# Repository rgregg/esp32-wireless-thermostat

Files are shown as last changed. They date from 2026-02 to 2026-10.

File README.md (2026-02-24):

# ESP32 Wireless Thermostat

A two-unit wireless HVAC thermostat system built on ESP32. A **controller** board wired to your furnace manages relay outputs for heating, cooling, and fan. A **touchscreen display** mounted on the wall provides the user interface. The two units communicate wirelessly over ESP-NOW and coordinate through MQTT for Home Assistant integration.

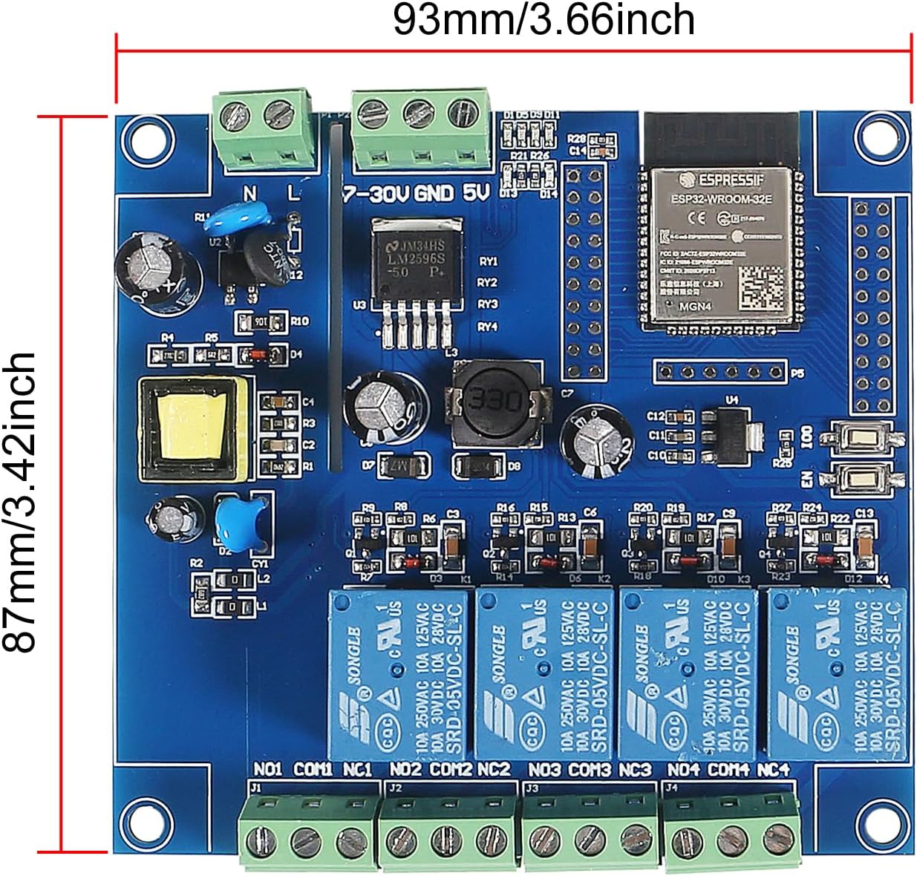
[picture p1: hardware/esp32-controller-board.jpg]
Controller Board


## Features

- **Touchscreen UI** — 4.3" 800x480 capacitive display with home, fan, mode, and settings pages plus an idle screensaver
- **Wireless** — ESP-NOW for fast local command/telemetry between controller and display; no wiring between the two units
- **Home Assistant** — MQTT discovery automatically registers a climate entity with mode, fan, and target temperature controls
- **Safety first** — Failsafe timeout, relay interlocking, minimum run/off timers, HVAC lockout, and command sequence validation
- **OTA updates** — ArduinoOTA, web-based upload (`/update`), and automatic firmware rollback if connectivity isn't restored within 3 minutes
- **Weather display** — Outdoor temperature and conditions via PirateWeather API
- **Runtime configuration** — Web UI at `/config` and MQTT topics for WiFi, MQTT, ESP-NOW, display, and weather settings without reflashing
- **Filter tracking** — Accumulated fan runtime with reset capability
- **Temperature compensation** — Configurable offset for the indoor sensor
- **BLE WiFi provisioning** — Automatic fallback to Bluetooth provisioning if no stored WiFi credentials are found
- **Desktop simulators** — SDL2-based previews of both the controller and thermostat display for development without hardware

## Hardware

### Controller Unit

Installed near the furnace. Connects to HVAC wiring via relay outputs (heat, cool, fan, spare).

| Component | Link |
|---|---|
| ESP32 4-relay controller board | [Amazon](https://www.amazon.com/dp/B0DNYYXQ3X) |
| AC-to-DC power supply (furnace side) | [Amazon](https://www.amazon.com/dp/B08Q81Y8NM) |
| 3D-printable enclosure | [`enclosures/controller_v20.f3d`](enclosures/controller_v20.f3d) |

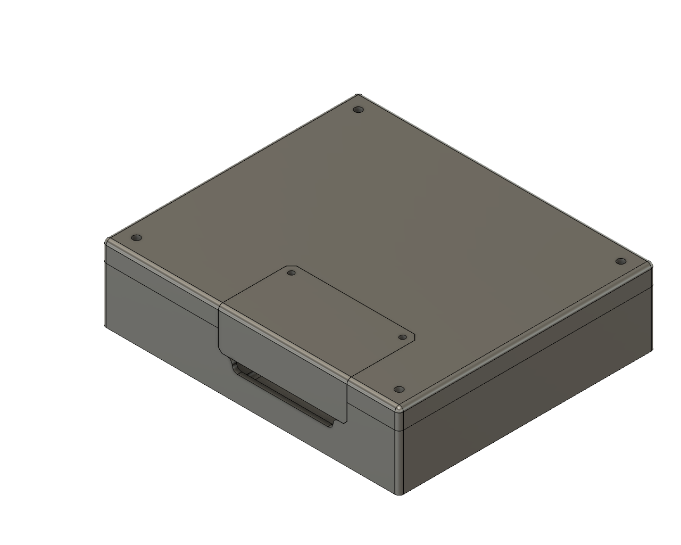
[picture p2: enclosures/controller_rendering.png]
Controller Enclosure


### Thermostat Display Unit

Wall-mounted touchscreen with built-in temperature/humidity sensor.

| Component | Link |
|---|---|
| ESP32-S3 4.3" capacitive touch display | [Amazon](https://www.amazon.com/dp/B0CLGCMWQ7) |
| AHT10/AHT20 temperature & humidity sensor | [Amazon](https://www.amazon.com/dp/B092495GZJ) |
| 3D-printable enclosure | [`enclosures/display_v27.f3d`](enclosures/display_v27.f3d) |

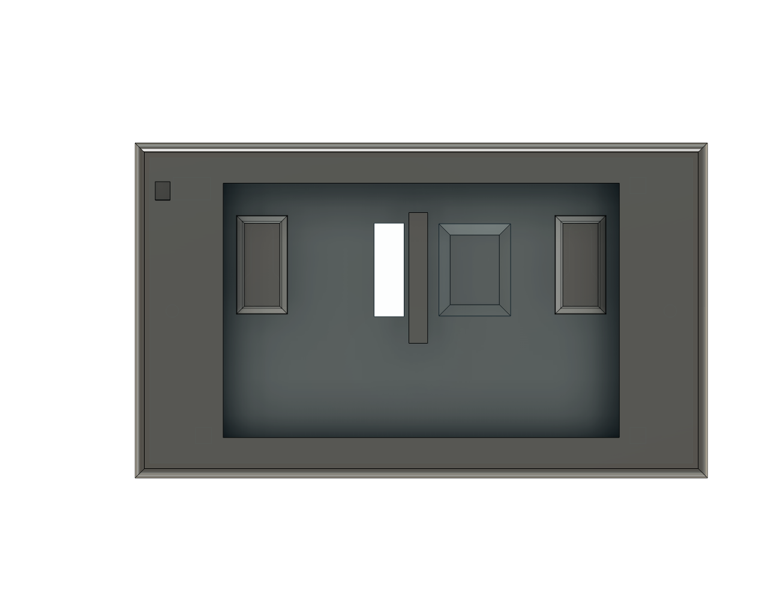
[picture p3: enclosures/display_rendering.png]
Display Enclosure


The sensor connects to the display board via I2C (SDA=GPIO 18, SCL=GPIO 17). See [`docs/hardware-requirements.md`](docs/hardware-requirements.md) for full GPIO pinouts and wiring details.

> **Enclosure note:** For fire safety compliance, print enclosures with a UL-listed filament such as Prusament PETG V0 or equivalent V0-rated material.

## Getting Started

### Prerequisites

- [PlatformIO](https://platformio.org/) (CLI or IDE plugin)
- An MQTT broker (e.g. Mosquitto) for Home Assistant integration
- 2.4 GHz WiFi network

### Build and Flash

```bash
# Controller firmware (ESP32)
pio run -e esp32-furnace-controller -t upload

# Thermostat display firmware (ESP32-S3)
pio run -e esp32-furnace-thermostat -t upload
```

Initial flash requires a USB connection. After that, OTA updates work over the network.

### Configuration

On first boot with no stored WiFi credentials, the thermostat display starts BLE provisioning. Use the ESP BLE Provisioning app to connect it to your network.

Once connected, configure both devices via their web UI:
- **Controller**: `http://<controller-ip>/config`
- **Display**: `http://<display-ip>/config`

Settings include WiFi, MQTT broker, ESP-NOW peer MAC and channel, temperature unit, display timeout, weather API key, and more. See [`docs/deployment-runbook.md`](docs/deployment-runbook.md) for the full configuration reference.

## MQTT & Home Assistant

Both units connect to an MQTT broker. The thermostat display publishes Home Assistant MQTT discovery messages, automatically creating a climate entity.

**Command topics** (under the controller's base topic):

| Topic | Values |
|---|---|
| `cmd/mode` | `off`, `heat`, `cool` |
| `cmd/fan_mode` | `auto`, `on`, `circulate` |
| `cmd/target_temp_c` | float (Celsius) |
| `cmd/lockout` | `0`, `1` |
| `cmd/filter_reset` | `1` |
| `cmd/sync` | `1` |

## Desktop Simulators

Both simulators run on your desktop for UI development and testing without hardware. They communicate over MQTT, so you can run them together with a local broker to test the full command/telemetry loop.

**Requirements:** SDL2 (`brew install sdl2 sdl2_ttf` on macOS) and optionally Mosquitto (`brew install mosquitto`).

```bash
# Thermostat display preview
pio run -e native-ui-preview && .pio/build/native-ui-preview/program

# Controller preview
pio run -e native-controller-preview && .pio/build/native-controller-preview/program
```

**Display simulator controls:**
| Key | Action |
|---|---|
| `W` | Cycle weather conditions |
| `[` / `]` | Adjust outdoor temperature |
| `S` | Activate screensaver |
| `D` | Wake display |

## Build Targets

| Environment | Description |
|---|---|
| `esp32-furnace-controller` | Controller firmware for ESP32 |
| `esp32-furnace-thermostat` | Display firmware for ESP32-S3 |
| `native-tests` | 37 unit tests (run with `.pio/build/native-tests/program`) |
| `native-ui-preview` | Desktop thermostat display simulator |
| `native-controller-preview` | Desktop controller simulator |

## Documentation

- [`docs/hardware-requirements.md`](docs/hardware-requirements.md) — GPIO pinouts, board specs, wiring
- [`docs/deployment-runbook.md`](docs/deployment-runbook.md) — Runtime configuration, MQTT topics, first-boot setup
- [`docs/system-spec-and-parity.md`](docs/system-spec-and-parity.md) — System specification and feature tracking
- [`docs/espnow-transport.md`](docs/espnow-transport.md) — ESP-NOW packet protocol details

## License

This project is provided as-is for personal and educational use. HVAC wiring involves line voltage — follow your local electrical codes and consult a qualified technician if needed.

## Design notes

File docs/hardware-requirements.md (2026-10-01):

# Hardware Requirements

This project runs as two separate ESP32 firmwares:
- `esp32-furnace-controller` (furnace-side controller)
- `esp32-furnace-thermostat` (touch display thermostat)

This document captures the hardware baseline required by the current codebase.

## Controller Unit (`esp32-furnace-controller`)

### Board/MCU
- ESP32 (classic) board profile compatible with PlatformIO `board = esp32dev`.
- 2.4 GHz Wi-Fi required (also used by ESP-NOW).
- Reference tested unit: ESP32 relay controller board (Amazon ASIN `B0DNYYXQ3X`).

### Power
- Reference tested furnace-side supply: AC-to-DC converter module (Amazon ASIN `B08Q81Y8NM`).
- Size/output the converter for the relay board + ESP32 load with startup margin.

### Required GPIO Outputs
The controller relay driver uses these default output pins:

| Function | GPIO |
|---|---|
| Heat relay | 32 |
| Cool relay | 33 |
| Fan relay | 25 |
| Spare relay | 26 |

Notes:
- Outputs default to active-high (`inverted = false` in `ControllerRelayIoConfig`).
- Relay outputs are software interlocked (heat: 500 ms, others: 1000 ms).
- Use an external relay/interface stage suitable for your HVAC control voltage and isolation needs.

## Thermostat Display Unit (`esp32-furnace-thermostat`)

### Board/MCU
- ESP32-S3 board profile compatible with PlatformIO `board = esp32-s3-devkitc-1`.
- 16 MB flash (matches `board_upload.flash_size = 16MB` build config).
- PSRAM required (framebuffers and LVGL draw buffers allocate in SPIRAM when available).
- Reference tested unit: DIYmalls `ESP32-8048S043C-I` 4.3" capacitive display module (Amazon ASIN `B0CLGCMWQ7`).

### Display Panel
- 800x480 RGB panel (16-bit parallel RGB interface).
- Current timing/pin map is implemented for the `ESP32-8048S043C-I` wiring used by this project.

RGB control pins:

| Signal | GPIO |
|---|---|
| DE | 40 |
| PCLK | 42 |
| VSYNC | 41 |
| HSYNC | 39 |

RGB data pins (`D0..D15`):
`45, 48, 47, 21, 14, 5, 6, 7, 15, 16, 4, 8, 3, 46, 9, 1`

### Touch Controller
- GT911 capacitive touch controller (`I2C addr 0x5D`)
- I2C bus pins: `SDA=19`, `SCL=20` (400 kHz)

### Indoor Sensor
- AHT10 temperature/humidity sensor (Amazon ASIN `B092495GZJ`)
- I2C bus pins: `SDA=18`, `SCL=17` (100 kHz)
- Firmware uses the Adafruit AHTX0 driver layer, so AHT10/AHT20-class devices are supported.

### Backlight
- PWM backlight control on `GPIO2` (LEDC, 8-bit, 250 Hz). The driver needs ~30 µs per enable pulse, so ultrasonic PWM cannot dim (black below ~80% at 25 kHz); 800 Hz whined audibly at low duty.

## Shared Requirements (Both Units)
- 2.4 GHz Wi-Fi coverage at install location.
- ESP-NOW enabled on both devices (default channel `6` on both).
- If using encrypted ESP-NOW, configure unicast peer MACs and a shared 16-byte LMK on both units.

## Enclosures (3D Print Files)
- Controller enclosure CAD: [`enclosures/controller_v20.f3d`](../enclosures/controller_v20.f3d)
- Thermostat display enclosure CAD: [`enclosures/display_v27.f3d`](../enclosures/display_v27.f3d)
- For fire compliance, print with a UL-listed filament such as Prusament PETG V0 (or equivalent UL-listed V0-rated material).

## Out of Scope in Current Firmware
The firmware currently does not prescribe:
- exact relay module part number,
- enclosure/thermal/mechanical constraints.

Those should be defined per installation and local electrical code requirements.

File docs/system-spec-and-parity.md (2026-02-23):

# System Spec And Parity Matrix

This document is the formal baseline spec for the thermostat/display + controller system, derived from the ESPHome YAML configuration, with a parity check against the current PlatformIO implementation.

## Scope

Baseline sources:
- `../esphome-sheridan/furnace-controller.yaml`
- `../esphome-sheridan/furnace-display.yaml`
- `../esphome-sheridan/lvgl-ux/ux-thermostat.yaml`
- `../esphome-sheridan/templates/esp32-8048S043C.yaml`
- `../esphome-sheridan/templates/management-defaults.yaml`
- `../esphome-sheridan/espnow/espnow-controller.yaml`
- `../esphome-sheridan/espnow/espnow-thermostat.yaml`

Port under evaluation:
- `.`

Status legend:
- `Implemented`: behavior is present and wired in current firmware.
- `Partial`: some behavior exists, but parity or wiring is incomplete.
- `Missing`: behavior is not implemented in the current port.

## Controller Spec And Parity

| ID | Requirement (from ESPHome behavior) | Status | Current implementation notes |
|---|---|---|---|
| C-01 | Accept thermostat command word and reject stale/duplicate sequence values. | Implemented | `ControllerRuntime::apply_remote_command` enforces sequence freshness (`espnow_cmd::is_newer_seq`). |
| C-02 | Track heartbeat freshness and enter failsafe after timeout (`failsafe_timeout_ms`). | Implemented | Runtime failsafe timeout implemented in `ControllerRuntime::update_failsafe`. |
| C-03 | In failsafe or lockout, all demands must be forced off. | Implemented | Runtime clears heat/cool/fan in `apply_hvac_calls` and `enforce_safety_interlocks`. |
| C-04 | Thermostat control loop must enforce min run/off/idle timing. | Implemented | `ControllerConfig` now includes min run/off/idle; state machine enforced in `ControllerRuntime`. |
| C-05 | Thermostat call logic should use deadband + overrun style behavior. | Implemented | `ControllerApp::compute_hvac_calls` uses configurable `heat_deadband/overrun` and `cool_deadband/overrun`. |
| C-06 | Fan modes: `automatic`, `always on`, `circulate`. | Implemented | Fan mode encoded/decoded and applied in runtime/app logic. |
| C-07 | Circulate scheduler should run windowed duty cycle based on period/duration minutes. | Implemented | Minute scheduler exists in `ControllerRuntime::run_minute_tasks`. |
| C-08 | Filter runtime increments while system is actively running and supports reset. | Partial | Runtime and reset are implemented; `spare_relay_4` participation is logical only (no physical output layer yet). |
| C-09 | Publish controller telemetry (`state`, `filter_runtime`, `lockout`, `mode`, `fan`, `setpoint`). | Implemented | `ControllerApp::publish` and `EspNowControllerTransport::publish_telemetry`. |
| C-10 | Relay demands must drive physical outputs on GPIO32/33/25/26 with startup-safe defaults. | Implemented | `controller_relay_io.cpp` GPIO output layer drives relay pins with startup-safe defaults. |
| C-11 | Enforce relay interlock behavior equivalent to ESPHome relay interlock group. | Implemented | Timed interlock delays enforced in relay IO layer (heat 0.5s, others 1s). |
| C-12 | Local lockout entity should remain externally controllable and reflected in telemetry/state text. | Partial | Lockout behavior exists in runtime; no Home Assistant/API entity equivalent on controller firmware yet. |
| C-13 | Preserve last-known indoor temp/humidity fallback behavior when remote values are missing. | Missing | Controller currently uses latest received values only; no persisted fallback store like ESPHome template numbers. |

## Display/Thermostat Spec And Parity

| ID | Requirement (from ESPHome behavior) | Status | Current implementation notes |
|---|---|---|---|
| D-01 | 800x480 RGB panel on 8048S043C pin/timing map. | Implemented | RGB panel config/pins/timings set in `esp32s3_thermostat_firmware.cpp`. |
| D-02 | GT911 touch input on internal I2C bus. | Implemented | GT911 read/write + LVGL indev callback wired. |
| D-03 | AHT20 temperature/humidity sensor on external I2C bus with 60s polling. | Implemented | AHT20 initialized on external I2C and polled every 60s. |
| D-04 | Local temperature compensation offset before publishing indoor temp. | Implemented | `temp_comp_c` runtime config applied in thermostat firmware before publishing indoor temperature. |
| D-05 | Local mode/fan/setpoint changes publish command word to controller. | Implemented | UI callbacks call runtime/app command publish path. |
| D-06 | Ignore remote setpoint updates for ~5s after local interaction (debounce). | Implemented | `ThermostatApp` enforces local interaction debounce window. |
| D-07 | Temperature unit preference (`fahrenheit`/`celsius`) drives conversions and UI format. | Implemented | `DisplayModel` and runtime unit handling implemented. |
| D-08 | Receive controller telemetry and map to user-visible status/mode/fan/setpoint. | Implemented | `ThermostatNode` + `ThermostatApp` + `ThermostatDisplayApp` flow implemented. |
| D-09 | LVGL pages and interactions for Home/Fan/Mode/Settings/Screensaver. | Partial | Core pages and actions implemented; UI is functional but not a 1:1 parity copy of all YAML widgets/details. |
| D-10 | Screen idle behavior: dim backlight, switch to screensaver, resume on touch. | Implemented | `ThermostatScreenController` + backlight dim/restore in firmware loop. |
| D-11 | Trigger sync/filter-reset actions from Settings UI. | Implemented | UI buttons call `request_sync` and `request_filter_reset`. |
| D-12 | Weather/outdoor data should come from Home Assistant entities. | Implemented | PirateWeather API integration polls weather directly on display firmware using configured API key + ZIP code. |
| D-13 | Display diagnostics in settings (IP/MAC/SSID/channel/RSSI/firmware). | Partial | Diagnostics expanded in settings page (IP, RSSI, firmware version, uptime); not all ESPHome YAML fields surfaced yet. |
| D-14 | On boot, request/refresh state from controller. | Partial | Runtime starts transport and receives telemetry; explicit boot-time `get_data_from_controller` equivalent is limited. |

## Transport And Integration Spec And Parity

| ID | Requirement (from ESPHome behavior) | Status | Current implementation notes |
|---|---|---|---|
| T-01 | ESP-NOW heartbeat ping/pong between controller and display. | Implemented | Both transport adapters send/consume heartbeat packets. |
| T-02 | Command word bit contract must remain stable (mode/fan/setpoint/seq/sync/filter_reset). | Implemented | Codec in `espnow_cmd_word.*` preserved and test-covered. |
| T-03 | Indoor temperature and humidity packets sent display -> controller. | Implemented | Thermostat transport publishes float-value packets. |
| T-04 | Controller telemetry packets sent controller -> display. | Implemented | Controller transport sends telemetry packet structure. |
| T-05 | Peer/channel/encryption settings should match deployed devices. | Partial | Config fields exist, but defaults are zero peer MAC until user/site config sets real values. |

## Home Assistant/Management Spec And Parity

| ID | Requirement (from ESPHome behavior) | Status | Current implementation notes |
|---|---|---|---|
| H-01 | Expose thermostat control/status to Home Assistant. | Implemented | MQTT HA discovery + climate command/state topics added in thermostat firmware. |
| H-02 | Provide local fallback management interfaces (API/web/captive portal/OTA) similar to ESPHome templates. | Partial | Web config UI and web-based OTA upload at `/update` implemented; no captive portal or ESPHome native API equivalent. |
| H-03 | Keep credentials/secrets out of repo. | Implemented | `platformio_override.ini` is ignored; example file added for local credential overrides. |

## Validation Spec

| ID | Requirement | Status | Current implementation notes |
|---|---|---|---|
| V-01 | Native tests validate codec, controller runtime/app, thermostat app, display model, screen logic. | Implemented | `native-tests` currently runs 37 tests and passes. |
| V-02 | Build matrix must pass for host + controller + display targets. | Implemented | `native`, `native-tests`, `esp32-furnace-controller`, `esp32-furnace-thermostat` pass. |
| V-03 | Hardware-in-loop verification for controller relays/display touch/panel/sensors. | Partial | `docs/hil-checklist.md` provides a manual pass/fail checklist; not yet automated. |

## Parity Summary

- `Implemented`: core safety state machine, command protocol, transport path, display runtime, HA MQTT bridge, relay GPIO layer, weather integration, temperature compensation, web config UI, and web OTA.
- `Partial`: some display diagnostics not fully surfaced, captive portal not implemented, HIL checklist exists but not automated.
- `Missing`: ESPHome native API equivalent, captive portal, persisted indoor temp fallback on controller.

## Highest-Priority Remaining Gaps

1. Close remaining LVGL settings/diagnostic parity items (full ESPHome YAML diagnostic field set).
2. Add persisted indoor temp/humidity fallback on controller (C-13).
3. Automate hardware-in-loop verification (V-03).

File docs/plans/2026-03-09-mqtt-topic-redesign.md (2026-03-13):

# MQTT Topic Redesign

> **Status: Implemented** — This design was implemented in the `mqtt-refactor` branch (Tasks 1-10).

## Problem

The current MQTT structure splits topics across three unrelated prefixes:
- `thermostat/furnace-controller` — controller state/cmd/cfg
- `thermostat/furnace-display` — display state/cmd/cfg
- `wireless_thermostat_system/devices` — peer discovery

Devices reference each other through hardcoded base topic config keys
(`display_mqtt_base_topic`, `controller_base_topic`). This is fragile,
requires manual configuration, and scatters related data across the broker.

## Design

### Unified Topic Hierarchy

All topics move under a single configurable base topic (default
`esp32-wireless-thermostat`). Each device publishes and subscribes under
its own MAC-based path:

```
{base_topic}/devices/{MAC}/
  announce              ← role, firmware version (retained)
  state/{key}           ← runtime state (retained, except packed_command)
  cfg/{key}/state       ← config values (retained)
  cfg/{key}/set         ← config updates (subscribed)
  cmd/{command}         ← commands (subscribed)
  sensor/{measurement}  ← sensor readings
```

### Controller Topics (`devices/{ctrl_MAC}/`)

Commands (subscribed):
- `cmd/mode` — "off", "heat", "cool"
- `cmd/fan_mode` — "auto", "on", "circulate"
- `cmd/target_temp_c` — float
- `cmd/lockout` — "0" or "1"
- `cmd/packed_word` — uint32 decimal string
- `cmd/sync` — "1"
- `cmd/reboot` — "1"
- `cmd/reset_sequence` — "1"
- `cmd/filter_reset` — "1"
- `cmd/primary_sensor_mac` — MAC string
- `cmd/espnow_only` — "0" or "1"

State (published, retained):
- `state/availability` — "online" (LWT: "offline")
- `state/mode`, `state/fan_mode`, `state/target_temp_c`
- `state/current_temp_c`, `state/current_humidity`
- `state/furnace_state` — "Idle", "Heating", "Cooling", etc.
- `state/lockout` — "0" or "1"
- `state/relay_heat`, `state/relay_cool`, `state/relay_fan` — "ON"/"OFF"
- `state/filter_runtime_hours`, `state/filter_change_required`
- `state/max_runtime_exceeded`
- `state/outdoor_temp_c`, `state/outdoor_condition`
- `state/firmware_version`, `state/boot_count`, `state/reset_reason`
- `state/uptime_s`, `state/free_heap_bytes`, `state/wifi_rssi`
- `state/last_mqtt_command_ms`, `state/last_espnow_rx_ms`
- `state/espnow_send_ok_count`, `state/espnow_send_fail_count`
- `state/error_mqtt`, `state/error_ota`, `state/error_espnow`
- `state/allow_ha`, `state/mqtt_enabled`, `state/espnow_enabled`
- `state/audit` — not retained

### Display Topics (`devices/{disp_MAC}/`)

Commands (subscribed):
- `cmd/reboot` — "1"
- `cmd/reset_sequence` — "1"
- `cmd/display_timeout_s` — integer
- `cmd/backlight_active_pct` — integer
- `cmd/backlight_screensaver_pct` — integer
- `cmd/temp_comp_c` — float
- `cmd/unit` — "c" or "f"

State (published, retained unless noted):
- `state/availability` — "online" (LWT: "offline")
- `state/packed_command` — uint32 (NOT retained)
- `state/command_seq` — integer (NOT retained)
- `state/mode`, `state/fan_mode`, `state/target_temp_c` — mirror of local UI
- `state/current_temp_c`, `state/current_humidity`
- `state/temp_comp_c`, `state/display_timeout_s`
- `state/backlight_active_pct`, `state/backlight_screensaver_pct`
- `state/firmware_version`, `state/boot_count`, `state/reset_reason`
- `state/uptime_s`, `state/free_heap_bytes`, `state/wifi_rssi`
- `state/wifi_ip`, `state/wifi_mac`, `state/wifi_ssid`, `state/wifi_channel`
- `state/connection_path`, `state/status`
- `state/last_mqtt_command_ms`, `state/last_espnow_rx_ms`
- `state/espnow_send_ok_count`, `state/espnow_send_fail_count`
- `state/error_mqtt`, `state/error_ota`, `state/error_espnow`

Sensor data (published):
- `sensor/temp_c` — float
- `sensor/humidity` — float

### Device Discovery & Authorization

**Announce:** Each device publishes a retained message on connect to
`{base_topic}/devices/{MAC}/announce` containing role (`controller`,
`display`, `sensor`), firmware version, and configurable device name
(from `device_name` config key).

**Controller authorization:**
- Maintains a list of authorized device MACs (existing `devices` config)
- Only accepts packed commands and sensor data from authorized MACs
- If the authorized list is empty, auto-registers the first device
  discovered via MQTT announce or ESP-NOW
- Unknown devices are ignored once any device is registered

**Display pairing:**
- Subscribes to `{base_topic}/devices/+/announce`, filters for
  `role=controller`
- Existing UI lets user select which controller to pair with
- Stores selected controller MAC in config; constructs controller topic
  path as `{base_topic}/devices/{ctrl_MAC}/...`

**Cross-device topic construction:** Both devices derive peer paths from
`{base_topic}/devices/{peer_MAC}/...`. The separate `display_mqtt_base_topic`
and `controller_base_topic` config keys are removed.

### Home Assistant Discovery

- Stays under `homeassistant/` prefix (required by HA)
- All `state_topic`, `command_topic` references in discovery payloads
  point to new `{base_topic}/devices/{MAC}/...` paths
- New config key `ha_discovery_enabled` (boolean, default `true`) to
  toggle HA discovery on/off
- `discovery_prefix` config key retained (default `homeassistant`)

### Config Key Changes

**Removed:**
- `mqtt_base_topic` — replaced by `base_topic` + device MAC
- `display_mqtt_base_topic` — replaced by peer MAC discovery
- `controller_base_topic` — replaced by peer MAC discovery
- `mqtt_client_id` — auto-generated as `{base_topic}-{MAC}`

**New:**
- `base_topic` — default `esp32-wireless-thermostat`
- `ha_discovery_enabled` — boolean, default `true`
- `device_name` — string, default auto-generated as `{role}-{last3MAC}`
  (e.g. `controller-29A9C4`, `display-55D0E8`). Used in announce payload
  and HA discovery as device display name.

**Unchanged:** WiFi, MQTT broker host/port/user/password, ESP-NOW,
OTA, weather, display settings, `discovery_prefix`, `devices`.

### What Doesn't Change

- ESP-NOW protocol (MQTT-only change)
- Packed command 24-bit word encoding
- Per-MAC sequence tracking
- Web server endpoints (`/status`, `/config`, `/update`, `/screenshot`)
- Failsafe / isolation reboot logic (monitors new paths)
- OTA rollback mechanism

### Migration

Clean break. New firmware uses only new topics. A cleanup script
(`scripts/mqtt_cleanup_old_topics.py`) clears retained messages from
the old `thermostat/furnace-controller/...`, `thermostat/furnace-display/...`,
and `wireless_thermostat_system/...` paths.

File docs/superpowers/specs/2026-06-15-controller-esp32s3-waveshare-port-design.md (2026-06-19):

# Controller Port → Waveshare ESP32-S3-ETH-8DI-8RO — Design Spec

**Date:** 2026-06-15
**Branch:** `feat/controller-esp32s3-port`
**Status:** Approved design → implementation planning

## Goal

Port the furnace **controller** firmware from the current classic-ESP32 board
(`esp32dev`, 4 MB) to the Waveshare **ESP32-S3-ETH-8DI-8RO** (CAN/PoE variant),
and use the move to fix the chronic instability we've been fighting:

- **More flash (16 MB)** → a dedicated coredump partition, so we can finally
  capture the `panic` backtrace we currently can't see (no serial, 4 MB full).
- **Wired Ethernet** → remove the marginal-WiFi link that drives the
  `task_wdt` / weather-wedge failures (controller RSSI seen as low as −92 dBm).
- **Resilience refactor** → make the furnace control path independent of the
  network so network trouble can never stop heating/cooling or crash the device.

The display is **out of scope** except for one required change (ESP-NOW peer +
channel, see §6).

## Confirmed decisions

| Decision | Choice |
|---|---|
| Scope | Port **+ coredump + resilience** (all three) |
| IP transport | **Ethernet for IP** (MQTT/HA/weather); WiFi radio used **only for ESP-NOW**, no AP association |
| HA identity | **Preserve** — override discovery device id so HA sees the same controller device |
| Digital inputs (8× DI) | **Reserved, unused** this pass (YAGNI) |
| Old board | **Kept building** via a relay-backend abstraction (working fallback throughout) |

## Target hardware

**Waveshare ESP32-S3-ETH-8DI-8RO-C** — ESP32-S3-WROOM-1U **N16R8** (CONFIRMED on
hardware: 16 MB flash, 8 MB PSRAM, MAC 3c:0f:02:cc:ee:2c).

- **Relays (8):** PCA9554 I²C expander @ `0x20`, **active-high** — **VERIFIED on
  hardware** (bring-up: relay N = bit `1<<N`; boot-safe state confirmed off). I²C `SDA=42, SCL=41`.
- **RTC:** **PCF85063** @ I²C `0x51` (same bus) — **found on hardware.** Battery/supercap
  backed timekeeping; see §7.
- **Ethernet:** W5500 over SPI — `CLK=15, MOSI=13, MISO=14, CS=16, INT=12` (RST: verify on hardware).
- **Digital inputs (8):** GPIO 4–11, `INPUT_PULLUP`, inverted, debounced (reserved, unused).
- **Misc:** RGB LED (WS2812) GPIO38, buzzer GPIO46, boot button GPIO0.
- **Power:** 7–36 V DC screw terminal, USB-C (power/flash/debug), PoE (this SKU).

## Approach

**Phased, single branch, behind a board abstraction.**

- **Phase 1 (no hardware):** resilience refactor + relay-backend abstraction +
  coredump scaffolding, developed and **unit-tested in native**. The current
  `esp32dev` controller keeps building on the GPIO backend and gains the
  resilience improvements immediately.
- **Phase 2 (on hardware):** new `esp32-furnace-controller-s3` env — PCA9554
  relay backend, W5500 Ethernet, fixed-channel ESP-NOW, coredump partition,
  identity override. Validate on the bench, then swap per the flashing runbook.

Rejected: S3-only hard switch (no fallback, can't land resilience on the current
board now); separate branch per subsystem (resilience and Ethernet both touch the
network layer → merge friction).

## Build configuration (one codebase, two boards)

Board differences are isolated behind compile-time-selected backends; everything
else is shared. Selected via PlatformIO env + build flag (e.g. `-D CONTROLLER_BOARD_S3`).

| Concern | `esp32-furnace-controller` (old, esp32dev / 4 MB) | `esp32-furnace-controller-s3` (new, S3 / 16 MB) |
|---|---|---|
| Relay backend | `GpioRelayBackend` (direct GPIO) | `Pca9554RelayBackend` (I²C @0x20) |
| IP link | `WiFiStation` backend (associates to AP) | `Ethernet` (W5500) backend |
| ESP-NOW | WiFi radio, AP-driven channel | WiFi radio, no association, pinned channel |
| Partitions | `partitions_no_spiffs.csv` (4 MB) | custom 16 MB + coredump |
| Panic-PC breadcrumb (RTC) | available | available |
| Full coredump (flash) | unavailable (no partition) | enabled |
| **Shared** | control loop, thermostat logic, resilience refactor, ESP-NOW protocol, MQTT/HA discovery, weather, relay interlock logic (`ControllerRelayIo`) | same |

Note: the networking *model* (Ethernet-for-IP + WiFi-for-ESP-NOW-only) applies to
the **new** board only; the old board has no Ethernet and necessarily keeps
WiFi-station association for IP. The `IP-link` abstraction (§2) resolves to
`WiFiStation` on the old board and `Ethernet` on the new one, keeping the MQTT/
weather layers board-agnostic.

## Design

### 1. Hardware abstraction — relays
- Introduce a `RelayBackend` interface; `ControllerRelayIo` keeps **all** its
  interlock / force-off / pending logic unchanged and calls the backend for
  `begin()` + `write_outputs()`.
- `GpioRelayBackend` — current board (direct GPIO, existing behavior).
- `Pca9554RelayBackend` — I²C @ `0x20`, active-high. **Safe init: write output
  register `0x00` BEFORE setting the config register to outputs**, so the
  input→output transition cannot momentarily energize relays (PCA9554 output
  reg POR default is `0xFF`).
- Byte-packing (relay index → bit in the output byte) extracted to a
  platform-agnostic, **unit-tested** header (per the sim/firmware split); the
  `Wire` transport stays in firmware.
- Backend selected by build flag / PlatformIO env.

### 2. Networking
- **Ethernet (W5500)** is the IP path for MQTT/HA/weather. A small **IP-link
  abstraction** lets MQTT/weather code be link-agnostic.
- **WiFi radio** is initialized in a **no-association mode pinned to a fixed
  ESP-NOW channel** (no STA join). This removes the flaky WiFi-association layer
  entirely while keeping the local ESP-NOW link to the display.
- ⚠️ **ESP-NOW channel-coordination risk:** ESP-NOW requires controller and
  display on the same radio channel. Today they match because both associate to
  the same AP. Once the controller stops associating and pins a channel, the
  **display's AP must use that channel, or the display must pin the same channel**
  (small display-side follow-up). The controller will expose the ESP-NOW channel
  as config; verify channel match at cutover. Mitigation if mismatch is a problem:
  pin the display too / move display to Ethernet later.

### 3. Resilience refactor
- **Control loop** runs at a fixed cadence with **zero network dependency**
  (read indoor temp via ESP-NOW → compare setpoint → drive relays).
- **Move MQTT connect/publish off the main path** into a dedicated network task
  (weather already is). The main loop never blocks on the network.
- **Replace `esp_restart()` recoveries with subsystem restarts.** Use a
  self-terminating network task (checks a flag and returns cleanly so TLS objects
  run their destructors) instead of `vTaskDelete` — so we recover networking
  without rebooting. Reserve reboot for truly unrecoverable states, and avoid
  rebooting mid HVAC cycle where possible.
- **Degradation tiers:** control > ESP-NOW > MQTT/HA > weather. A failure in any
  tier must not affect the tiers below it.
- **Bounded everything** (carry forward PR #32: connect/handshake/read timeouts,
  task-WDT, MQTT socket timeout) + backoff with jitter + heap budget under failure.
- **Relay fault policy:** the PCA9554 **latches relay state across a CPU reset**
  (it doesn't reset when the ESP32 does) — deliberately chosen so a watchdog
  reboot doesn't drop an active heat/cool call. Document and make explicit.

### 4. Crash diagnostics (unified — three layers)
A single crash-visibility story, layered by what each board can hold:

1. **`wdt_section` breadcrumb (existing, both boards):** names the instrumented
   blocking section (weather geocode/forecast, mqtt connect, mdns) active at a
   watchdog reset. RTC_NOINIT memory.
2. **Panic-PC breadcrumb (new, both boards):** a custom panic-handler hook stashes
   the **faulting PC + a few backtrace addresses** into RTC_NOINIT memory (survives
   panic/reset, same mechanism as the existing breadcrumb), published on next boot
   via a new `state/panic_pc` topic + HA diagnostic sensor, then cleared. Resolve
   offline with `addr2line` against the matching build `.elf` (rebuildable from the
   firmware_version git sha). Gives the **old 4 MB board** crash *localization*
   without needing a coredump partition.
3. **Full coredump (new board only):** custom 16 MB partition table with a
   dedicated coredump partition; `esp_core_dump` to flash, panic-triggered. On boot
   read the summary (PC + backtrace + registers/stack), publish over MQTT
   (`state/coredump`), then clear. The complete dump the 4 MB board can't hold.

### 5. Identity & migration
- **Override the discovery device id / base** so HA continues to see the same
  controller device — existing automations, the reboot alert, history, and
  dashboards keep working with no entity_id rework.
- **Update the display's ESP-NOW peer** to the new controller MAC (and confirm
  channel per §2).
- **Cutover:** bench-flash the new board → validate (see §6) → HVAC-off + 60 s
  settle → physically swap → verify. Old board retained as rollback.

### 6. Testing
- **Native unit tests:** relay bit-logic; resilience state machines (link up/down,
  network-task restart, degradation tiers); IP-link selection; coredump-record
  parsing; panic-PC breadcrumb encode/decode/format; **RTC time encode/decode (BCD)**.
- **Hardware validation checklist (Phase 2):** relay **safe state at power-on**
  (multimeter COM→NO before wiring to HVAC), Ethernet link + DHCP, ESP-NOW channel
  match with display, coredump capture→publish→clear round-trip, OTA on the new
  partition layout, full HVAC cycle (heat/cool/fan) with interlocks, **RTC read/set +
  survives a power-cycle (if battery-backed)**.

### 7. RTC — network-independent time (PCF85063 @ I²C 0x51)
The board has a **PCF85063A** RTC on the relay I²C bus. This is a genuine resilience
win: **the controller keeps accurate wall-clock time even with the network down**, so
time-dependent behavior doesn't depend on NTP/SNTP reachability.

- **Driver:** a small PCF85063 driver — read/set time over I²C. The **BCD ↔ struct
  encode/decode is platform-agnostic and unit-tested** (like the relay bit-logic);
  only the `Wire` transport is firmware. Also read the **oscillator-stop / low-voltage
  flag** (RTC reg) to know whether the held time is trustworthy (battery was lost).
- **Sync strategy — RTC is the local source of truth, NTP corrects it:**
  - On boot, read the RTC immediately → the controller has a valid time before any
    network comes up (no "1970" window, no waiting on SNTP).
  - When network time is available (SNTP sync), **write it back to the RTC** so the RTC
    stays accurate and survives the next reboot/outage.
  - System time (`settimeofday`) is seeded from the RTC at boot and re-disciplined by
    SNTP; the RTC is re-written on each successful SNTP sync (and periodically).
- **Uses:** time-of-day HVAC scheduling without NTP; accurate **log/diagnostic
  timestamps from boot** (incl. reboot-cause/breadcrumb timing); runtime accounting
  anchored to real time. Optionally publish `state/rtc_time` + an `rtc_ok` diagnostic.
- **Battery/backup:** the RTC only retains time across a full power-off if the board's
  RTC backup (coin cell / supercap) is populated — **verify/populate it** for cold-boot
  benefit; without it the RTC still helps across brownouts/resets and gets corrected by
  SNTP. The osc-stop flag tells us at boot whether to trust the held time.
- **Display-agnostic:** controller-only (the display gets time over ESP-NOW/MQTT as today).

## Out of scope
- Digital-input features (reserved, unused).
- RS485/CAN bus usage.
- Moving the display to Ethernet (possible later follow-up for ESP-NOW channel).
- PoE infrastructure (board supports it; power method is an install choice).

## Risks
- **ESP-NOW channel mismatch** once the controller stops associating (see §2) —
  highest-attention item at cutover.
- **Exact SKU pin differences** (CAN variant) — re-verify pin map on arrival.
- **PCA9554 power-on / pre-I²C window** — board pull resistors decide raw
  power-on relay state; confirm via schematic + bench before HVAC wiring.
- Panic root cause still unknown (post-deploy `reset_reason=panic`, `wdt_section=none`,
  no backtrace available); the coredump partition is the instrument to find it, not
  a guaranteed fix.

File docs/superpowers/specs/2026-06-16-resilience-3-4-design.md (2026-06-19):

# Resilience Increments 3 & 4 — Design

> **Status: DRAFT for review.** Touches the LIVE, SHARED controller firmware
> (`src/esp32_controller_main.cpp` + `controller_*`), so it affects the production
> esp32dev controller as well as the S3 port. Get sign-off before implementing.

Grounded in a concurrency analysis of the current firmware (2026-06-16). Headline finding:
the controller's `app()` state is **already mutated concurrently without locking** — the
ESP-NOW receive callback (WiFi-stack task) calls `app().on_command_word/on_heartbeat/...`
directly, racing `loop()->tick()`. It survives only because the writes are word-atomic
scalars that self-correct each tick. There is **no reusable serialization mechanism** to
borrow, and MQTT's mutations are *worse* race candidates (an Arduino `String`
`g_disp_availability`, the device-registry array, and a multi-field shadow set).

This work is **three distinct pieces**, ordered by value/risk:

---

## Piece A — Weather wedge: PREVENT it (small, low-risk, high-value)  [was "Inc 4a"]

**Problem:** `ctrl_poll_weather` reboots (`esp_restart`) when the weather task genuinely
hangs. The hang is a **TLS handshake** that ignores the HTTP timeouts: `http.setTimeout`
and `http.setConnectTimeout` are set (4 s), but **`WiFiClientSecure::setHandshakeTimeout()`
is never called**, and there's no socket read timeout — so `mbedtls_ssl_handshake` can
block indefinitely.

**Fix (prevention, not recovery):** in `ctrl_fetch_zip_coordinates` and
`ctrl_fetch_pirateweather_current`, set `client.setHandshakeTimeout(kCtrlHttpTimeoutMs/1000)`
and a socket timeout before the request. The `WiFiClientSecure`/`HTTPClient` objects are
**stack-local**, so once every blocking call honors a timeout the function *returns*,
destructors run, no leak — the task can no longer wedge. The watchdog reboot becomes
unreachable (we keep it as a backstop but it should never fire).

**Why first:** ~10 lines, no concurrency, and (like the weather-wedge sign fix) it's shared
so production benefits immediately. Retires the genuine-hang reboot path.

**Risk:** low. Validate by confirming weather still fetches normally on the bench (needs a
valid PirateWeather key + zip configured), and that a forced-unreachable TLS host times out
and returns instead of hanging.

---

## Piece B — MQTT off the control loop via a command queue (large, the real Inc 3)

**Goal:** the control loop (core 1) must never block on MQTT connect (≤5 s), the 19-subscribe
+ discovery/state publish burst, or `PubSubClient.loop()`. Move all MQTT I/O to its own
FreeRTOS task; keep **all** `app()` mutation on the loop task.

**Approach — command queue (NOT a mutex):**
```
New MQTT task (core 0, alongside weather/web):
  owns g_ctrl_mqtt: ensure_connected / loop() / subscribe / publish.
  ctrl_mqtt_on_message: PARSE ONLY -> xQueueSend(g_ctrl_cmd_q, &CtrlCommand{...})

loop() task (core 1, unchanged role):
  at top of loop: drain g_ctrl_cmd_q (non-blocking) -> apply via the existing app()
    mutators + shadow/registry updates (single-threaded, same site as tick()).
  g_controller->tick(); g_relay_io.apply();   // unchanged — still the ONLY mutator site
```
- `CtrlCommand` = small POD tagged union (mode/fan/setpoint/lockout/windows/packed_word/
  heartbeat/indoor_temp/indoor_humidity/sync/reset_seq/...). The MQTT handler becomes a thin
  topic→command parser; the *application* logic stays where it is, just invoked from the
  drain step.
- Outbound publishes (state, discovery, announce) become "enqueue outbound" handled by the
  MQTT task — removes today's reentrant `publish()`-from-inside-its-own-callback.
- Queue depth ~16, with a dropped-command counter surfaced in telemetry (a full queue is a
  diagnosable event, never silent corruption).

**Why a queue beats a mutex (furnace-safety):** `tick()`/`compute_hvac_calls()` never see a
half-applied command (no relay glitch from torn state); FIFO preserves command ordering; the
`command_sources_` seq-dedup stays correct because it's touched from one task; and we avoid
taking a lock inside the ESP-NOW recv context (which could stall WiFi RX / invert priority
when loop holds it during an NVS write in `tick()`). `ControllerApp`/`Runtime` need **zero**
locking changes.

**Optional follow-up (not required):** route the ESP-NOW recv callback through the *same*
queue to finally retire the pre-existing ESP-NOW race. Strictly additive.

**Risk:** medium-high (it's the relay-control hot path). Mitigate with the queue design
(keeps mutation single-threaded), incremental rollout, and heavy review. Validate on bench:
commands (HA/MQTT) still apply correctly and promptly; broker outage no longer stalls the
control loop; relay decisions keep ticking during an MQTT publish burst.

---

## Piece C — Isolation reboot: recover-without-reboot (medium)  [was "Inc 4b"]

**Problem:** `loop()` calls `esp_restart()` when MQTT && ESP-NOW are both down >15 min.
**Fix:** fold this into the existing `NetworkRecoveryPolicy` escalation ladder. Add an
ESP-NOW re-init action (`esp_now_deinit()` + `EspNowControllerTransport::begin()` — re-reg
callbacks, re-add peers; `instance_`/`initialized_` already reset in `begin()`), and on
prolonged isolation escalate: MQTT reconnect → cycle ESP-NOW (+ WiFi reassoc on classic /
lwIP self-heal on Ethernet) → **only then** reboot as a true last resort. The
`RestartSubsystem` rung already exists; this wires ESP-NOW re-init into it and replaces the
blunt 15-min `esp_restart` with "restart subsystems once, reboot only if that fails."

**Risk:** medium (network re-init). Validate on bench: force prolonged isolation, confirm
ESP-NOW re-inits and recovers in place without a reboot; confirm a genuine unrecoverable
case still eventually reboots.

---

## Recommended sequence
1. **Piece A** (weather TLS handshake timeout) — quick, low-risk, ships to production now.
2. **Piece B** (MQTT command queue) — the headline; do it carefully with per-task review.
3. **Piece C** (isolation subsystem-restart) — builds on the recovery policy.

Each piece is independently shippable and independently testable on the bench (board on the
isolated test broker, ESP-NOW peer permitting for C).

## Open questions for review
1. **Scope/sequence:** do all three, or start with A (+ maybe C) and defer the larger B?
2. **MQTT task core:** core 0 (with weather/web, keeps control alone on core 1 —
   recommended) or core 1?
3. **Production rollout:** ship Piece A to prod (like the weather-wedge fix) once done, or
   batch all three behind the S3 port?

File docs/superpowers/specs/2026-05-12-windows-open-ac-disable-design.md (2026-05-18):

# Windows Open A/C Disable — Design

**Date:** 2026-05-12
**Status:** Approved — ready for implementation plan
**Scope:** Controller firmware, thermostat display firmware, sim

## Summary

Add a new boolean state, `windows_open`, owned by Home Assistant and pushed to the controller over MQTT. While the signal is active the controller suppresses cooling demand only — heat, fan, mode/setpoint changes, and all other HVAC behavior continue normally. The thermostat display surfaces a "Windows Open" message in the status line **only when the active mode is Cool**.

## Motivation

When a user opens windows/doors during cooling season, running the A/C is wasteful and uncomfortable. Home Assistant already aggregates door/window sensor state. This feature gives HA a clean, dedicated lever to disable cooling without forcing the user (or an automation) to toggle the whole HVAC mode off — which would also stop heating during shoulder seasons or unrelated cases.

## Design Decisions

| Question | Decision | Rationale |
|---|---|---|
| Source of signal | MQTT command from HA only | Mirrors existing `hvac_lockout` pattern; no controller hardware change. |
| Behavior during active cooling | Honor min-run-time, then idle | Avoids short-cycling compressor on brief door openings. |
| Scope of suppression | Cooling only | Per user request. Fan (circulate/always-on) and heat continue normally. |
| Display priority | Only show "Windows Open" when active mode is Cool | When in Heat/Off, the windows-open state is irrelevant to the user's current intent. |
| State persistence | None on controller | HA publishes the command as a retained MQTT topic; controller picks it up on reconnect. |
| Furnace state code | No new code | Suppressed-cooling-Idle is still functionally Idle; flag rides separately on snapshot. |

## Architecture

### Data flow

```
HA windows/doors aggregation
        │
        │ MQTT: {base}/devices/{ctrl_mac}/cmd/windows_open  (retained)
        ▼
Controller (ESP32)
  ControllerApp::set_windows_open(bool)
        │
        ▼
  ControllerRuntime::windows_open_  ──► suppresses cool_call in apply_hvac_calls()
        │
        │ Published in retained state JSON, included in ESP-NOW snapshot
        ▼
Thermostat Display
  parses windows_open into mirrored snapshot
        │
        ▼
  furnace_state_text() returns "Windows Open" when mode==Cool and flag set
```

### Components changed

**Shared (`include/`):**
- `thermostat_types.h` — `ThermostatSnapshot` gains `bool windows_open = false`.
- `espnow_cmd_word.h` — snapshot serializer gains one bit for `windows_open`. If no free bit exists in the current packed word, this becomes a protocol-version bump — both controller and display firmwares must be flashed in lockstep. Implementation plan must verify bit availability first.

**Controller (`src/controller/`, `include/controller/`):**
- `controller_runtime.h/.cpp`
  - New field `bool windows_open_ = false`.
  - New methods `void set_windows_open(bool)` and `bool windows_open() const`.
  - `apply_hvac_calls(now, heat_call, cool_call)`: at function entry, force `cool_call = false` if `windows_open_` is true. Existing min-run-time logic in the `Cooling` branch handles graceful shutdown.
  - `snapshot()` populates `s.windows_open`.
  - State transitions audit-logged: `"windows_open: on/off [mqtt]"`.
- `controller_app.h/.cpp` — thin pass-through `set_windows_open(bool)`.

**Controller firmware (`src/esp32_controller_main.cpp`):**
- Subscribe and handle new MQTT command topic `cmd/windows_open` (gated by `ha_allowed`, alongside `cmd/lockout`).
- Add `"windows_open": true/false` to retained runtime-state JSON.
- Add status-page HTML row "Windows Open".
- Publish HA MQTT discovery for a `switch` entity (mirroring `hvac_lockout` discovery) so HA can both drive and observe the value.

**Display (`src/thermostat/`, `include/thermostat/`):**
- `thermostat_ui_state.h/.cpp` — `furnace_state_text(...)` gains parameter `bool windows_open` and parameter `FurnaceMode mode` (or accepts the full snapshot — see plan). Returns `"Windows Open"` when `mode == FurnaceMode::Cool && windows_open` and no higher-priority state applies.
- MQTT subscriber on display parses `windows_open` from controller state JSON.
- ESP-NOW receiver path stores the bit into the mirrored snapshot.

**Sim (`src/sim/controller_preview.cpp`):**
- Toggle button for `windows_open`.
- Parse `cmd/windows_open` on the sim's MQTT bridge.
- Status overlay shows windows-open status (parity with lockout).

### Status text priority (display)

Updated order in `furnace_state_text`:

```
1. Failsafe        → "Failsafe"
2. Locked Out      → "Locked Out"
3. Not Connected   → "Not Connected"
4. mode==Cool && windows_open
                   → "Windows Open"
5. (existing state-code switch: Idle, HeatMode, HeatOn, CoolMode,
    CoolOn, FanOn, HeatWait, CoolWait, Error)
```

If `windows_open` is true but the user is in Heat or Off mode, the status reads as it would today (no "Windows Open" text). If a compressor is still finishing its min-run-time after `windows_open` goes true, the user briefly sees `"Cool on"`. Once cooling idles, the text transitions to `"Windows Open"`.

### Cooling suppression — exact semantics

In `ControllerRuntime::apply_hvac_calls(now_ms, heat_call, cool_call)`:

```cpp
if (windows_open_) {
  cool_call = false;
}
```

This goes **after** the existing `failsafe_active_ || hvac_lockout_` early-return (so those still force full idle) and **before** the state machine switch. Effect:

- **HvacState::Cooling**: existing `!cool_call && min_run_done` branch idles the compressor once min-run elapses. While min-run is unmet, cooling continues — by design.
- **HvacState::Idle**: re-entry into Cooling requires `cool_call == true`, which it never will be while `windows_open_` is set.
- **HvacState::Heating**: untouched.
- Fan-circulate logic (later in tick) is untouched and continues to run.

## Testing

Native unit tests (`src/tests/test_controller_runtime.cpp`):
1. `cool_call` is suppressed when `windows_open` is set; runtime stays in Idle.
2. `heat_call` is unaffected when `windows_open` is set.
3. Active Cooling honors min-run-time before idling on `windows_open=true`.
4. Cannot re-enter Cooling while `windows_open=true`, even after min-off-time has elapsed.
5. Fan-circulate continues to run while `windows_open=true` in Cool mode.
6. Snapshot reflects `windows_open` correctly across set/clear.

Display unit tests (`thermostat_ui_state`):
1. `"Windows Open"` returned when `mode == Cool && windows_open == true` and no higher-priority state active.
2. Higher-priority states (Failsafe, Locked Out, Not Connected) override.
3. Heat or Off mode with `windows_open == true` returns normal mode/state text.

Integration (manual / sim):
- Toggle windows-open in sim while in Cool mode; observe display status flip and compressor idle after min-run.
- HA discovery surfaces the new switch entity.

## Out of Scope

- Persistence of `windows_open` across controller reboot (HA's retained MQTT topic handles this).
- Per-zone or multiple window-sensor handling (HA aggregates upstream).
- Automatic mode switching (we never modify the user's mode selection).
- Suppressing fan when windows are open.
- Adding `windows_open` to the audit-log-only diagnostics; standard transition audit lines are sufficient.

## Open Items for Implementation Plan

1. Verify free bit in `espnow_cmd_word.h` packed snapshot word. If none, design the protocol-version bump and coordinated rollout (controller + display flashed together).
2. Confirm exact `furnace_state_text` signature change — pass `bool windows_open` + `FurnaceMode mode` as additional params, or refactor the function to take a `ThermostatSnapshot` + connection bool. Latter is cleaner; affects all callers.
3. HA discovery payload shape for `switch` entity (copy `hvac_lockout` discovery as template).

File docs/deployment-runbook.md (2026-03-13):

# Deployment Runbook

## Defaults
- MQTT host defaults to `mqtt.lan` on both devices.
- MQTT username/password default to empty.
- MQTT base topic defaults to `esp32-wireless-thermostat`. Each device publishes under `{base_topic}/devices/{MAC}/...` where `{MAC}` is the 6-character hex suffix of the device WiFi MAC address (e.g., `29A9C4`).
- ESP-NOW default channel is `6` on both devices.
- ESP-NOW default LMK is set on both devices (same 16-byte key in hex).
- ESP-NOW peer MAC default is broadcast (`FF:FF:FF:FF:FF:FF`), which keeps multicast fallback.
  - Note: ESP-NOW encryption requires a unicast peer MAC; with broadcast peer, traffic is unencrypted.
  - To enforce allowed-device communication and encrypted ESP-NOW traffic, set `espnow_peer_mac` to the other device's MAC on both devices.

## Flashing Firmware

### OTA (preferred)
- Controller: `curl -F "firmware=@firmware.bin" http://<controller-ip>/update`
- Display: `curl -F "firmware=@firmware.bin" http://<display-ip>/update`
- Both also support ArduinoOTA (hostname-based, may have password set).

### Serial
For initial flashing or recovery when OTA is unavailable.

**Display (ESP32-S3)** — auto-reset works:
```
esptool.py --chip esp32s3 --port /dev/<display-serial-port> --baud 460800 \
  --no-stub --before default-reset --after hard-reset \
  write_flash 0x10000 firmware.bin
```

**Controller (ESP32)** — auto-reset does NOT work; manually enter bootloader
by holding BOOT, pressing RESET, then releasing BOOT:
```
esptool.py --chip esp32 --port /dev/<controller-serial-port> --baud 460800 \
  --no-stub --before default-reset --after hard-reset \
  write_flash 0x10000 firmware.bin
```

> **Note:** The stub flasher fails at 921600 baud on both devices. Use
> `--no-stub` with 460800 baud.

## First Boot
1. Flash controller and display firmware.
2. Join both devices to WiFi.
3. Confirm controller connects to MQTT at `mqtt.lan:1883`.
4. Open controller web UI (`http://<controller-ip>/`) for unified settings.
5. Verify display status appears in the controller UI and apply display settings there.

## Runtime Management
- Controller local config: `http://<controller-ip>/config`
- Controller reboot endpoint: `POST http://<controller-ip>/reboot`
- Controller web OTA upload: `http://<controller-ip>/update`
- Display local fallback config: `http://<display-ip>/config`
- Display reboot endpoint: `POST http://<display-ip>/reboot`
- Display web OTA upload: `http://<display-ip>/update`
- Display screenshot: `http://<display-ip>/screenshot`
- MQTT path smoke verifier (with broker + both devices online):
  - `python3 scripts/mqtt_path_smoke.py --host mqtt.lan --ctrl-mac <CTRL_MAC> --disp-mac <DISP_MAC>`
- Old topic cleanup (one-time after migration):
  - `python3 scripts/mqtt_cleanup_old_topics.py --host mqtt.lan`
- MQTT reboot commands:
  - Controller: publish `1` to `esp32-wireless-thermostat/devices/<CTRL_MAC>/cmd/reboot`
  - Display: publish `1` to `esp32-wireless-thermostat/devices/<DISP_MAC>/cmd/reboot`
- Sequence recovery command (no reboot required):
  - Publish `1` to `esp32-wireless-thermostat/devices/<CTRL_MAC>/cmd/reset_sequence`
  - Controller resets its command sequence filter and forwards reset to display.

## Release Artifacts
- Build both firmware binaries with one command:
  - `scripts/build_release_artifacts.sh`
- Artifacts are written to `dist/releases/<git-describe-version>/`.
- Naming format:
  - `esp32-furnace-controller-<version>.bin`
  - `esp32-furnace-thermostat-<version>.bin`
- Build metadata is recorded in `build-info.txt`, and `SHA256SUMS` is generated when `shasum` is available.
- The GitHub Releases workflow automatically attaches firmware binaries to tagged releases.

## Runtime Config Contract

Config keys are set via MQTT at `{base_topic}/devices/{MAC}/cfg/<key>/set` and current values are published at `{base_topic}/devices/{MAC}/cfg/<key>/state`.

### Controller keys
| Key | Type | Default | Accepted values/range | Reboot required |
| --- | --- | --- | --- | --- |
| `wifi_ssid` | string | `""` | any | no |
| `wifi_password` | string (secret) | `""` | any | no |
| `mqtt_host` | string | `mqtt.lan` | any hostname/IP | no |
| `mqtt_port` | integer | `1883` | `1..65535` | no |
| `mqtt_user` | string | `""` | any | no |
| `mqtt_password` | string (secret) | `""` | any | no |
| `base_topic` | string | `esp32-wireless-thermostat` | any | no |
| `device_name` | string | auto-generated (`controller-{MAC}`) | any | no |
| `ha_discovery_enabled` | boolean string | `1` | `0`, `1` | no |
| `ota_hostname` | string | `esp32-furnace-controller` | any | no |
| `ota_password` | string (secret) | `""` | any | no |
| `espnow_channel` | integer | `6` | `1..14` | yes |
| `espnow_peer_mac` | string | `FF:FF:FF:FF:FF:FF` | MAC format expected | yes |
| `espnow_lmk` | string (secret) | `a1b2c3d4e5f60718293a4b5c6d7e8f90` | 32 hex chars expected | yes |

### Thermostat (display) keys
| Key | Type | Default | Accepted values/range | Reboot required |
| --- | --- | --- | --- | --- |
| `wifi_ssid` | string | `""` | any | no |
| `wifi_password` | string (secret) | `""` | any | no |
| `mqtt_host` | string | `mqtt.lan` | any hostname/IP | no |
| `mqtt_port` | integer | `1883` | `1..65535` | no |
| `mqtt_user` | string | `""` | any | no |
| `mqtt_password` | string (secret) | `""` | any | no |
| `base_topic` | string | `esp32-wireless-thermostat` | any | no |
| `device_name` | string | auto-generated (`display-{MAC}`) | any | no |
| `ha_discovery_enabled` | boolean string | `1` | `0`, `1` | no |
| `paired_controller_mac` | string | `""` | 6-char hex MAC suffix | no |
| `discovery_prefix` | string | `homeassistant` | any | no |
| `pirateweather_api_key` | string (secret) | `""` | any | no |
| `pirateweather_zip` | string | `""` | ZIP string | no |
| `display_timeout_s` | integer | `300` | clamped to `30..600` | no |
| `temp_comp_c` | float | `0.0` | any float | no |
| `temperature_unit` | string | `c` | `c`,`f`,`celsius`,`fahrenheit` | no |
| `ota_hostname` | string | `esp32-furnace-thermostat` | any | no |
| `ota_password` | string (secret) | `""` | any | no |
| `espnow_channel` | integer | `6` | `1..14` | yes |
| `espnow_peer_mac` | string | `FF:FF:FF:FF:FF:FF` | MAC format expected | yes |
| `espnow_lmk` | string (secret) | `a1b2c3d4e5f60718293a4b5c6d7e8f90` | 32 hex chars expected | yes |
| `controller_timeout_ms` | integer | `30000` | `1000..600000` | yes |

## Weather Provider (Display)
- Weather is sourced from PirateWeather API polling on the display firmware.
- Configure both of these display runtime config keys:
  - `pirateweather_api_key`
  - `pirateweather_zip` (US ZIP code)
- You can set display config either from:
  - Controller unified UI: `http://<controller-ip>/` (Display section, proxied over MQTT config topics)
  - Display local UI: `http://<display-ip>/`
- If API config is missing or fetches fail, display falls back to stub weather (`Cloudy`, `6.0C`).

## Discovery and Telemetry
- Base topic default: `esp32-wireless-thermostat`
- Each device publishes under `{base_topic}/devices/{MAC}/...`
- Device discovery: each device publishes a retained announce message at `{base_topic}/devices/{MAC}/announce` containing role, firmware version, and device name.
- Protocol-aligned command transport over MQTT:
  - Thermostat publishes packed command word: `{base_topic}/devices/{DISP_MAC}/state/packed_command`
  - Controller accepts packed command word directly: `{base_topic}/devices/{CTRL_MAC}/cmd/packed_word`
  - Home Assistant granular topics remain supported (`cmd/mode`, `cmd/fan_mode`, `cmd/target_temp_c`, etc.)
- Health telemetry (published under each device's `state/` subtree):
  - `state/boot_count`
  - `state/reset_reason`
  - `state/uptime_s`
  - `state/wifi_rssi`
  - `state/free_heap_bytes`
  - `state/last_mqtt_command_ms`
  - `state/last_espnow_rx_ms`
  - `state/espnow_send_ok_count`
  - `state/espnow_send_fail_count`
- Error reason telemetry:
  - `state/error_mqtt` (`none` or `connect_state_<code>`)
  - `state/error_ota` (`none` or `ota_error_<code>`)
  - `state/error_espnow` (`none`, `send_failed`, or `begin_failed`)
- Home Assistant discovery now includes diagnostic sensors for both controller and display:
  - WiFi RSSI, free heap, last MQTT command timestamp, last ESP-NOW RX timestamp
  - ESP-NOW send OK/fail counters
  - MQTT/OTA/ESP-NOW last error reason

## mDNS Hostnames
- Controller advertises HTTP using OTA hostname (default `esp32-furnace-controller`)
- Display advertises HTTP using OTA hostname (default `esp32-furnace-thermostat`)

## OTA Rollout + Rollback

### OTA Methods
- **ArduinoOTA**: network OTA via PlatformIO or `espota`.
- **Web OTA**: browser-based upload form at `http://<device-ip>/update`.

### Automatic Rollback
New firmware boots in a **pending-verify** state. The device must establish WiFi and MQTT connectivity within 3 minutes to confirm the update. If the device crashes or fails to connect in time, the bootloader automatically reverts to the previous firmware image.

### Rollout Order
1. Verify both devices are online and healthy before update:
   - Controller `state/uptime_s` is advancing.
   - Display `state/uptime_s` is advancing.
   - Thermostat publishes `state/packed_command` and controller applies commands.
2. Update thermostat (display) first via OTA (ArduinoOTA or web upload at `/update`).
3. Wait for display to reconnect to WiFi + MQTT and resume telemetry.
4. Update controller second via OTA.
5. Re-run MQTT smoke verification:
   - `python3 scripts/mqtt_path_smoke.py --host mqtt.lan --ctrl-mac <CTRL_MAC> --disp-mac <DISP_MAC>`

### Health Checks After Each Node Update
- Device responds on HTTP root and `/config`.
- Device reconnects to MQTT and republishes retained runtime state.
- For thermostat, `/screenshot` endpoint returns current UI frame.

### Rollback Triggers
- Automatic rollback fires if WiFi+MQTT are not established within 3 minutes of boot.
- Manual rollback warranted if:
  - Runtime state topics stop updating after reconnect.
  - Command path regression (packed or granular topics stop applying).
  - Web management endpoints become unavailable.

### Rollback Procedure
1. In most cases, automatic rollback handles failed updates without intervention.
2. If manual rollback is needed, re-flash previous known-good firmware using OTA if reachable.
3. If OTA is unavailable, use serial recovery on bench hardware, then redeploy.
4. After rollback, verify:
   - retained cfg state is intact
   - command path works (`mqtt_path_smoke.py`)
   - Home Assistant entities report expected state

### One Node Unreachable Recovery
- If thermostat is unreachable:
  - keep controller on known-good build
  - recover thermostat first (OTA if possible, serial otherwise)
  - run MQTT smoke and screenshot checks before controller changes
- If controller is unreachable:
  - recover controller first (it hosts unified management UI)
  - confirm display reconnects and cfg proxy state repopulates

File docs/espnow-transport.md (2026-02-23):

# ESP-NOW Transport

## Scope
This documents the current ESP-NOW transport adapters present in the PlatformIO port.

## Packet Types
Defined in `./include/transport/espnow_packets.h`.

- `Heartbeat` (`PacketType::Heartbeat`)
- `CommandWord` (`PacketType::CommandWord`)
- `ControllerTelemetry` (`PacketType::ControllerTelemetry`)
- `IndoorTemperature` (`PacketType::IndoorTemperature`)
- `IndoorHumidity` (`PacketType::IndoorHumidity`)

Protocol version: `1`.

## Implemented Adapters

Controller-side adapter:
- `./include/controller/transport/espnow_controller_transport.h`
- `./src/controller/transport/espnow_controller_transport.cpp`

Thermostat-side adapter:
- `./include/thermostat/transport/espnow_thermostat_transport.h`
- `./src/thermostat/transport/espnow_thermostat_transport.cpp`

## Current Behavior

Controller adapter:
- Initializes ESP-NOW and one configured peer.
- Receives heartbeat, command-word, indoor temperature, and indoor humidity packets.
- Sends periodic heartbeat and controller telemetry packets.

Thermostat adapter:
- Initializes ESP-NOW and one configured peer.
- Receives heartbeat and controller telemetry packets.
- Sends periodic heartbeat, packed command word, indoor temperature, and indoor humidity packets.

Both adapters include native-build-safe no-op behavior so host tests still compile.

## Integration Points
- `ControllerApp` owns control logic and emits telemetry via `IControllerTransport`.
- `EspNowControllerTransport` implements `IControllerTransport`.
- `ControllerNode` wires controller transport callbacks into `ControllerApp`.
- `ThermostatApp` owns thermostat-side command sequencing and controller telemetry ingestion.
- `ThermostatNode` wires thermostat transport callbacks into `ThermostatApp`.

## Remaining Work
- ~~Bind real display/UI events and local sensor sources into `ThermostatApp` methods.~~ Done.
- ~~Add optional ACK/diagnostic counters and explicit send result handling.~~ Done — send OK/fail counters are tracked and published as telemetry.
- Finalize encryption key handling and peer provisioning strategy.
- Note: when MQTT-primary is active, ESP-NOW commands are gated on the controller to avoid conflicting sources.

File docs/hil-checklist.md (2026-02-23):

# Hardware-In-Loop Checklist

Use this checklist after flashing both devices.

## Metadata
- Date:
- Controller firmware version:
- Display firmware version:
- Controller board ID:
- Display board ID:
- WiFi SSID/channel:

## Controller Checks
- [ ] Relays boot OFF (GPIO32/33/25/26).
- [ ] `cmd/lockout=1` forces all relays OFF and keeps them OFF.
- [ ] `cmd/lockout=0` re-enables normal relay behavior.
- [ ] Heat demand drives only heat relay.
- [ ] Cool demand drives only cool relay.
- [ ] Fan-only demand drives only fan relay.
- [ ] Relay transition honors interlock wait timing (heat 0.5s, others 1s).
- [ ] Failsafe timeout forces relays OFF.

## Thermostat Checks
- [ ] Display boots and touch is responsive.
- [ ] AHT20 indoor temperature/humidity updates every minute.
- [ ] Local setpoint/mode/fan changes are reflected on controller state.
- [ ] Display timeout setting changes idle timing behavior.
- [ ] Clock shows real local time (not uptime counter).
- [ ] Settings diagnostics show IP/MAC/SSID/channel/RSSI/firmware.
- [ ] Weather/outdoor values update from PirateWeather API using configured API key + ZIP.

## Transport Checks
- [ ] ESP-NOW path works when MQTT is unavailable.
- [ ] MQTT path updates controller state from display packed command mirror (`state/packed_command`).
- [ ] While MQTT-primary is active, ESP-NOW commands are gated on controller.
- [ ] After MQTT outage, ESP-NOW fallback takes over.
- [ ] After MQTT restore, controller returns to MQTT-primary mode.

## Home Assistant Checks
- [ ] Climate entity available and controllable.
- [ ] Lockout switch entity available and controllable.
- [ ] Filter runtime and furnace state sensors update.
- [ ] Device model appears as one logical device identifier.

## OTA Checks
- [ ] Web upload form loads at `http://<controller-ip>/update`.
- [ ] Web upload form loads at `http://<display-ip>/update`.
- [ ] Firmware upload via web form succeeds and device reboots.
- [ ] After successful OTA, device confirms health and stays on new firmware.
- [ ] Flashing intentionally bad firmware triggers automatic rollback to previous image.

## Result
- Status: PASS / FAIL
- Notes:

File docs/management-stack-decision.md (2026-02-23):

# Management Stack Decision

## Decision
We are **not** implementing ESPHome API/web/captive-portal/OTA parity in this port.

## Rationale
- The PlatformIO firmware now uses MQTT + provisioning flows directly.
- MQTT discovery and topic surfaces cover operational control and diagnostics.
- Keeping one management path reduces duplicated state/control surfaces.

## Adopted Replacements
- Control/state surface: MQTT topics and HA discovery.
- Provisioning: WiFi provisioning (`WiFiProv`) and static build-flag overrides.
- OTA/debug: ArduinoOTA for network updates, web-based OTA upload at `/update`, and serial logs.

## Notes
- If field requirements change, this can be revisited as a separate feature stream.

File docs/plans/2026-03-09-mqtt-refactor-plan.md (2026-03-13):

# MQTT Topic Refactor Implementation Plan

> **For Claude:** REQUIRED SUB-SKILL: Use superpowers:executing-plans to implement this plan task-by-task.

**Goal:** Consolidate all MQTT topics under `esp32-wireless-thermostat/devices/{MAC}/...` with MAC-based device paths, removing hardcoded base topic config keys.

**Architecture:** Replace per-device base topic strings with a single shared `base_topic` config + each device's WiFi MAC. Topic helpers become `{base_topic}/devices/{MAC}/{suffix}`. Peer topics are constructed from `{base_topic}/devices/{peer_MAC}/{suffix}`. HA discovery payloads updated to reference new paths.

**Tech Stack:** Arduino/ESP-IDF C++ (PubSubClient), SDL2 simulators (mosquittopp), Python test scripts.

**Design doc:** `docs/plans/2026-03-09-mqtt-topic-redesign.md`

---

### Task 1: Extract shared topic builder into header

Create a platform-agnostic header that both firmware and simulators use to construct topics from base_topic + MAC + suffix. This is the foundation everything else builds on.

**Files:**
- Create: `include/mqtt_topics.h`
- Test: `src/tests/test_mqtt_topics.cpp`

**Step 1: Write the failing test**

Create `src/tests/test_mqtt_topics.cpp`:

```cpp
#if defined(THERMOSTAT_RUN_TESTS)
#include "test_harness.h"
#include "mqtt_topics.h"

TEST_CASE(mqtt_topics_device_topic) {
  char buf[128];
  mqtt_topics::device_topic(buf, sizeof(buf),
      "esp32-wireless-thermostat", "AABBCC", "state/mode");
  ASSERT_STREQ(buf, "esp32-wireless-thermostat/devices/AABBCC/state/mode");
}

TEST_CASE(mqtt_topics_device_topic_truncates_safely) {
  char buf[32];  // too small
  mqtt_topics::device_topic(buf, sizeof(buf),
      "esp32-wireless-thermostat", "AABBCC", "state/mode");
  // Must be null-terminated and not overflow
  ASSERT_TRUE(strlen(buf) < 32);
}

TEST_CASE(mqtt_topics_announce_topic) {
  char buf[128];
  mqtt_topics::device_topic(buf, sizeof(buf),
      "esp32-wireless-thermostat", "AABBCC", "announce");
  ASSERT_STREQ(buf, "esp32-wireless-thermostat/devices/AABBCC/announce");
}

TEST_CASE(mqtt_topics_peer_topic) {
  char buf[128];
  mqtt_topics::device_topic(buf, sizeof(buf),
      "esp32-wireless-thermostat", "112233", "state/packed_command");
  ASSERT_STREQ(buf, "esp32-wireless-thermostat/devices/112233/state/packed_command");
}

TEST_CASE(mqtt_topics_wildcard_subscribe) {
  char buf[128];
  mqtt_topics::device_topic(buf, sizeof(buf),
      "esp32-wireless-thermostat", "+", "announce");
  ASSERT_STREQ(buf, "esp32-wireless-thermostat/devices/+/announce");
}

TEST_CASE(mqtt_topics_client_id) {
  char buf[64];
  mqtt_topics::client_id(buf, sizeof(buf),
      "esp32-wireless-thermostat", "AABBCC");
  ASSERT_STREQ(buf, "esp32-wireless-thermostat-AABBCC");
}

#endif
```

**Step 2: Run tests to verify they fail**

Run: `pio run -e native-tests && .pio/build/native-tests/program`
Expected: Compile error — `mqtt_topics.h` not found.

**Step 3: Write the header**

Create `include/mqtt_topics.h`:

```cpp
#pragma once
#include <cstdio>
#include <cstring>

namespace mqtt_topics {

/// Build "{base}/devices/{mac}/{suffix}" into buf.
inline int device_topic(char *buf, size_t buf_len,
                        const char *base, const char *mac,
                        const char *suffix) {
  return snprintf(buf, buf_len, "%s/devices/%s/%s", base, mac, suffix);
}

/// Build "{base}-{mac}" client ID into buf.
inline int client_id(char *buf, size_t buf_len,
                     const char *base, const char *mac) {
  return snprintf(buf, buf_len, "%s-%s", base, mac);
}

}  // namespace mqtt_topics
```

**Step 4: Run tests to verify they pass**

Run: `pio run -e native-tests && .pio/build/native-tests/program`
Expected: All new tests PASS.

**Step 5: Commit**

```
git add include/mqtt_topics.h src/tests/test_mqtt_topics.cpp
git commit -m "feat: add shared mqtt_topics.h topic builder with tests"
```

---

### Task 2: Add `base_topic`, `ha_discovery_enabled`, and `device_name` config to controller

Replace `mqtt_base_topic`, `display_mqtt_base_topic`, and `mqtt_client_id` config keys with `base_topic`, `ha_discovery_enabled`, and `device_name`. Update NVS load/save and config publishing.

**Files:**
- Modify: `src/esp32_controller_main.cpp`
  - Compile-time defaults (~lines 134-156)
  - Config variables (~lines 191-197)
  - NVS load (~lines 300-310)
  - Topic helper functions (~lines 357-369)
  - Config key handlers (~lines 456-468)
  - Config publishing (~lines 377-418)
  - Web config UI fields (~lines 1320-1330)

**Step 1: Update compile-time defaults**

Replace these defines:
```cpp
// OLD:
#define THERMOSTAT_CONTROLLER_MQTT_CLIENT_ID "esp32-furnace-controller"
#define THERMOSTAT_CONTROLLER_MQTT_BASE_TOPIC "thermostat/furnace-controller"
#define THERMOSTAT_THERMOSTAT_MQTT_BASE_TOPIC "thermostat/furnace-display"
#define THERMOSTAT_MQTT_UNIQUE_DEVICE_ID "wireless_thermostat_system"
#define THERMOSTAT_DEVICE_DISCOVERY_PREFIX THERMOSTAT_MQTT_UNIQUE_DEVICE_ID "/devices"

// NEW:
#define THERMOSTAT_BASE_TOPIC "esp32-wireless-thermostat"
```

**Step 2: Update config variables**

Replace:
```cpp
// OLD:
String g_cfg_ctrl_mqtt_client_id;
String g_cfg_ctrl_mqtt_base_topic;
String g_cfg_display_mqtt_base_topic;

// NEW:
String g_cfg_base_topic;
String g_cfg_device_mac;  // 6-char hex, set from WiFi MAC at boot
String g_cfg_device_name; // user-friendly name, default "controller-{MAC}"
bool g_cfg_ha_discovery_enabled = true;
```

**Step 3: Update topic helper functions**

Replace `ctrl_topic_for` and `display_topic_for` with helpers that use `mqtt_topics.h`:

```cpp
#include "mqtt_topics.h"

String device_topic_for(const char *mac, const char *suffix) {
  char buf[192];
  mqtt_topics::device_topic(buf, sizeof(buf),
      g_cfg_base_topic.c_str(), mac, suffix);
  return String(buf);
}

String self_topic_for(const char *suffix) {
  return device_topic_for(g_cfg_device_mac.c_str(), suffix);
}

String peer_topic_for(const char *peer_mac, const char *suffix) {
  return device_topic_for(peer_mac, suffix);
}
```

**Step 4: Update NVS load/save**

- Load `base_topic` from NVS key `"base_topic"` (default: `THERMOSTAT_BASE_TOPIC`)
- Load `ha_discovery_enabled` from NVS key `"ha_disc"` (default: `true`)
- Load `device_name` from NVS key `"device_name"` (default: `"controller-{MAC}"`)
- Remove NVS keys: `"mqtt_cid"`, `"mqtt_base"`, `"disp_base"`
- Compute `g_cfg_device_mac` from `WiFi.macAddress()` (last 3 bytes, uppercase hex, no colons)
- Auto-generate client ID: `mqtt_topics::client_id(buf, ..., base_topic, device_mac)`
- If `device_name` is empty on first boot, auto-generate as `"controller-" + g_cfg_device_mac`

**Step 5: Update config key handlers**

- Add handler for `"base_topic"` → save to NVS, set `g_ctrl_mqtt_discovery_sent = false`
- Add handler for `"ha_discovery_enabled"` → save to NVS
- Add handler for `"device_name"` → save to NVS, set `g_ctrl_mqtt_discovery_sent = false`
- Remove handlers for `"mqtt_client_id"`, `"mqtt_base_topic"`, `"display_mqtt_base_topic"`

**Step 6: Update config publishing and web UI**

- Publish `base_topic` and `ha_discovery_enabled` in `ctrl_publish_all_cfg_state()`
- Update web config form: replace Client ID / Base Topic / Display Base Topic fields with single Base Topic field + HA Discovery Enabled checkbox

**Step 7: Build and verify compilation**

Run: `pio run -e esp32-furnace-controller` (or native-tests for non-hardware validation)
Expected: Compiles without errors. (Full integration comes in later tasks.)

**Step 8: Commit**

```
git commit -m "refactor: replace controller per-device base topics with shared base_topic + MAC"
```

---

### Task 3: Update controller MQTT connect, subscribe, and publish

Wire up all controller MQTT operations to use the new topic structure: `{base_topic}/devices/{MAC}/...`.

**Files:**
- Modify: `src/esp32_controller_main.cpp`
  - MQTT connect/LWT (~line 1949)
  - Subscribe block (~lines 1965-1981)
  - All publish calls in `ctrl_publish_runtime_state()` (~lines 1524-1617)
  - Message callback topic matching (~lines 1710-1845)
  - Device registry publish (~lines 1996-2006)
  - Announce topic (new)

**Step 1: Update MQTT connect**

- LWT topic: `self_topic_for("state/availability")` (same pattern, new path)
- Client ID: auto-generated from `g_cfg_base_topic + "-" + g_cfg_device_mac`

**Step 2: Update subscriptions**

Replace all `ctrl_topic_for("cmd/...")` with `self_topic_for("cmd/...")`.
Replace `display_topic_for("state/packed_command/+")` with wildcard:
`device_topic_for("+", "state/packed_command")`.
Replace `display_topic_for("state/availability")` with:
`device_topic_for("+", "state/availability")`.
Replace `THERMOSTAT_DEVICE_DISCOVERY_PREFIX "/+"` with:
`device_topic_for("+", "announce")`.
Replace sensor subscriptions: `self_topic_for("sensor/+/temp_c")` becomes
`device_topic_for("+", "sensor/temp_c")` and `device_topic_for("+", "sensor/humidity")`.

**Step 3: Update all publish calls**

Replace all `ctrl_topic_for(...)` calls in `ctrl_publish_runtime_state()` with `self_topic_for(...)`.

**Step 4: Update message callback**

The MQTT message callback needs to parse the new topic format. Extract the device MAC from the topic path (`{base}/devices/{MAC}/...`) and use it for:
- Sensor MAC identification (currently parsed from `sensor/{MAC}/temp_c`)
- Packed command source MAC (currently parsed from `packed_command/{MAC}`)
- Authorization checks against the allowed devices list

**Step 5: Publish announce on connect**

After subscribing, publish a retained JSON announce message:
```json
{"role":"controller","firmware":"v0.9.0","name":"controller-29A9C4"}
```
to `self_topic_for("announce")`. The `name` field uses `g_cfg_device_name`.

**Step 6: Guard HA discovery**

Wrap `ctrl_publish_discovery()` call with `if (g_cfg_ha_discovery_enabled)`.

**Step 7: Build and verify**

Run: `pio run -e esp32-furnace-controller`
Expected: Compiles. (Runtime testing after display is also updated.)

**Step 8: Commit**

```
git commit -m "refactor: controller MQTT connect/subscribe/publish uses new topic paths"
```

---

### Task 4: Update controller HA discovery payloads

All discovery payloads must reference the new `{base_topic}/devices/{MAC}/...` paths.

**Files:**
- Modify: `src/esp32_controller_main.cpp` — `ctrl_publish_discovery()` (~lines 837-1017)
- Modify: `src/tests/test_mqtt_discovery.cpp`

**Step 1: Update discovery tests**

Update `kBase` in test file to use the new topic format:
```cpp
static const char *kBase = "esp32-wireless-thermostat/devices/AABBCC";
```

Run tests to verify they fail (payloads still use old format in test expectations).

**Step 2: Update `ctrl_publish_discovery()`**

The `~` (tilde) abbreviation in HA discovery uses the device's full topic path as the base.
Change from `g_cfg_ctrl_mqtt_base_topic` to `self_topic_for("")` (without trailing slash — verify HA tilde expansion behavior).

All topic references in discovery JSON that pointed to `g_cfg_ctrl_mqtt_base_topic` or `g_cfg_display_mqtt_base_topic` must use `self_topic_for(...)` or `peer_topic_for(peer_mac, ...)`.

For display entities (indoor temp/humidity sensors, display settings), the `stat_t` must reference the display's topic path: `{base_topic}/devices/{display_MAC}/...`.

**Step 3: Run discovery tests**

Run: `pio run -e native-tests && .pio/build/native-tests/program`
Expected: All discovery payload size tests pass with new topic format.

**Step 4: Commit**

```
git commit -m "refactor: HA discovery payloads use new device topic paths"
```

---

### Task 5: Add `base_topic` config to display and update topic helpers

Mirror the controller changes on the display side.

**Files:**
- Modify: `src/thermostat/esp32s3_thermostat_firmware.cpp`
  - Compile-time defaults (~lines 103-125)
  - Config variables (~lines 295-308)
  - NVS load (~lines 410-441)
  - Topic helpers (~lines 443-455)
  - Config key handlers (~lines 539-546)
  - Config publishing (~lines 470-496)
  - Web config UI fields (~lines 1170-1175)

**Step 1: Update compile-time defaults**

Replace:
```cpp
#define THERMOSTAT_MQTT_CLIENT_ID "esp32-furnace-thermostat"
#define THERMOSTAT_MQTT_BASE_TOPIC "thermostat/furnace-display"
#define THERMOSTAT_MQTT_UNIQUE_DEVICE_ID "wireless_thermostat_system"
#define THERMOSTAT_DEVICE_DISCOVERY_PREFIX ...
```
With:
```cpp
#define THERMOSTAT_BASE_TOPIC "esp32-wireless-thermostat"
```

**Step 2: Update config variables and NVS**

- Replace `g_cfg_mqtt_client_id`, `g_cfg_mqtt_base_topic`, `g_cfg_controller_base_topic` with `g_cfg_base_topic`, `g_cfg_device_mac`, `g_cfg_device_name`, `g_cfg_ha_discovery_enabled`
- Load `device_name` from NVS key `"device_name"` (default: `"display-{MAC}"`)
- Store paired controller MAC in config (existing `devices` mechanism or new `controller_mac` key)
- Auto-generate client ID from base_topic + MAC

**Step 3: Update topic helpers**

Replace `topic_for()` and `controller_topic_for()` with the same pattern as controller:
```cpp
#include "mqtt_topics.h"

String self_topic_for(const char *suffix) { ... }
String controller_topic_for_mac(const char *suffix) {
  return device_topic_for(g_cfg_paired_controller_mac.c_str(), suffix);
}
```

**Step 4: Update config publishing and web UI**

Same pattern as controller Task 2.

**Step 5: Build and verify**

Run: `pio run -e esp32-furnace-thermostat`
Expected: Compiles.

**Step 6: Commit**

```
git commit -m "refactor: display config uses shared base_topic + MAC"
```

---

### Task 6: Update display MQTT connect, subscribe, publish, and sensor output

Wire up all display MQTT operations to new topic paths. Key change: sensor data publishes under the display's own path instead of the controller's namespace.

**Files:**
- Modify: `src/thermostat/esp32s3_thermostat_firmware.cpp`
  - MQTT connect/LWT (~line 1941)
  - Subscribe block (~lines 1957-1984)
  - State publishing (~lines 1330-1442)
  - Sensor publishing (currently publishes to controller's `sensor/{MAC}/temp_c`)
  - Message callback (~lines 1695-1852)
  - Announce publish (new)
  - Packed command publish — remove MAC suffix from topic (now implicit in device path)

**Step 1: Update MQTT connect**

- LWT: `self_topic_for("state/availability")`
- Client ID: auto-generated

**Step 2: Update subscriptions**

- Own cmd topics: `self_topic_for("cmd/reboot")`, etc.
- Own cfg topics: `self_topic_for("cfg/+/set")`
- Controller state: `controller_topic_for_mac("state/mode")`, etc.
- Device discovery: `device_topic_for("+", "announce")`
- Remove `cmd/mode`, `cmd/fan_mode`, `cmd/target_temp_c` subscriptions (controller is sole HVAC authority now)

**Step 3: Update publish calls**

- All `topic_for(...)` → `self_topic_for(...)`
- Sensor data: publish to `self_topic_for("sensor/temp_c")` and `self_topic_for("sensor/humidity")` instead of controller's namespace
- Packed command: publish to `self_topic_for("state/packed_command")` (no MAC suffix needed)

**Step 4: Publish announce on connect**

```json
{"role":"display","firmware":"v0.9.0","name":"display-55D0E8"}
```
The `name` field uses `g_cfg_device_name`.

**Step 5: Guard HA discovery**

Wrap `mqtt_publish_discovery()` with `if (g_cfg_ha_discovery_enabled)`.

**Step 6: Build and verify**

Run: `pio run -e esp32-furnace-thermostat`
Expected: Compiles.

**Step 7: Commit**

```
git commit -m "refactor: display MQTT uses new topic paths, sensors publish under own device"
```

---

### Task 7: Update display HA discovery payloads

**Files:**
- Modify: `src/thermostat/esp32s3_thermostat_firmware.cpp` — `mqtt_publish_discovery()` (~lines 1445-1640)

**Step 1: Update discovery payloads**

All `stat_t`, `cmd_t` references change from old base topic to `self_topic_for(...)`.

Display-specific entities (indoor temp sensor, humidity sensor, display timeout, backlight settings, reboot button) all reference the display's own device path.

**Step 2: Build and verify**

Run: `pio run -e esp32-furnace-thermostat`

**Step 3: Commit**

```
git commit -m "refactor: display HA discovery payloads use new device topic paths"
```

---

### Task 8: Update simulators

Both simulators use hardcoded topic constants. Update to match the new structure.

**Files:**
- Modify: `src/sim/controller_preview.cpp` (~lines 30-34, 62-68, all topic references)
- Modify: `src/sim/thermostat_ui_preview.cpp` (~lines 37-44, 141-147, all topic references)

**Step 1: Update controller simulator**

Replace hardcoded constants:
```cpp
// OLD:
static const std::string kControllerBaseTopic = "thermostat/furnace-controller";
static const std::string kDisplayBaseTopic = "thermostat/furnace-display";

// NEW:
static const std::string kBaseTopic = "esp32-wireless-thermostat";
static const std::string kControllerMac = "SIM_CTRL";
static const std::string kDisplayMac = "SIM_DISP";
```

Update `ctrl_topic()` and `display_topic()` to build `{base}/devices/{mac}/{suffix}`.

**Step 2: Update thermostat simulator**

Same pattern — update constants and topic helpers.

**Step 3: Build both simulators**

Run: `pio run -e native-controller-preview && pio run -e native-ui-preview`
Expected: Both compile.

**Step 4: Commit**

```
git commit -m "refactor: simulators use new MQTT topic structure"
```

---

### Task 9: Update integration and smoke test scripts

**Files:**
- Modify: `scripts/mqtt_path_smoke.py` — update topic paths
- Modify: `scripts/integration-test.sh` — no MQTT topic changes needed (HTTP only), but verify
- Create: `scripts/mqtt_cleanup_old_topics.py` — cleanup script for old retained messages

**Step 1: Update smoke test**

Replace:
```python
ctrl_base = f"{args.prefix}/furnace-controller"
disp_base = f"{args.prefix}/furnace-display"
```
With MAC-based paths. Add `--ctrl-mac` and `--disp-mac` CLI arguments. Default topic prefix becomes `esp32-wireless-thermostat`.

Update all topic references to `{prefix}/devices/{mac}/...` format.

**Step 2: Create cleanup script**

`scripts/mqtt_cleanup_old_topics.py` subscribes to old topic prefixes (`thermostat/furnace-controller/#`, `thermostat/furnace-display/#`, `wireless_thermostat_system/#`), collects retained messages, and publishes empty retained to each to clear them.

**Step 3: Run smoke test against running devices**

Run: `python3 scripts/mqtt_path_smoke.py --host 10.0.1.175 --ctrl-mac AABBCC --disp-mac 55D0E8`
Expected: PASS

**Step 4: Commit**

```
git commit -m "refactor: update test scripts for new MQTT topic structure, add cleanup script"
```

---

### Task 10: Update documentation

**Files:**
- Modify: `docs/deployment-runbook.md` — topic contract, config keys, smoke test usage
- Modify: `docs/plans/2026-03-09-mqtt-topic-redesign.md` — mark as implemented
- Modify: `CLAUDE.md` — update shared header references if needed

**Step 1: Update deployment runbook**

- Replace all old topic examples with new `{base_topic}/devices/{MAC}/...` format
- Update config contract tables (remove old keys, add new ones)
- Update smoke test usage with `--ctrl-mac` / `--disp-mac` args
- Document the cleanup script for migration

**Step 2: Commit**

```
git commit -m "docs: update deployment runbook for new MQTT topic structure"
```

---

### Task 11: End-to-end verification

**No code changes.** Run the full test suite against real hardware.

**Step 1: Run unit tests**

Run: `pio run -e native-tests && .pio/build/native-tests/program`
Expected: All 37+ tests pass.

**Step 2: Build and flash both devices**

Build controller and display firmware. Flash via OTA or serial.

**Step 3: Run integration tests**

Run: `bash scripts/integration-test.sh --verbose`
Expected: 16/16 pass.

**Step 4: Run MQTT smoke test**

Run: `python3 scripts/mqtt_path_smoke.py --host 10.0.1.175 --ctrl-mac <MAC> --disp-mac <MAC>`
Expected: PASS.

**Step 5: Run cleanup script on old topics**

Run: `python3 scripts/mqtt_cleanup_old_topics.py --host 10.0.1.175`
Expected: Old retained messages cleared.

**Step 6: Verify HA discovery**

Check Home Assistant — climate entity, lockout switch, sensors should all appear and be controllable.

**Step 7: Commit any fixes, tag release**

```
git tag v1.0.0
```

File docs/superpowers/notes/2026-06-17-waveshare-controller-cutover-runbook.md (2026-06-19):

# Waveshare ESP32-S3 Controller — Cutover Runbook

How to replace the live furnace controller (classic ESP32, `192.168.42.57`, MAC
`38:18:2B:EC:FB:9C`) with the Waveshare ESP32-S3 board, with **zero Home Assistant or
display reconfiguration** thanks to the identity-MAC-override feature.

> **Status of the port (2026-06-17):** all firmware is built + bench-validated on the real
> Waveshare board (relays, RTC, Ethernet, coredump, resilience, identity override). The ONE
> thing not yet validated is the controller↔display ESP-NOW exchange end-to-end (no spare
> display on the bench) — validate that first on the bench with the real display if possible,
> or accept it as the one live-test risk during cutover (ESP-NOW *init* is proven; the dropin
> MAC + channel + LMK below are what make the existing display peer work unchanged).

---

## What's config vs. what's build-time

| Cutover parameter | How to set | Production value |
|---|---|---|
| Identity MAC (HA + ESP-NOW) | NVS `id_mac` / web "Identity MAC Override" | `38:18:2B:EC:FB:9C` |
| Base topic | NVS `base_topic` (or the prod env default) | `esp32-wireless-thermostat` |
| MQTT broker | NVS `mqtt_host` | `mqtt.lan` |
| HA discovery prefix | NVS `discovery_prefix` | `homeassistant` |
| ESP-NOW channel | NVS `espnow_channel` (or prod env default) | `6` |
| ESP-NOW LMK | NVS `espnow_lmk` (or prod env default) | `a1b2c3d4e5f60718293a4b5c6d7e8f90` |
| **Relay → HVAC mapping** | **BUILD-TIME** (`Pca9554RelayBackendConfig`) | default heat=relay0, cool=relay1, fan=relay2 |

**Recommended firmware:** build `esp32-furnace-controller-waveshare-prod`. It already bakes in
the production base topic + ESP-NOW channel 6 + production LMK (the same defaults the classic
controller uses, so the existing display peers to it). You then only need to set **`id_mac`**
(and `mqtt_host` if not `mqtt.lan`) via the web UI. The `-waveshare` (test-identity) env is for
bench work only and must NOT be used for cutover.

**Relay mapping is the one build-time item.** Wire the furnace so W (heat)→relay0,
Y (cool)→relay1, G (fan)→relay2 to match the default. If your existing wiring differs, edit the
`Pca9554RelayBackend g_relay_backend` construction (`heat_bit/cool_bit/fan_bit`) and rebuild.

---

## Pre-cutover checklist
- [ ] (Recommended) Validate controller↔display ESP-NOW on the bench with a real display.
- [ ] Confirm the relay→furnace wiring plan (default heat0/cool1/fan2, or rebuild for a custom map).
- [ ] Decide Ethernet addressing: DHCP (works) or a **DHCP reservation** for the board's
      Ethernet MAC (recommended for a stable IP / OTA URL). Note the Ethernet MAC is derived
      from the override base MAC once `id_mac` is set (it is `id_mac + 3`), so set the
      reservation after first boot when you can read the leased MAC.
- [ ] (Optional but recommended) Populate the RTC backup battery so time survives a cold boot.
- [ ] Build `esp32-furnace-controller-waveshare-prod` and stage the 4 flash images.

## Cutover procedure

1. **Quiesce the old controller.** In HA (or via MQTT) set HVAC **Off**, wait 60 s for relays
   to de-energize (the flashing runbook). Then power it down / unplug it.

2. **Flash the Waveshare board** with `esp32-furnace-controller-waveshare-prod`:
   ```
   esptool --chip esp32s3 --port <port> --after hard_reset write_flash \
     0x0 bootloader.bin 0x8000 partitions.bin 0xe000 boot_app0.bin 0x10000 firmware.bin
   ```
   On first boot it comes up on Ethernet (DHCP) with its own factory MAC, base topic
   `esp32-wireless-thermostat`, ESP-NOW channel 6.

3. **Set the identity override.** Browse to the board's web UI (`http://<eth-ip>/`, the IP is on
   the serial boot log / your DHCP server) → Config → MQTT → **Identity MAC Override** =
   `38:18:2B:EC:FB:9C`. Set `mqtt_host` if not `mqtt.lan`. Save → reboot.
   - After reboot the serial log shows `[espnow] radio MAC=38:18:2B:EC:FB:9C identity MAC=
     38:18:2B:EC:FB:9C` and HA sees the **same** controller device (same uniq_id/topics) — no
     new entities, no display re-pairing.

4. **Wire the furnace** to the relays (W→relay0, Y→relay1, G→relay2) and power up. (Do this
   with the HVAC system safe / breaker off as appropriate.)

## Verification
- [ ] Serial/`[espnow]` log confirms radio + identity MAC = `38:18:2B:EC:FB:9C`.
- [ ] HA shows the existing controller device online (no duplicate/new device); `state/*` update.
- [ ] The thermostat **display** controls the controller over ESP-NOW (change mode/setpoint on
      the display → controller `state/mode` etc. follow; `espnow_connected`/heartbeat healthy).
- [ ] Relays actuate correctly: a heat call closes relay0, cool→relay1, fan→relay2; the
      interlock forces off+settle when switching heat↔cool.
- [ ] Ethernet link stable; MQTT connected; `state/time_utc` sane (RTC/SNTP).
- [ ] Trigger nothing, but note `state/reboot_reason`/`panic_pc` for clean-boot diagnostics.

## Rollback
If anything is wrong: set HVAC Off, power down the Waveshare board, re-wire + power up the old
classic controller. Because the Waveshare assumed the old MAC/identity, HA + the display return
to the old controller with no reconfiguration. (Clear the Waveshare's retained MQTT messages if
it published bad state: empty-retained-publish to its `state/*` + the HA discovery configs.)

## Notes / residual risk
- The controller↔display ESP-NOW path is the only un-bench-validated function; the dropin MAC +
  channel 6 + production LMK are specifically what make the existing display work without
  changes, but confirm on first live boot.
- Two controllers must never run with `id_mac` = the same MAC simultaneously (MAC conflict).
  Always power down the old one first.
- The pre-existing ESP-NOW-recv-mutates-app() data race (benign in practice) is unchanged; a
  follow-up could route ESP-NOW commands through the same inbound queue used for MQTT.

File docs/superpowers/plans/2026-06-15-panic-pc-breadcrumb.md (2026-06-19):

# Panic-PC Breadcrumb Implementation Plan

> **For agentic workers:** REQUIRED SUB-SKILL: Use superpowers:subagent-driven-development (recommended) or superpowers:executing-plans to implement this plan task-by-task. Steps use checkbox (`- [ ]`) syntax for tracking.

**Goal:** Capture the faulting PC + a short backtrace into RTC-memory when the controller panics, and publish it over MQTT on the next boot — giving crash *localization* on the current 4 MB board (and the future S3 board) without a coredump partition.

**Architecture:** A platform-agnostic `PanicBreadcrumb` record (POD, fixed-size, fully unit-tested for validation + formatting). A firmware-only hook wraps ESP-IDF's `esp_panic_handler` via the linker (`-Wl,--wrap=esp_panic_handler`) to stamp the record into `RTC_NOINIT` memory before the panic completes. On boot, `main` recovers the record, formats it to a string, publishes it as a retained `state/panic_pc` topic + HA diagnostic sensor (mirroring the existing `wdt_section` breadcrumb), then invalidates it (one-shot).

**Tech Stack:** C++ (Arduino-ESP32 / native), ESP-IDF panic API, PlatformIO `native-tests` env, project `TEST_CASE`/`ASSERT_*` harness.

**Validation boundary:** the record module (Tasks 1) is fully native-tested. The panic hook + wiring (Tasks 2–3) compile in the firmware build but their runtime behavior can only be confirmed by forcing a panic on a real device (the current controller). That on-device confirmation is deferred to the user; it does NOT require the new S3 board.

---

## File Structure

- **Create** `include/controller/panic_breadcrumb.h` — `PanicBreadcrumb` POD + `panic_breadcrumb_present()` + `panic_breadcrumb_format()` (all inline, platform-agnostic).
- **Create** `src/tests/test_panic_breadcrumb.cpp` — native unit tests for present/format/clamping.
- **Create** `src/controller/panic_breadcrumb_hook.cpp` — firmware-only (`#if defined(ARDUINO)`): the `RTC_NOINIT` record instance, `__wrap_esp_panic_handler`, `panic_breadcrumb_capture()`, and `panic_breadcrumb_recover_on_boot()`.
- **Create** `include/controller/panic_breadcrumb_hook.h` — declares `panic_breadcrumb_recover_on_boot(char *out, size_t out_len)` for `main`.
- **Modify** `platformio.ini` — add `-Wl,--wrap=esp_panic_handler` to the `esp32-furnace-controller` env `build_flags`.
- **Modify** `src/esp32_controller_main.cpp` — recover on boot into a `g_ctrl_panic_pc` String; publish `state/panic_pc`; add the HA discovery sensor; publish in the runtime-state path (next to `wdt_section`).

---

## Task 1: `PanicBreadcrumb` record module (TDD, native)

**Files:**
- Create: `include/controller/panic_breadcrumb.h`
- Create: `src/tests/test_panic_breadcrumb.cpp`

- [ ] **Step 1: Write the failing tests**

Create `src/tests/test_panic_breadcrumb.cpp`:

```cpp
#if defined(THERMOSTAT_RUN_TESTS)
#include <cstring>

#include "controller/panic_breadcrumb.h"
#include "test_harness.h"

using thermostat::PanicBreadcrumb;

TEST_CASE(panic_breadcrumb_absent_formats_none) {
  PanicBreadcrumb b{};  // all zero: magic invalid
  ASSERT_TRUE(!thermostat::panic_breadcrumb_present(b));
  char out[64];
  thermostat::panic_breadcrumb_format(b, out, sizeof(out));
  ASSERT_STR_EQ(out, "none");
}

TEST_CASE(panic_breadcrumb_present_requires_magic_and_pc) {
  PanicBreadcrumb b{};
  b.magic = thermostat::kPanicBreadcrumbMagic;
  b.pc = 0;  // no pc -> not present
  ASSERT_TRUE(!thermostat::panic_breadcrumb_present(b));
  b.pc = 0x400d1234;
  ASSERT_TRUE(thermostat::panic_breadcrumb_present(b));
}

TEST_CASE(panic_breadcrumb_formats_pc_core_and_backtrace) {
  PanicBreadcrumb b{};
  b.magic = thermostat::kPanicBreadcrumbMagic;
  b.core = 1;
  b.pc = 0x400d1234;
  b.depth = 2;
  b.backtrace[0] = 0x400d5678;
  b.backtrace[1] = 0x400d9abc;
  char out[128];
  thermostat::panic_breadcrumb_format(b, out, sizeof(out));
  ASSERT_STR_EQ(out, "core1 pc=0x400d1234 bt=0x400d5678,0x400d9abc");
}

TEST_CASE(panic_breadcrumb_depth_is_clamped) {
  PanicBreadcrumb b{};
  b.magic = thermostat::kPanicBreadcrumbMagic;
  b.pc = 0x1;
  b.depth = 999;  // larger than kPanicBacktraceDepth
  for (size_t i = 0; i < thermostat::kPanicBacktraceDepth; ++i) b.backtrace[i] = 0x10 + i;
  char out[256];
  thermostat::panic_breadcrumb_format(b, out, sizeof(out));
  // Must not read past the array: exactly kPanicBacktraceDepth bt entries.
  int commas = 0;
  for (const char *p = out; *p; ++p) if (*p == ',') commas++;
  ASSERT_EQ(commas, static_cast<int>(thermostat::kPanicBacktraceDepth) - 1);
}
#endif  // THERMOSTAT_RUN_TESTS
```

- [ ] **Step 2: Run the tests — verify they fail to compile**

Run: `pio run -e native-tests`
Expected: FAIL — `controller/panic_breadcrumb.h` does not exist.

- [ ] **Step 3: Create the record header**

Create `include/controller/panic_breadcrumb.h`:

```cpp
#pragma once

#include <stddef.h>
#include <stdint.h>
#include <stdio.h>

namespace thermostat {

// Magic marking a populated RTC record ('PNIC').
constexpr uint32_t kPanicBreadcrumbMagic = 0x504e4943u;
// Max backtrace frames captured. Fixed so the record is a POD of stable size.
constexpr size_t kPanicBacktraceDepth = 8;

// Plain-old-data record stamped by the panic handler into RTC_NOINIT memory.
// Must stay trivially-copyable and free of pointers/Strings so it survives a
// reset in no-init RTC RAM and can be unit-tested off-target.
struct PanicBreadcrumb {
  uint32_t magic;
  uint32_t core;
  uint32_t pc;  // faulting instruction address
  uint32_t depth;
  uint32_t backtrace[kPanicBacktraceDepth];
};

// True if the record holds a captured panic (valid magic and a non-zero PC).
inline bool panic_breadcrumb_present(const PanicBreadcrumb &b) {
  return b.magic == kPanicBreadcrumbMagic && b.pc != 0;
}

// Format as "core<N> pc=0x.. bt=0x..,0x.." into `out`. Writes "none" if the
// record is not present. The backtrace count is clamped to kPanicBacktraceDepth.
inline void panic_breadcrumb_format(const PanicBreadcrumb &b, char *out, size_t out_len) {
  if (out == nullptr || out_len == 0) return;
  if (!panic_breadcrumb_present(b)) {
    snprintf(out, out_len, "none");
    return;
  }
  size_t depth = b.depth;
  if (depth > kPanicBacktraceDepth) depth = kPanicBacktraceDepth;
  int n = snprintf(out, out_len, "core%lu pc=0x%08lx",
                   static_cast<unsigned long>(b.core),
                   static_cast<unsigned long>(b.pc));
  if (n < 0 || static_cast<size_t>(n) >= out_len) return;
  size_t pos = static_cast<size_t>(n);
  for (size_t i = 0; i < depth; ++i) {
    const char *sep = (i == 0) ? " bt=" : ",";
    int m = snprintf(out + pos, out_len - pos, "%s0x%08lx", sep,
                     static_cast<unsigned long>(b.backtrace[i]));
    if (m < 0 || static_cast<size_t>(m) >= out_len - pos) return;
    pos += static_cast<size_t>(m);
  }
}

}  // namespace thermostat
```

- [ ] **Step 4: Run the tests — verify they pass**

Run: `pio run -e native-tests && ./.pio/build/native-tests/program`
Expected: PASS, count increased by 4.

- [ ] **Step 5: Commit**

```bash
git add include/controller/panic_breadcrumb.h src/tests/test_panic_breadcrumb.cpp
git commit -m "feat(controller): add PanicBreadcrumb record (validate + format), native-tested"
```

---

## Task 2: Firmware panic hook + RTC record + boot recovery

**Files:**
- Create: `include/controller/panic_breadcrumb_hook.h`
- Create: `src/controller/panic_breadcrumb_hook.cpp`
- Modify: `platformio.ini` (controller env `build_flags`)

> Note: this firmware code compiles in the controller build but cannot be exercised by native tests (no panic off-target). It is verified here by (a) the controller firmware compiling/linking with the `--wrap` symbol resolved, and (b) deferred on-device validation (force a panic, confirm `state/panic_pc` reports a non-"none" value on the next boot). On-device validation uses the CURRENT controller, not the new board.

- [ ] **Step 1: Create the hook header**

Create `include/controller/panic_breadcrumb_hook.h`:

```cpp
#pragma once

#include <stddef.h>

namespace thermostat {

// Recover the panic breadcrumb left by the previous boot (if any), format it
// into `out` ("none" when absent or on power-on), and invalidate the record so
// it is reported once. Call once early in setup(). Firmware-only.
void panic_breadcrumb_recover_on_boot(char *out, size_t out_len);

}  // namespace thermostat
```

- [ ] **Step 2: Create the firmware hook implementation**

Create `src/controller/panic_breadcrumb_hook.cpp`:

```cpp
#include "controller/panic_breadcrumb_hook.h"

#if defined(ARDUINO)
#include <cstring>

#include "controller/panic_breadcrumb.h"
#include "esp_attr.h"
#include "esp_cpu.h"
#include "esp_debug_helpers.h"

extern "C" {
// Provided by ESP-IDF; the real handler we wrap.
void __real_esp_panic_handler(void *info);
}

namespace {
// No-init RTC RAM: survives panic/SW/WDT resets, not power-on/brownout (guarded
// by the magic). One record is enough — a panic ends the program.
RTC_NOINIT_ATTR thermostat::PanicBreadcrumb g_panic_breadcrumb;

// Capture the current call stack into the record. Called from panic context, so
// it must avoid locks/allocations — only writes RTC RAM and walks frames.
void capture_backtrace(uint32_t pc) {
  g_panic_breadcrumb.magic = thermostat::kPanicBreadcrumbMagic;
  g_panic_breadcrumb.core = static_cast<uint32_t>(esp_cpu_get_core_id());
  g_panic_breadcrumb.pc = pc;
  g_panic_breadcrumb.depth = 0;

  esp_backtrace_frame_t frame;
  esp_backtrace_get_start(&frame.pc, &frame.sp, &frame.next_pc);
  for (size_t i = 0; i < thermostat::kPanicBacktraceDepth; ++i) {
    if (frame.next_pc == 0) break;
    g_panic_breadcrumb.backtrace[i] = frame.pc;
    g_panic_breadcrumb.depth = static_cast<uint32_t>(i + 1);
    if (!esp_backtrace_get_next_frame(&frame)) break;
  }
}
}  // namespace

extern "C" void __wrap_esp_panic_handler(void *info) {
  // Best-effort: stamp the faulting PC (program counter) before the real handler
  // halts/reboots. esp_cpu_get_call_addr gives this frame's return address as a
  // stable proxy for "where we were" if the exact fault PC is unavailable here.
  capture_backtrace(reinterpret_cast<uint32_t>(__builtin_return_address(0)));
  __real_esp_panic_handler(info);
}

namespace thermostat {

void panic_breadcrumb_recover_on_boot(char *out, size_t out_len) {
  panic_breadcrumb_format(g_panic_breadcrumb, out, out_len);
  // One-shot: clear so the next boot reports "none" unless a new panic occurs.
  g_panic_breadcrumb.magic = 0;
  g_panic_breadcrumb.pc = 0;
}

}  // namespace thermostat

#else  // !ARDUINO

namespace thermostat {
void panic_breadcrumb_recover_on_boot(char *out, size_t out_len) {
  if (out != nullptr && out_len > 0) out[0] = '\0';
}
}  // namespace thermostat

#endif  // ARDUINO
```

- [ ] **Step 3: Add the linker wrap flag to the controller env**

In `platformio.ini`, under `[env:esp32-furnace-controller]`, append to the existing `build_flags` block (which currently ends with `-DIMPROV_WIFI_BLE_ENABLED`):

```ini
  -Wl,--wrap=esp_panic_handler
```

- [ ] **Step 4: Build the controller firmware — verify the wrap symbol resolves**

Run: `pio run -e esp32-furnace-controller`
Expected: SUCCESS. (A link error about `__real_esp_panic_handler` or `__wrap_esp_panic_handler` would mean the wrap flag or symbol name is wrong — fix before proceeding.)

- [ ] **Step 5: Run native tests (hook file is ARDUINO-guarded; must not break native)**

Run: `pio run -e native-tests && ./.pio/build/native-tests/program`
Expected: PASS, same count as Task 1 (hook contributes no native tests).

- [ ] **Step 6: Commit**

```bash
git add include/controller/panic_breadcrumb_hook.h src/controller/panic_breadcrumb_hook.cpp platformio.ini
git commit -m "feat(controller): capture panic PC+backtrace to RTC via esp_panic_handler wrap"
```

---
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

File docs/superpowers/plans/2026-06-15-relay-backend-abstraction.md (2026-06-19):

# Relay-Backend Abstraction Implementation Plan

> **For agentic workers:** REQUIRED SUB-SKILL: Use superpowers:subagent-driven-development (recommended) or superpowers:executing-plans to implement this plan task-by-task. Steps use checkbox (`- [ ]`) syntax for tracking.

**Goal:** Refactor `ControllerRelayIo` so its hardware writes go through an injected `RelayBackend` interface, with a `GpioRelayBackend` preserving today's exact behavior — the seam the ESP32-S3 board's PCA9554 backend will later plug into.
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

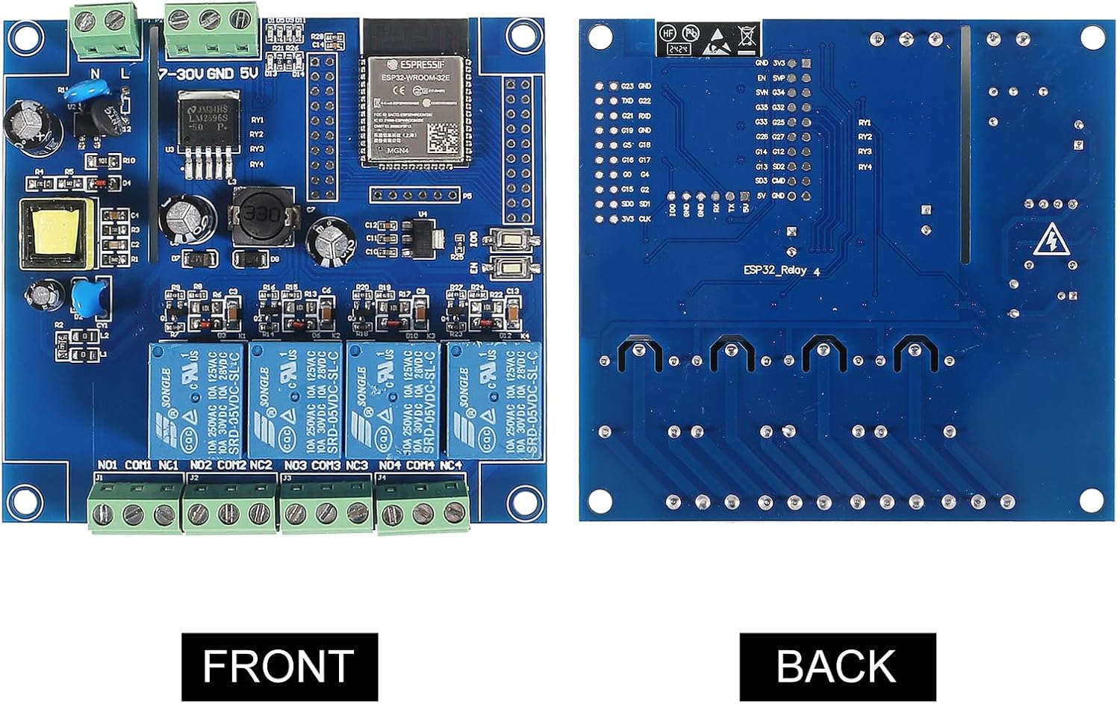
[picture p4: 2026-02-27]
hardware/esp32-controller-board-front-back.jpg

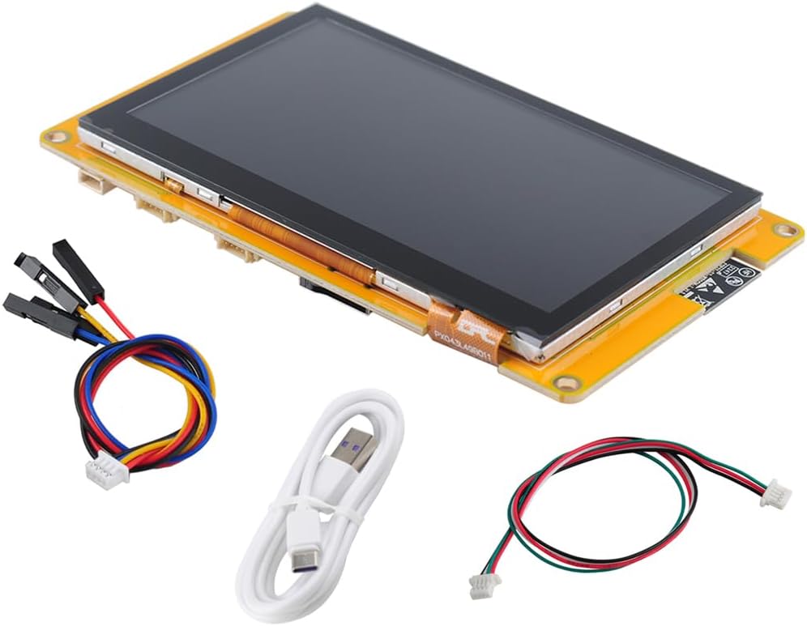
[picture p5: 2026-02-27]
hardware/esp32-s3-display.jpg

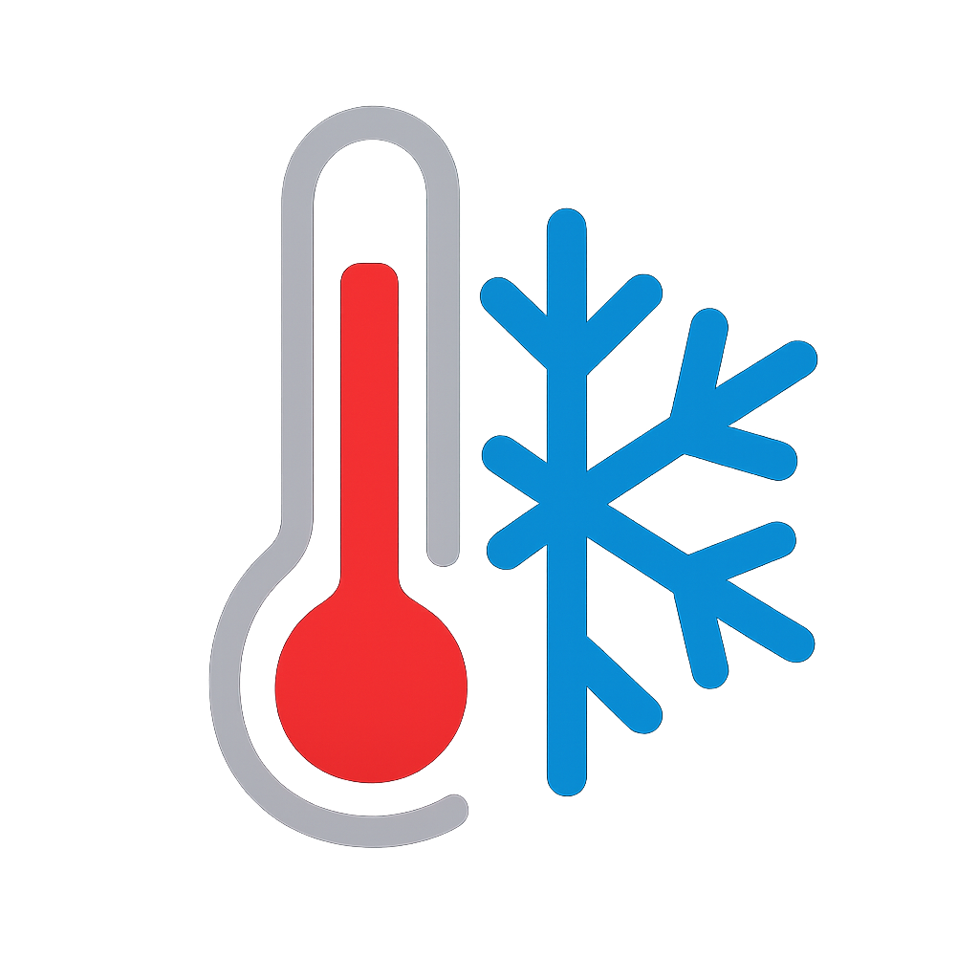
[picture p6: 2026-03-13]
docs/thermo2.png

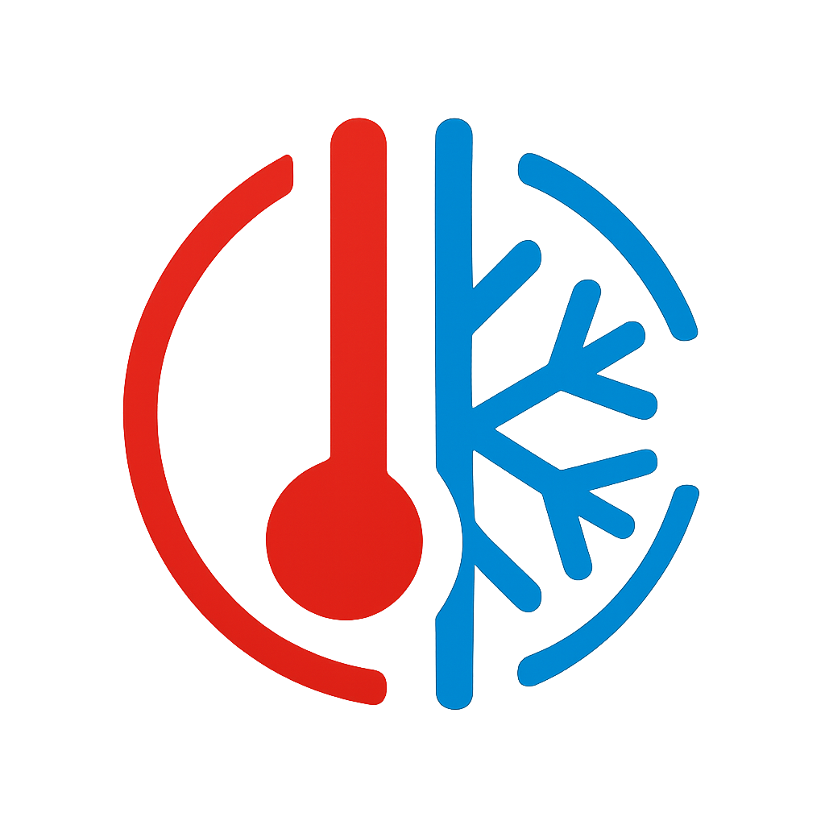
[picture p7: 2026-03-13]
docs/thermo1.png

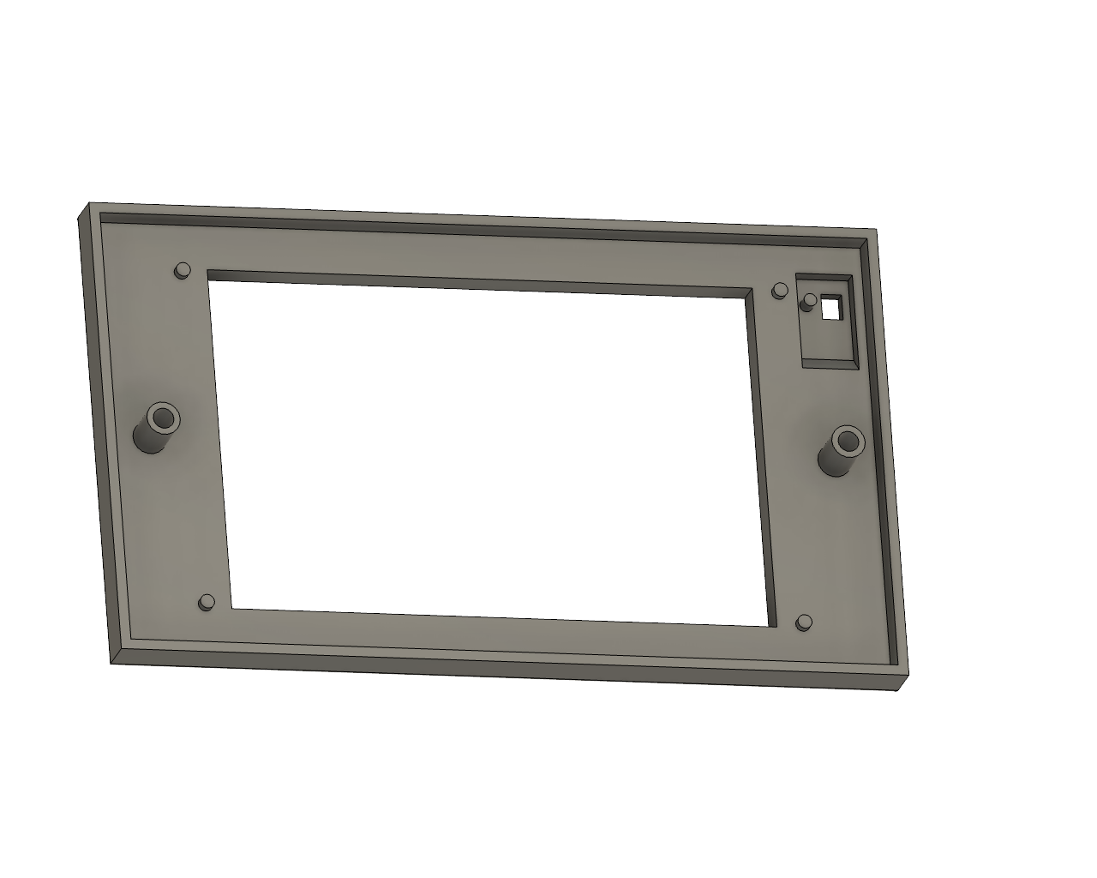
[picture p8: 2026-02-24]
enclosures/display_front.png

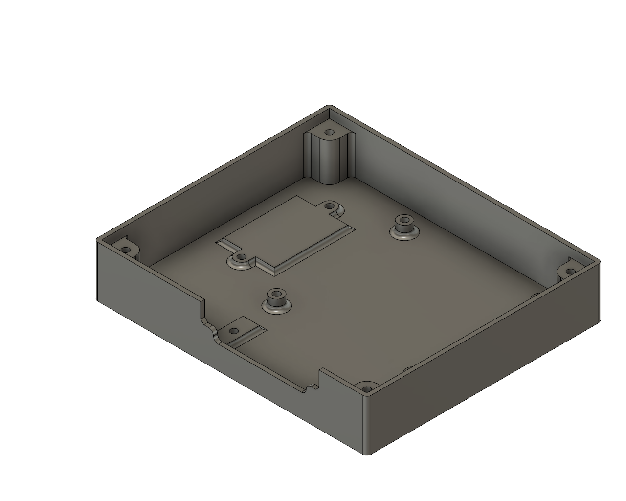
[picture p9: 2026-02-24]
enclosures/controller_base.png

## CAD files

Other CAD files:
enclosures/controller_v20.f3d
enclosures/display_v27.f3d

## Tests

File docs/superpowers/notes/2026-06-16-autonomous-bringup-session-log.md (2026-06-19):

# Autonomous Bring-up Session — Decisions Log (2026-06-16)

Working autonomously on the Waveshare ESP32-S3-ETH-8DI-8RO (real controller board) on
the piserial5 bench while the user is away. Board is wired to NOTHING except the Orange
Pi (USB) + Ethernet, so relays/WiFi/Ethernet are all safe to exercise freely. WiFi:
`RaspberryPie-Guest` / `12345678`. Branch `feat/controller-esp32s3-port` (PR #33).

**This file records decisions + findings for review. Items marked 🔵 NEEDS USER REVIEW
are choices I made on the user's behalf that they should confirm.**

## Goals for the session (Plan 4 bring-up, validated on the real board)
1. `Pca9554RelayBackend` — real relay backend (verified mapping) + safe-init.
2. PCF85063 RTC driver — network-independent time.
3. W5500 Ethernet bring-up (Ethernet cable is connected — get an IP).
4. WiFi bring-up (guest WiFi).
5. Full controller firmware on the board (board config + all of the above).
6. Validate resilience increments 1–2 on the real board.
7. Coredump partition (16 MB) + capture.

## Decisions

### D1 — Relay terminal → HVAC function mapping  🔵 NEEDS USER REVIEW
The user didn't specify which relay terminal (0–7) wires to heat/cool/fan. Since the
board is unwired (bench), the assignment doesn't affect testing. **Decision:** default
`heat=relay0, cool=relay1, fan=relay2, spare=relay3` (relays 4–7 unused), made
**configurable** in `Pca9554RelayBackendConfig`. **User: confirm the real wiring before
cutover** — if the furnace's W/Y/G land on different relay terminals, change the config
(one line) to match; no code change.

## Findings

### F1 — Relay control path VALIDATED on real hardware ✅
`ControllerRelayIo` (interlock) + `Pca9554RelayBackend` drive the real relays correctly
(serial trace via piserial5): HEAT→relay0 (PCA 0x01), switch to COOL→interlock forces
all-off + ~1s wait→relay1 (0x02), switch to FAN→off+wait→relay2 (0x04), OFF→0x00. The
Plan-1 abstraction + Plan-4 PCA9554 backend + the interlock all work end-to-end on the
Waveshare board. Default mapping heat=0/cool=1/fan=2 confirmed (see D1 for wiring review).

### F2 — On-board BUZZER (GPIO46) is uncontrolled at boot — must be silenced  🔵 IMPORTANT FOR REAL FIRMWARE
The board has a buzzer on GPIO46. With the pin left uninitialized at boot it can sound
(the user heard an "alarm"). **The real controller firmware MUST drive GPIO46 to its
off level (LOW) early in setup()** so the board is silent on boot. Added to the bench
sketches; needs to be in the production controller-s3 board init. (If LOW doesn't
silence it, the buzzer is active-low and needs HIGH — confirm on hardware.)
Possible future use: deliberate audible alerts (e.g. failsafe), but default = silent.

### F3 — PCF85063 RTC VALIDATED on real hardware ✅ + battery finding  🔵 USER: consider RTC battery
RTC driver read/set/tick confirmed on the board: read-before showed osc_ok=0 (time lost),
set 2026-06-16 12:00:00 -> osc_ok=1, seconds advance (oscillator runs). Decode/encode +
osc-stop flag all correct. **Finding:** the RTC backup (coin cell/supercap) is NOT
populated/charged (osc_ok=0 at boot = time not retained across power-off). The firmware
handles this (trust RTC only when osc_ok, else NTP), but **populating the RTC battery
would give instant correct time on cold boot** — recommend adding it for the cutover unit.

### F4 — Pca9554RelayBackend + PCF85063 RTC drivers: native-tested (176) + on-board validated.

## Remaining integration analysis (for the full controller firmware on the Waveshare)

### F5 — Controller has NO wall-clock time today  🔵 NEEDS USER INPUT (scheduling)
Grep confirms the controller never calls configTime/SNTP/getLocalTime — it has no
wall-clock time at all currently (only the thermostat `runtime()`). So the RTC is a
NEW capability. I'll wire the modest plumbing autonomously (read RTC on boot ->
settimeofday; SNTP sync -> write back to RTC; accurate log timestamps + an `rtc_ok`
diagnostic). But **what to DO with the time (time-of-day HVAC scheduling) is a product
decision** — what schedule, configured how (HA? on-device?) — so I'm NOT inventing a
scheduling feature autonomously. Flagging for review.

### Remaining Plan-4 integration increments (sized; doing the safe ones autonomously)
- **Board config (small, safe — doing it):** `CONTROLLER_BOARD_S3` currently uses the
  Feather stand-in `GpioRelayBackend{4,5,6,7}`. Switch it to `Pca9554RelayBackend`
  (verified mapping) + silence GPIO46 buzzer in setup() + Waveshare I2C pins. This makes
  the controller-s3 firmware target the real board's relays. Validate it builds + drives
  relays on the board.
- **RTC plumbing (medium — doing the plumbing, not scheduling):** read RTC on boot ->
  seed system time; SNTP -> RTC writeback; log timestamps. (Scheduling deferred, see F5.)
- **Ethernet-for-IP + WiFi-for-ESP-NOW-only (large — spec §2, needs care + likely user
  review):** the networking-model refactor (IP-link abstraction: Ethernet primary, WiFi
  radio only for ESP-NOW). This is the biggest remaining piece and changes the live
  network path substantially — I'll bring up Ethernet standalone first (validating now),
  then propose the integration rather than rewrite the live network path unsupervised.
- **Coredump (16MB partition) + identity override + cutover** — later.

### F6 — W5500 wired Ethernet VALIDATED on real hardware ✅  (the core value prop)
`ETH.begin(ETH_PHY_W5500, phy_addr=1, CS=16, IRQ=12, RST=-1, SPI2_HOST, SCK=15, MISO=14,
MOSI=13)` returns ok; link comes up and **DHCP gets an IP**: serial trace showed
`linkUp=1 IP=10.0.2.43 speed=100Mbps FD mac=3A:0F:02:CC:EE:2D` (took ~6s from boot to
lease). RST pin = **-1 works** (no dedicated reset needed; W5500 self-resets). This is
the whole reason for the port — a wired link to end the marginal-WiFi reboots — and it
works on the real board. Bench sketch `src/bench/waveshare_eth_validate.cpp`, env
`waveshare-eth-validate` (hybrid build — the ETH/Network stack needs the IDF source
rebuild, same as the panic-wrap path). Note: bench LAN handed out 10.0.2.x; production
will be on the user's normal LAN. MAC is chip-MAC+derived (locally administered).

## Board-config integration (Plan 4) — full controller firmware targets the real board

### What I did (committed, building/validating)
Added a **`CONTROLLER_BOARD_WAVESHARE`** board profile to the real controller firmware
(`src/esp32_controller_main.cpp`), distinct from the generic-S3 bench profile:
- Relay backend: `Pca9554RelayBackend` (verified mapping heat0/cool1/fan2/spare3) instead
  of the Feather `GpioRelayBackend` stand-in. Mutually exclusive via `#elif`.
- Buzzer: `pinMode(46,OUTPUT); digitalWrite(46,LOW);` as the **first** statement in
  setup() (before Serial), gated to the Waveshare board.
- New env `[env:esp32-furnace-controller-waveshare]` — extends the s3 hybrid env, 16MB
  flash + `default_16MB.csv` (which already carries a coredump partition), `-DCONTROLLER_BOARD_WAVESHARE`.

### Scope boundary (deliberate — NOT done autonomously)
This makes the firmware **build for + boot on** the real board with correct relay + buzzer
hardware. It does **NOT** yet rewire the network path to Ethernet — main still uses WiFi
for IP today (the Ethernet-for-IP refactor is the large §2 piece flagged for review). So
on the bench this firmware boots, drives the real relays safe-off, stays silent, and (with
no WiFi creds) sits in provisioning — exactly the boot/hardware checkpoint intended. Kept
the **isolated TEST identity** (test base topic + ESP-NOW ch11/test-LMK) so it can never
touch production until the cutover step.

### F7 — Full controller firmware BOOTS CLEAN + STABLE on the real board ✅
Flashed `esp32-furnace-controller-waveshare` (1.48MB, 22.6% of app slot, 21.2% RAM) to
the real Waveshare board and read the boot:
- buzzer SILENT (GPIO46 LOW ran first — no alarm);
- `panic_pc=none wdt_section=none`, `Reset reason: other | last reboot cause: none` (clean);
- `controller_node_begin=1` → `g_relay_io.begin()` → `Pca9554RelayBackend.begin()` found the
  expander and set relays safe-off with NO I2C hang/error (begin() contract holds on real HW);
- isolation watchdog armed; `controller alive` heartbeat every 5s for 40s — **no panic, no
  watchdog reset, no reboot**: stable.
- Correctly entered BLE provisioning (fresh NVS, no WiFi creds) — confirms Ethernet is NOT
  yet wired into main (still WiFi-for-IP). NVS NOT_FOUND lines = expected first-boot noise.
Milestone: the real production firmware runs on the real board driving the real relay
hardware, silent and stable. Plan-4 hardware bring-up is functionally COMPLETE.

### F8 — Crash COREDUMP capture VALIDATED end-to-end on real hardware ✅  (closes panic-diagnostics gap)
Built `waveshare-coredump-validate` (sketch deliberately crashes, reboots, then checks
`esp_core_dump_image_get()`). On the real board:
- boot1: no coredump -> 8s countdown -> null-ptr write -> `Guru Meditation StoreProhibited`,
  `EXCVADDR=0x00000000`, PC `0x42002011`; IDF wrote the coredump + rebooted;
- boot2: **`[coredump] PRESENT in flash: addr=0x00FF0000 size=12100 bytes`** — address matches
  the `coredump` partition in default_16MB.csv exactly; CAPTURE VALIDATED; erased clean.
- **Coredump is enabled by default** in the Arduino-ESP32 framework sdkconfig
  (`CONFIG_ESP_COREDUMP_ENABLE_TO_FLASH=y`, `DATA_FORMAT_ELF=y`, `CHECK_BOOT=y`) — so the
  ONLY thing needed was a partition table with a `coredump` partition (already in the 16MB
  layout / waveshare env). No sdkconfig change required.
- **Symbolication works**: addr2line on the env's firmware.elf resolved PC `0x42002011` ->
  `waveshare_coredump_validate.cpp:73` (the exact crash line) with a clean backtrace.
- Host-side full-coredump decode (`esp-coredump info_corefile`) needs xtensa-esp32s3-elf-gdb,
  which isn't installed on this dev box (and piserial5 is offline). Not blocking: the
  on-serial register dump + addr2line give the same symbolication, and the coredump is now
  captured in flash for offline `esp-coredump`/gdb analysis whenever needed.
**Impact:** directly closes the open "controller panics on new firmware, no coredump/backtrace
available" issue — once the Waveshare firmware is deployed, that panic WILL be captured.

## Code review of this session's firmware changes (esp-idf-engineer subagent)
Reviewed the board-config integration + bench sketches + envs. **No critical issues.**
Verified correct: macro mutual-exclusion (WAVESHARE/S3/classic — the only two
CONTROLLER_BOARD_S3 sites are both WAVESHARE-aware), buzzer placement, `extends`+override
semantics with all parent build_flags correctly re-listed, isolated test identity, and the
coredump API usage. Two "important" items + dispositions:
- **(a) PSRAM not enabled** despite N16R8's 8MB. **Disposition: intentional** — firmware fits
  in internal SRAM (~21%); enabling octal PSRAM needs pin-collision verification (W5500
  SPI/PCA9554 I2C/relays). Clarified the env comment to say so explicitly.
- **(b) Verify PCA9554 begin() doesn't briefly energize relays at boot** (highest-consequence
  for a furnace). **Disposition: already hardware-validated** — F1 showed `begin()` → PCA
  input 0x00 (all off); the backend writes the output register all-OFF *before* switching
  pins to outputs (POR default is outputs-high), and F7's clean boot confirmed no glitch.
Nits (not actioned): build_flag duplication across s3/waveshare envs (hoist to a common
section only if edited often); W5500 RST=-1 is bench-only (wire a real RST for production
warm-reboot link recovery); buzzer-silence snippet duplicated across 3 bench sketches.

## Wrap-up — what's DONE vs. what needs Ryan

### DONE autonomously this session (all committed + pushed to PR #33)
- ✅ Relays (Pca9554RelayBackend control path), RTC (PCF85063), W5500 Ethernet (DHCP),
  buzzer silence — all validated on the REAL board.
- ✅ `CONTROLLER_BOARD_WAVESHARE` firmware profile + env; full controller firmware boots
  clean + stable on the real board (relays safe, silent, no reboot).
- ✅ Coredump capture validated end-to-end (panic → coredump in flash → readable) +
  addr2line symbolication. Closes the open "no coredump" panic-diagnostics gap.
- ✅ Regression-checked: native tests 176/0; classic esp32dev controller still builds clean.
- ✅ Code-reviewed (esp-idf-engineer), no critical issues.

### NEEDS RYAN (recorded, not done — by design)
1. **🔵 D1 — relay→HVAC wiring:** confirm which relay terminal (0–7) is heat/cool/fan before
   cutover (one-line config if different from default 0/1/2).
2. **🔵 F3 — RTC battery:** consider populating the RTC backup cell for cold-boot time.
3. **🔵 F5 — RTC scheduling:** product decision (what to DO with wall-clock time). Plumbing
   I'll do; scheduling I won't invent.
4. **Ethernet-primary networking plan** — written:
   `docs/superpowers/plans/2026-06-16-ethernet-primary-networking.md`. Has 4 OPEN DECISIONS
   (WiFi fallback? watchdog reboot policy? keep BLE provisioning? static IP/DHCP reservation?)
   that need your answer before I execute it. Good news: the refactor is smaller than feared
   (lwIP already makes the MQTT/web/OTA clients link-agnostic).
5. **Resilience inc 1–2 on-device validation** — needs a controllable MQTT-unreachable bench
   (and, for the Ethernet plan, a broker reachable on the Ethernet LAN).
6. **Identity override + production cutover.**

## Ethernet-primary networking — IMPLEMENTED + VALIDATED on hardware ✅ (Ryan's decisions applied)
Executed `docs/superpowers/plans/2026-06-16-ethernet-primary-networking.md` after Ryan
confirmed: **no WiFi fallback** + **watchdog reboots only on isolation**. All changes gated
to `CONTROLLER_BOARD_WAVESHARE` (classic esp32dev untouched).
- Added `ctrl_ip_link_up()` / `ctrl_ip_local_addr()` helpers — the only place that knows the
  primary link. On Waveshare → Ethernet (`ETH.hasIP()`/`ETH.localIP()`); on classic → WiFi
  STA (reduces to the exact prior behavior, zero change).
- `ETH.begin(W5500, ...)` in setup() (Waveshare); ETH GOT_IP/DISCONNECTED handled in the
  net event handler. WiFi-creds provisioning **skipped** on Waveshare (WiFi = ESP-NOW only).
- Replaced the WiFi-status gates (web, mDNS, MQTT-connect, weather, announce×2, heartbeat,
  status JSON, OTA rollback) with the link helpers. RSSI stays WiFi-specific (0/omitted on
  Ethernet-only — correct).
- loop(): `ctrl_ensure_wifi_connected` + `wifi_watchdog_tick` skipped on Waveshare; the
  isolation watchdog (MQTT && ESP-NOW down >15min) is the SOLE reboot authority.

### F9 — on-board validation (fresh NVS, Ethernet to the bench LAN)
- `[eth] ETH.begin() -> ok` → `[eth] GOT_IP 10.0.2.43 link=100Mbps FD`.
- **No BLE provisioning** (`prov=idle`) — correctly skipped; `controller_node_begin=1`
  (ESP-NOW up with WiFi radio, no association).
- Heartbeat `ip=10.0.2.43, mqtt=yes` — **MQTT connected OVER ETHERNET** to the default broker
  `mqtt.lan` (resolved via DNS over the W5500), under the isolated TEST base topic. Proves
  the full DHCP→DNS→TCP→MQTT stack works over Ethernet with ZERO WiFi association — the
  link-agnostic-client theory holds exactly as planned.
- Stable for 30s+, no reboot. Builds: Waveshare clean (RAM dropped 21.2%→19.8% since WiFi
  provisioning no longer runs); native tests 176/0.
**This is the core deliverable of the whole port — the controller now runs on a wired link,
ending the marginal-WiFi reboot problem that started this work.**

### Code review of the Ethernet-primary refactor (esp-idf-engineer)
PASS overall: classic-path invariance confirmed (helpers reduce to the exact prior
WiFi.status()/localIP() behavior), String temporaries safe in every printf callsite,
ESP-NOW/ETH init ordering correct, `provisioning_active()` safe on the never-begun manager,
no new unused-var warnings. One **important** finding actioned:
- **3a — masked ETH.begin() failure / no retry:** a transient W5500 init failure would leave
  the board permanently IP-dark, and because ESP-NOW still works the isolation watchdog
  wouldn't catch it (not "isolated") → no auto-recovery. **Fix:** bounded 3× retry of
  ETH.begin() at boot (recovers transient SPI/PHY failures); if all fail, run ESP-NOW-only
  rather than reboot-loop on dead hardware (respects "reboot only on isolation").
- **nit 5 (actioned):** added a comment at the loop's WiFi-gate documenting the
  "stray wifi_ssid write persists creds but never associates (ensure_connected is gated out)
  → ESP-NOW channel pinning stays safe" invariant.
Other nits (heartbeat double-eval; announce-IP freshness self-heals on MQTT reconnect after a
flap-with-new-IP) noted, no action needed.

## RTC + SNTP time plumbing — IMPLEMENTED + VALIDATED on hardware ✅
Wired the PCF85063 RTC + SNTP into the controller firmware (Waveshare-gated). Scheduling
(use of wall-clock time) stays deferred — this is just time-keeping.
- **Pure conversions** `rtc_time_to_epoch`/`rtc_time_from_epoch` added to `pcf85063_rtc.h`
  (Howard Hinnant civil-date math — no libc/TZ, platform-agnostic) + 4 native tests
  (known value, epoch-0/Thursday, round-trip, leap day). Native tests 176→**180**, 0 fail.
- **Boot:** read RTC; if oscillator-OK, `settimeofday()` seeds the system clock (UTC).
- **SNTP:** once Ethernet has IP, `configTime(0,0, <ETH gateway>, "pool.ntp.org")` (UTC).
  Server names kept in a persistent global String (configTime stores the pointer).
- **NTP writeback:** on a REAL sync (SNTP notification callback) write system time back to
  the RTC; refresh hourly. The RTC stores correct UTC thereafter.
- **Telemetry:** `state/time_source` (rtc|ntp|none), `state/rtc_present`, `state/time_utc`.

### Bug found + fixed during bring-up (good catch)
First cut gated the RTC-writeback on `time(nullptr) > sane_epoch` ("clock is set"). That is
true the instant the RTC seed runs, so it fired "RTC updated from NTP" immediately, before
SNTP even started, and mislabeled the source as ntp. Fix: detect a real NTP sync via
`sntp_set_time_sync_notification_cb()` and gate the writeback + source="ntp" on that flag.

### F10 — on-board validation
`[time] seeded from RTC: 2026-06-16T14:00:15Z` → `[time] SNTP started (servers: 10.0.0.1,
pool.ntp.org)` → `[time] RTC updated from NTP: 2026-06-16T04:51:09Z`. The RTC held a STALE
nominal time (14:00, left over from the earlier driver test that set "12:00"); NTP corrected
it to true UTC and wrote it back — exactly the intended behavior, and the premature-writeback
bug is gone (writeback now strictly follows the sync). Note: full correct-time-on-cold-boot
still wants the RTC battery (F3); on USB-power resets the oscillator persists, and NTP
corrects within seconds of Ethernet up regardless.
Future nicety (not done): wall-clock timestamps in the audit log.

## Resilience increments — ON-DEVICE VALIDATION + a real bug found & fixed
Set up an ISOLATED test broker (Dockerized mosquitto on the dev box, 192.168.154.20) so we
never touch the house mqtt.lan. Repointed the bench board's mqtt_host to it via the web UI
(POST /config). Board connected over Ethernet under the test base topic.

### Inc 1+2 (MQTT recovery) — VALIDATED ✅
Broker outage/recovery cycles: MQTT goes down → recovery policy backs off (capped
exponential) and escalates to RestartSubsystem at ~33s cadence (audit log) — NOT a tight
loop (the old pre-fix bug) — and reconnects when the broker returns. The MQTT policy never
reboots (reboot_enabled=false). Confirmed over 4 consecutive outage/recovery cycles.

### F11 — REAL BUG found via the validation: spurious weather-wedge reboot ✅ FIXED
First outage cycle rebooted the board. Diagnostics (the panic/reboot breadcrumb we built!)
said `reboot_reason=weather_wedge: ...heartbeat stale uptime=730s`, `reset_reason=software`,
`panic_pc=none`. Root cause (math-proven, can't fire at 730s with a 30min threshold unless
the unsigned subtraction wrapped): `ctrl_poll_weather` compared the loop-top `now` against
the weather task's heartbeat with UNSIGNED arithmetic. `now` is captured once at loop top;
the heartbeat is updated concurrently by the weather task (core 0). On an MQTT reconnect the
loop BLOCKS for connect + 19 subscribes + the discovery/state publish burst (100s of ms to
seconds), so the weather task pushes the heartbeat AHEAD of the stale `now` → `(now -
heartbeat)` underflows to ~4.29e9 > threshold → spurious esp_restart.
- **This is very likely the ORIGINAL "weather task wedging → 30-min outages" symptom** that
  started the whole project, and it is NOT board-gated → affects the production esp32dev too.
- **Fix:** pure native-tested `weather_heartbeat_wedged()` (include/controller/weather_watchdog.h)
  using SIGNED millis() arithmetic (a heartbeat ahead of `now` = fresh; real staleness =
  wedged; wrap-safe). 8 native tests (188 total).
- **Validated on hardware:** after the fix the board survived 4 outage/recovery cycles with
  ZERO spurious reboots (uptime monotonic), while MQTT recovered each time. Builds:
  Waveshare + classic clean.

NOTE: bench has no ESP-NOW peer, so any MQTT outage >15min would (correctly) trip the
isolation watchdog reboot — kept test outages ~20s to isolate the MQTT-policy behavior.
NOTE: the board briefly published HA discovery to mqtt.lan under the TEST topic during the
earlier Ethernet/RTC validation; offered to clean up those retained test-topic messages.

## Resilience inc 3-4 (design 2026-06-16-resilience-3-4-design.md) — A & C done, B pending
- **Piece A — weather TLS handshake timeout (8s, was 120s default):** shipped to PRODUCTION
  (PR #35, squash-merged to main). Hardening on top of the weather-wedge signed-comparison
  fix. NOT yet OTA'd to the live controller (low urgency — user's call).
- **Piece C — isolation watchdog recovers in place (inc 4b):** done on S3 branch (ba0ba73).
  On Waveshare, prolonged isolation now triggers ESP-NOW re-init (new
  EspNowControllerTransport::restart() = esp_now_deinit -> begin) + forced MQTT reconnect,
  3min grace, THEN reboot as last resort. Classic unchanged (board-gated — re-pinning the
  channel would disrupt WiFi assoc). Hardware-validated: ESP-NOW re-init runs with no crash;
  isolate->recover->grace->reboot('recovery failed') works; broker-returns->reconnect-no-reboot
  works. Native 188, Waveshare+classic clean.
- **Piece B — MQTT off the control loop (inc 3, the big one):** NOT started. Deferred to a
  dedicated, staged, heavily-reviewed pass (command-queue + dual-task; ~50 publish sites on
  the relay-control hot path). Justified by: kCtrlTaskWdtTimeoutMs=15s vs a ~5s+ MQTT
  connect/subscribe/publish block on the loop task = real task_wdt panic exposure.
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

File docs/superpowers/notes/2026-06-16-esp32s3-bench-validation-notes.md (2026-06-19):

# ESP32-S3 Bench-Validation Notes (learnings)

Hard-won learnings from bringing up the controller firmware on a stand-in
**Adafruit Feather ESP32-S3 (8 MB, no PSRAM)** to validate Plan 2 (panic
breadcrumb) and the Plan 4 board port. Captured so the next person (or the real
Waveshare bring-up) doesn't re-derive them.

## 1. pioarduino S3 build config (platform-espressif32 55.03.37)

- **`network_provisioning/network_config.h: No such file`** — the prebuilt Arduino
  `Network` lib includes this header (gated by `CONFIG_NETWORK_PROV_NETWORK_TYPE_WIFI`),
  but it isn't shipped in the prebuilt framework. Fix: trigger the **hybrid source
  build**, which regenerates `sdkconfig` with `network_provisioning` removed (so the
  `#if` is false and the include is skipped).
- **The hybrid build is triggered by `custom_sdkconfig`**, NOT by `custom_component_remove`
  alone. The production controller/thermostat envs set both. A single benign line
  (`CONFIG_ESP_DEFAULT_CPU_FREQ_MHZ_240=y`) is enough to switch modes; then
  `custom_component_remove` (incl. `espressif/network_provisioning`) takes effect.
- **It's stateful/flaky:** a plain `pio run` after a partial/failed hybrid attempt can
  fall back to the prebuilt path and re-fail. Reliable sequence: `pio run -e <env> -t clean`
  **then** `pio run -e <env>` from a clean build dir. Remove stray auto-generated
  `sdkconfig.defaults` / `sdkconfig.<env>` from the project root if a build half-completed.
- **Partition CSV is resolved from the PROJECT ROOT in IDF/hybrid mode**, not the
  framework. The repo already vendors `default_16MB.csv` + `partitions_no_spiffs.csv`;
  we added `default_8MB.csv` the same way for the S3 env.
- First hybrid build is slow (~10 min, rebuilds ESP-IDF); then cached.

## 2. Avoiding all of the above for a quick test: the minimal selftest env

For pure logic validation that doesn't need WiFi/MQTT, build **only the file under test
+ its deps** (`build_src_filter = -<*> +<bench/...> +<...>`) with **no `lib_deps`**. With
no networking pulled in, the Arduino `Network` lib never compiles, so the
`network_provisioning` issue never arises and the build is a fast (~13 s) prebuilt build.
See `[env:s3-panic-selftest]`.

## 3. ESP32-S3 USB / serial — the part that actually blocked us

The Feather's only USB goes to the S3's native USB pins, shared by two peripherals
selected at build time (`ARDUINO_USB_MODE`):

| Mode | Device | DTR/RTS behavior | Reading it |
|---|---|---|---|
| `USB_MODE=1` (HWCDC / USB-Serial-JTAG) — devkitc-1 default | `303a:1001` | **Interpreted as EN/GPIO0** (auto-download) | Opening the port pulses reset → chip drops to **download mode**. Hostile to passive reads. |
| `USB_MODE=0` (TinyUSB CDC) — Feather default | `239a:8113` | **Ignored** | Opening the port does NOT reset the chip. Use this for headless reads. |

- **`pio device monitor` can't run headlessly** — it `tcgetattr()`s the console to go
  raw; with piped stdin (no TTY) it dies with `termios.error: Inappropriate ioctl`. Not
  a pio bug — interactive monitors need a real terminal. Use `python -m serial`/`cat`
  for non-interactive capture instead.
- **Resetting the S3 out of download into the app:** `esptool --after hard_reset`
  was unreliable over the JTAG; **`esptool --after watchdog_reset`** is the
  USB-Serial-JTAG-safe one.
- **First flash of a board running app-firmware needs download mode:** hold BOOT, tap
  RESET, release BOOT → enumerates as `303a:1001` (ROM USB-Serial-JTAG), then flashable.
  Avoid *double*-tapping RESET on Adafruit boards (that's the UF2 mass-storage bootloader).

## 4. The wall: KVM USB passthrough

The dev VM is **KVM with USB passthrough** (`systemd-detect-virt=kvm`, QEMU tablet in
`lsusb`). The passthrough **cannot keep up with the S3's re-enumeration on every
reset/boot** — flashing works (device sits still in download mode), but the moment the
chip resets to run and re-enumerates, the passthrough drops the `/dev/ttyACM` node
(observed: device dropping even at idle, and `opens=0` for 36 s straight). No firmware
or tooling change fixes this; it's below the OS.

## 5. The fix: drive a board on a real host (remote bench)

`piserial5.lan` = **Orange Pi (aarch64, Ubuntu Jammy), `virt: none`, native USB**,
reachable on the LAN, SSH as `ryan` via key auth, in `sudo`+`docker` groups (not
`dialout` — `sudo chmod` the port, like locally). Has `python3`+`nc` but **needs
`esptool`+`pyserial`** (`pip install --user esptool pyserial`).

Workflow to validate on the remote bench:
1. Move the board to a piserial5 USB port (native USB → stable across resets).
2. Build firmware **here** (full pio toolchain), `scp` the artifacts
   (`bootloader.bin` @0x0, `partitions.bin` @0x8000, `boot_app0.bin` @0xe000,
   `firmware.bin` @0x10000) to piserial5.
3. SSH in; `sudo chmod a+rw /dev/ttyACM*`; flash with `esptool ... write_flash ...`;
   read serial with a small pyserial/`cat` reader (TinyUSB build → reads don't reset).
4. (Alt) `esptool` also supports `--port rfc2217://piserial5.lan:PORT` if an
   `esp_rfc2217_server` is run on the Pi — flash+reset entirely from here, no scp.

## 6. What this validated — and the BUG it found

- ✅ Controller firmware **and** the minimal selftest **build for ESP32-S3** (real
  de-risk for Plan 4).
- ✅ Flashing + verifying works over the JTAG link.
- ✅ **Remote bench works:** reading the Feather on piserial5's native USB (via the
  stable `/dev/serial/by-id/...` symlink + a reconnecting `cat` loop) captured the
  serial cleanly across reboots — what the KVM passthrough never could.
- 🛑→✅ **BUG FOUND (Plan 2) and ROOT-CAUSED + FIXED.** On-device the selftest
  **panic-looped**: every boot reported `recovered breadcrumb: none`, forced the
  panic, rebooted, repeated. The native unit tests pass (they cover
  `panic_breadcrumb_format`/`_present`, not the on-silicon capture-across-reset),
  which is exactly why this needed on-device validation.
  - **Root cause (found by inspection, no hardware): the firmware was not linked with
    `-Wl,--wrap=esp_panic_handler`.** The Arduino core's `set_arduino_panic_handler()`
    path only works when that wrap flag redirects `esp_panic_handler` to the core's
    `__wrap_esp_panic_handler` (which calls the registered callback). Arduino IDE adds
    the flag via `platform.txt`; **PlatformIO/pioarduino does NOT** (confirmed: the
    real link had `--wrap=log_printf`/`--wrap=longjmp` but not `esp_panic_handler`).
    So `on_panic` was dead code → breadcrumb never written. This affected EVERY
    PlatformIO build, incl. the production controller — the breadcrumb has never worked.
  - **Fix:** add `-Wl,--wrap=esp_panic_handler` via a shared `[panic_wrap]` ini
    section to the controller / controller-s3 / selftest envs (commit on the branch).
    Confirmed the flag is now in the link; builds clean.
  - ✅ **FIX VALIDATED ON HARDWARE (2026-06-16, via piserial5, button-free).** After
    flashing the fixed firmware: boot1 panics, **boot2 recovers `core1 pc=0x42002579
    bt=0x42002576,0x42005e38,0x4037b891`** and idles (no re-loop). addr2line resolves
    those to `loop() at panic_selftest.cpp:51` (the deliberate null write) → `loopTask`
    → `vPortTaskWrapper` — exact crash site + correct backtrace. The breadcrumb works.

### Button-free flashing of the Feather over SSH (the recipe that worked)
piserial5 is offline, so: download the **standalone esptool aarch64 binary** on a
machine with internet (`github.com/espressif/esptool/releases` →
`esptool-vX-linux-aarch64.tar.gz`), `scp` + untar it onto piserial5. Then, all over SSH:
1. **udev rule** so re-enumerated ESP ports are readable without the dialout group:
   `SUBSYSTEM=="tty", ATTRS{idVendor}=="303a", MODE="0666"` (+ `239a`/`8113`);
   `sudo udevadm control --reload-rules && sudo udevadm trigger`.
2. **1200-baud touch → ROM download mode** (no BOOT button!): `stty -F <feather-tty> 1200 hupcl`.
   The Adafruit ESP32-S3 TinyUSB CDC reboots to the **303a USB-Serial-JTAG download** unit
   (NOT UF2) — stable, since download mode doesn't run the looping app. A clean by-id
   appears: `usb-Espressif_USB_JTAG_serial_debug_unit_<MAC>-if00`.
3. **Flash** via that JTAG port: `sudo esptool --chip esp32s3 --port <jtag-byid>
   --after hard_reset write_flash 0x0 bootloader.bin 0x8000 partitions.bin 0xe000
   boot_app0.bin 0x10000 firmware.bin` (offsets from `pio run -t upload -v`).
4. **Read** the booted app via the Feather TinyUSB by-id (`usb-Adafruit_Feather...`)
   with a reconnecting `cat` loop (TinyUSB ignores DTR/RTS → reads don't reset it).

This is a fully remote, button-free flash→read→validate loop on a real host.
  - General lesson: **any Arduino-core feature gated behind a `platform.txt`
    `compiler.*.elf.flags` linker flag is silently absent under PlatformIO.** Check the
    actual link (`pio run -v | grep -- --wrap`) when a core hook "does nothing."

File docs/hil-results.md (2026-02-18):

# HIL Results Log

Use this file to record each hardware validation run.

## Run Template
- Date:
- Operator:
- Controller firmware:
- Display firmware:
- Checklist reference: `docs/hil-checklist.md`
- Result: PASS / FAIL
- Notes:

---

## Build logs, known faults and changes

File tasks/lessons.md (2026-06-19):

# Lessons Learned

## ESP32-S3 RGB LCD Display

### Bounce buffer DMA shift (intermittent wrapping/artifacts)
- **Symptom**: Top lines of display wrap to bottom, visual artifacts appear intermittently
- **Root cause**: PSRAM bandwidth contention between bounce buffer DMA, WiFi, and flash cache
- **Why ESPHome works but Arduino doesn't**: ESPHome compiles ESP-IDF from source with `CONFIG_SPIRAM_FETCH_INSTRUCTIONS=y` and `CONFIG_SPIRAM_RODATA=y`, which moves flash code/rodata into PSRAM and frees the flash cache bus. The pioarduino pre-built Arduino libraries have these options **disabled** in their sdkconfig.
- **What doesn't fix it**: Changing porch timing values, lowering pixel clock, increasing bounce buffer size, `direct_mode`, semaphore drain, `esp_lcd_rgb_panel_restart()`, `bb_invalidate_cache`. These are all mitigations, not fixes.
- **Real fix** (implemented): Use HybridCompile (`custom_sdkconfig` in platformio.ini) to rebuild ESP-IDF from source. Must also use `custom_component_remove` to strip ~23 unused managed components (esp_insights, esp_rainmaker, zigbee, esp-sr, etc.) that would break the build. Also add `lib_ignore` for unused Arduino-level libs.
- **Constraint**: `CONFIG_LCD_RGB_RESTART_IN_VSYNC=y` is already enabled in the pre-built libs but insufficient without the SPIRAM XIP options.

### LCD timing parameters
- The ESP32-8048S043C (Sunton board) works with porch values of 8/8/4 at 14 MHz pixel clock
- Increasing porches to datasheet values (hsync_bp=46, hsync_fp=210) causes the panel to fail to initialize (black screen/color bars)
- Pixel clock below ~12 MHz also causes initialization failure
- The original timing values (8/8/4 all around, 14 MHz) are the only working combination found

### LVGL configuration for panel-owned double buffers
- `full_refresh = 1` AND `direct_mode = 1` should both be set
- `LV_MEM_SIZE` at 48 KB is too small (device hangs during UI init), 128 KB works
- The LVGL heap is internal SRAM — reducing it too aggressively causes silent hangs

## Build system

### pioarduino `-D` flags vs sdkconfig
- `-D` build flags only affect application code compilation, NOT pre-compiled ESP-IDF libraries
- `CONFIG_SPIRAM_FETCH_INSTRUCTIONS`, `CONFIG_SPIRAM_RODATA`, `CONFIG_LCD_RGB_RESTART_IN_VSYNC` as `-D` flags have NO effect on framework behavior
- Must use `custom_sdkconfig` (HybridCompile) to actually change these options

### PubSubClient default buffer
- Default `MQTT_MAX_PACKET_SIZE` is 256 bytes — must call `setBufferSize(1024)` for HA discovery payloads

### Firmware version stamp reflects the build-time git state
- `firmware_version` is generated from `git describe --tags --dirty` at build time.
- If you build before committing, the binary is stamped with the *previous* commit + `-dirty`, even though it contains your uncommitted edits. The flashed code is correct but the version label is misleading.
- **Before flashing: commit first, then (re)build, then flash** — so the embedded version matches the deployed commit. Verify with `strings firmware.bin | grep 'v[0-9]'`.

### PlatformIO silently drops `platform.txt` linker flags
- Arduino-IDE-only build flags live in the framework's `platform.txt` (e.g. `compiler.c.elf.flags` has `-Wl,--wrap=esp_panic_handler`). **PlatformIO/pioarduino does NOT read `platform.txt`**, so any Arduino-core feature gated behind such a flag is silently inert under PlatformIO.
- This is how the panic-PC breadcrumb "passed" unit tests but did nothing on hardware: `set_arduino_panic_handler()` needs `-Wl,--wrap=esp_panic_handler` to redirect `esp_panic_handler` → the core's `__wrap_esp_panic_handler` (which calls the callback). Without the flag the callback is never invoked.
- **When an Arduino-core hook "does nothing," check the actual link:** `pio run -e <env> -v 2>&1 | grep -- '--wrap'`. Re-add any missing `platform.txt` link flags in `platformio.ini` `build_flags`.
- Corollary: **on-device validation catches what unit tests can't.** Linker/runtime/RTC behavior is invisible to native tests.

### `PLATFORMIO_BUILD_FLAGS` and `platformio.ini` edits wipe `.pio/build`
- PlatformIO stores `.pio/build/project.checksum` (a hash of config incl. the
  `PLATFORMIO_BUILD_FLAGS` env var). When it changes, pio **deletes the entire
  `.pio/build/`** to force clean rebuilds — wiping *all* envs, not just the one you build.
- Symptom that bit me: built a display env with `PLATFORMIO_BUILD_FLAGS=-D...` to inject
  config, then built another env without it → the display's `firmware.bin` vanished and a
  stale `/tmp/*.bin` got flashed instead (the scp had silently failed; the flash used old
  files). Also turned every "incremental" rebuild into a slow full rebuild.
- **Rules:**
  - Don't toggle `PLATFORMIO_BUILD_FLAGS` between builds. Put per-variant config in a
    committed `[env:...]` (use `extends`); env defs coexist at a stable checksum.
  - To build multiple variants, pass them in ONE invocation: `pio run -e A -e B` — same
    checksum, no inter-env wipe.
  - After any flash-prep `scp`, verify it succeeded and check the remote file's timestamp
    before flashing (`ls -la`); a failed scp leaves stale bins that flash "successfully."

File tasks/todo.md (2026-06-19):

# TODO

## SoftAP captive-portal provisioning (replace BLE/NimBLE)

Replace BLE/Improv provisioning with SoftAP + captive portal on display + both
controllers, removing NimBLE entirely (the root cause of all the LCD/RAM crashes).
Build + ready; do NOT deploy to the live .57 controller.

### Design (confirmed with user)
- No saved WiFi creds OR sustained WiFi-connect failure → bring up SoftAP
  `Furnace-Setup-<mac4>` + DNSServer captive portal + web form (scan SSIDs, enter
  password) → save to NVS → reconnect. Hand-rolled on a dedicated WebServer + DNSServer
  (no WiFiManager dep). Open AP.
- Display: show "WiFi setup → join Furnace-Setup-XXXX" on the LCD.
- Waveshare controller: Ethernet-primary. If Ethernet gets an IP → skip WiFi/portal.
  If Ethernet fails → fall back to WiFi (saved creds → connect; none → SoftAP portal).
- Classic controller: WiFi primary → SoftAP fallback (like display).
- Remove NimBLE-Arduino + Improv lib_deps and IMPROV_WIFI_BLE_ENABLED.

### Step 0 — creds-seed fix (unblocks bench normal-config test) — IN PROGRESS
- [ ] Add default_ssid/default_password to WifiProvisioningConfig; begin() uses them as
      the NVS getString fallback so build-time/baked creds actually connect.
- [ ] Display init_network + controller pass g_cfg creds as defaults.
- [ ] Verify bench display (thermostat-bench-normal) connects to IoTDevices + the local
      test broker 10.0.2.175 (watch piserial5 /tmp/mqtt_log.txt), web UI responds.

### Step 1 — SoftAP portal module (shared) — DONE
- [x] softap_provisioning.h/.cpp: AP "Furnace-Setup-XXXX" + DNSServer captive portal +
      WebServer (async SSID scan, SSID+password form) → callback(ssid,password). Compiles.
- [x] WifiProvisioningManager: start_provisioning() → SoftAP; ensure_connected() services
      the portal; on_wifi_connected() stops it; reboot_pending()→false; IMPROV paths gone.

### Step 2 — boot logic
- [x] Display: run_provisioning_boot drives the SoftAP portal (LCD shows the AP name),
      reboots on cred submit. Normal boot unchanged (loop's g_wifi services the portal).
- [x] Classic controller: g_ctrl_wifi.start_provisioning() → SoftAP; loop's
      ctrl_ensure_wifi_connected services it.
- [ ] Waveshare Ethernet→WiFi runtime fallback (DEFERRED — separate state-machine change;
      currently Waveshare stays Ethernet-only, just with NimBLE gone). Follow-up.

### Step 3 — remove NimBLE + build/validate — IN PROGRESS
- [x] platformio.ini: dropped NimBLE-Arduino + Improv lib_deps + IMPROV_WIFI_BLE_ENABLED.
- [x] Deleted improv_ble_provisioning.*.
- [ ] Build all envs (running); confirm RAM headroom up (no NimBLE).
- [ ] Hardware: no crash; AP comes up. NOTE: full portal flow can't be tested remotely
      (needs someone to join the AP at the bench).

## Bench test infra (this session)
- Local test MQTT broker: mosquitto 2.1.2 on piserial5 (10.0.2.175:1883, anon, docker
  `bench-mqtt`). Logger: `docker exec bench-mqtt cat /tmp/mqtt_log.txt`.
- Bench WiFi creds: include/bench_wifi_secrets.h (gitignored) — IoTDevices + broker host.
- Display normal-config env: `thermostat-bench-normal` (force-includes the secrets header).

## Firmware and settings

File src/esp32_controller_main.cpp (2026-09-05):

#include <stdarg.h>
#include <stdint.h>
#include <string.h>
#include <stdio.h>
#include <errno.h>
#include <stdlib.h>
#include <math.h>

#include "controller/controller_relay_io.h"
#include "controller/controller_node.h"
#include "controller/network_recovery_policy.h"
#include "controller/pirateweather.h"
#include "controller/gpio_relay_backend.h"
#include "controller/pca9554_relay_backend.h"
#include "controller/controller_task_config.h"  // kCtrlMqttTaskCore (+ Core-0 static_assert)
#include "controller/pcf85063_rtc.h"
#include "controller/weather_watchdog.h"
#include "controller/panic_breadcrumb_hook.h"
#include "weather_icon.h"
#include "command_builder.h"
#include "espnow_cmd_word.h"
#include "management_paths.h"
#include "mqtt_payload.h"
#include "mqtt_topics.h"
#include "device_registry.h"
#include "discovery_topics.h"
#include "wifi_watchdog.h"

#if defined(ARDUINO)
#include <Arduino.h>
#include <atomic>
#include <ESPmDNS.h>
#include <HTTPClient.h>
#include <Preferences.h>
#include <WiFi.h>
#if defined(CONTROLLER_BOARD_WAVESHARE)
#include <ETH.h>
#endif
#include "wifi_provisioning_manager.h"
#include <WiFiClientSecure.h>
#include <PubSubClient.h>
#include <WebServer.h>
#include <esp_mac.h>
#include <esp_system.h>
#include <esp_task_wdt.h>
#include <time.h>
#include <sys/time.h>
#include <esp_sntp.h>
#include <esp_core_dump.h>
#include <esp_partition.h>
#include "ota_web_updater.h"
#include "controller/audit_log.h"
#include "web/web_ui_escape.h"
#include "web/web_ui_shell.h"
#include "web/web_ui_fields.h"
#include "mac_address_utils.h"

thermostat::ControllerNode *g_controller = nullptr;
#if defined(CONTROLLER_BOARD_WAVESHARE)
// Real production board: Waveshare ESP32-S3-ETH-8DI-8RO. Relays are driven through a
// PCA9554 I2C GPIO expander @0x20 (SDA=42/SCL=41), relay N = bit 1<<N, active-high.
// Defaults verified on hardware (2026-06-16): heat=relay0, cool=relay1, fan=relay2,
// spare=relay3 — see session log D1 (confirm furnace wiring before cutover).
thermostat::Pca9554RelayBackend g_relay_backend;       // defaults: 0x20, sda42/scl41, heat0/cool1/fan2/spare3
#elif defined(CONTROLLER_BOARD_S3)
// ESP32-S3 bench board (devkit/Feather) has no relay hardware (no PCA9554). GPIO
// 32/33/25 don't exist on the S3, so drive safe spare S3 GPIOs (nothing wired) to
// keep pinMode valid. The real Waveshare board uses Pca9554RelayBackend above.
thermostat::GpioRelayBackend g_relay_backend(
    thermostat::GpioRelayBackendConfig{4, 5, 6, 7});   // heat/cool/fan/spare, non-inverted
#else
thermostat::GpioRelayBackend g_relay_backend;          // classic ESP32: pins 32/33/25/26, non-inverted
#endif
thermostat::ControllerRelayIo g_relay_io(g_relay_backend);
thermostat::AuditLog g_audit_log;

#if defined(CONTROLLER_BOARD_WAVESHARE)
// Wired W5500 Ethernet is the PRIMARY IP link on the Waveshare board (pins validated
// on hardware — see the esp32s3-waveshare-port design / bring-up session log F6). The
// WiFi radio is used for ESP-NOW ONLY (STA mode, pinned channel, never associates) —
// see docs/superpowers/plans/2026-06-16-ethernet-primary-networking.md.
namespace {
constexpr int kEthCs = 16, kEthIrq = 12, kEthRst = -1;
constexpr int kEthSck = 15, kEthMiso = 14, kEthMosi = 13;
}  // namespace
bool g_ctrl_eth_started = false;
#endif

// IP-link abstraction. The controller's IP services (MQTT, web, OTA, mDNS) are
// link-agnostic (lwIP routes over whichever netif has the route); these two helpers
// are the only place that knows which physical link carries IP. On the Waveshare board
// that is Ethernet (WiFi never associates); on the classic board it is WiFi STA — where
// these reduce to exactly the prior WiFi.status()/WiFi.localIP() behavior (no change).
static bool ctrl_ip_link_up() {
#if defined(CONTROLLER_BOARD_WAVESHARE)
  return g_ctrl_eth_started && ETH.hasIP();  // hasIP() => link up AND has an address
#else
  return WiFi.status() == WL_CONNECTED;
#endif
}

// Forward declaration: ctrl_audit is defined far below but used by early probes
// (e.g. the SNTP-start dns0 probe and the network-ready helpers) above its definition.
void ctrl_audit(const char *fmt, ...);

// Network is usable for DNS-dependent traffic only once DHCP has assigned an IP
// AND populated a DNS server. WL_CONNECTED (link) can be true before either lands,
// which is exactly the window where MQTT/weather/SNTP-by-hostname fail to resolve.
// On Waveshare the IP path is Ethernet (ETH.dnsIP); on the classic board it is WiFi STA.
static bool ctrl_network_ready() {
#if defined(CONTROLLER_BOARD_WAVESHARE)
  return ctrl_ip_link_up()
      && ETH.localIP() != IPAddress(0, 0, 0, 0)
      && ETH.dnsIP(0) != IPAddress(0, 0, 0, 0);
#else
  return WiFi.status() == WL_CONNECTED
      && WiFi.localIP() != IPAddress(0, 0, 0, 0)
      && WiFi.dnsIP(0) != IPAddress(0, 0, 0, 0);
#endif
}

static String ctrl_ip_local_addr() {
#if defined(CONTROLLER_BOARD_WAVESHARE)
  return ctrl_ip_link_up() ? ETH.localIP().toString() : String("");
#else
  return (WiFi.status() == WL_CONNECTED) ? WiFi.localIP().toString() : String("");
#endif
}

// Wall-clock time (board-agnostic). SNTP over whatever IP link the board has — Ethernet
// on Waveshare, WiFi on the classic board — sets the system clock; once it has synced the
// controller broadcasts the time to displays over ESP-NOW so a WiFi-less display can show
// a clock. The Waveshare board ALSO has a PCF85063 RTC that seeds the clock at boot and
// persists NTP corrections (network-independent time); other boards rely on NTP alone.
bool g_ctrl_time_valid = false;           // system clock has trustworthy time (RTC or NTP)
const char *g_ctrl_time_source = "none";  // "rtc" | "ntp" | "none"
bool g_ctrl_rtc_present = false;          // a PCF85063 RTC was found at boot (Waveshare only)
// Persistent storage for the SNTP server name. MUST outlive SNTP and MUST NOT be
// reassigned or mutated after configTime() — SNTP (lwip) retains the .c_str() pointer,
// not a copy, so a realloc here would be a use-after-free in the lwip task.
String g_ctrl_ntp_primary;
volatile bool g_ctrl_ntp_synced = false;  // set by the SNTP sync callback (NOT just "clock set")

// SNTP notification callback — fires when SNTP actually receives a time update. This is
// what distinguishes a real NTP sync from the RTC seed (both set the system clock, so a
// "time > sane epoch" check alone cannot tell them apart).
static void ctrl_sntp_sync_cb(struct timeval *) { g_ctrl_ntp_synced = true; }

// The LAN gateway often serves NTP; read it from whichever interface is the IP path.
static String ctrl_ip_gateway() {
#if defined(CONTROLLER_BOARD_WAVESHARE)
  return ETH.gatewayIP().toString();
#else
  return WiFi.gatewayIP().toString();
#endif
}

#if defined(CONTROLLER_BOARD_WAVESHARE)
// PCF85063 RTC: seeds the system clock on boot and persists NTP corrections so the
// Waveshare board keeps trustworthy time across reboots/power loss without the network.
// The RTC stores UTC and shares the I2C bus with the relays (SDA=42/SCL=41), already
// brought up by the relay backend's begin().
thermostat::Pcf85063Rtc g_ctrl_rtc;       // default 0x51, sda42/scl41

// Read the RTC and, if its oscillator has been running (time trustworthy), seed the
// system clock. Called once at boot after the I2C bus is up.
static void ctrl_seed_time_from_rtc() {
  thermostat::RtcTime rt;
  bool osc_ok = false;
  if (!g_ctrl_rtc.read(rt, osc_ok)) {
    Serial.println("[time] RTC not responding on I2C");
    return;
  }
  g_ctrl_rtc_present = true;
  if (!osc_ok) {
    Serial.println("[time] RTC oscillator stopped (no trusted time) — waiting for NTP");
    return;
  }
  struct timeval tv = {};
  tv.tv_sec = static_cast<time_t>(thermostat::rtc_time_to_epoch(rt));
  settimeofday(&tv, nullptr);
  g_ctrl_time_valid = true;
  g_ctrl_time_source = "rtc";
  Serial.printf("[time] seeded from RTC: %04u-%02u-%02uT%02u:%02u:%02uZ\n",
                rt.year, rt.month, rt.day, rt.hour, rt.minute, rt.second);
}

// Write the current system time (UTC) back to the RTC. Called after an NTP sync.
static void ctrl_write_system_time_to_rtc() {
  if (!g_ctrl_rtc_present) return;
  const time_t nowt = time(nullptr);
  const thermostat::RtcTime rt =
      thermostat::rtc_time_from_epoch(static_cast<long long>(nowt));
  if (g_ctrl_rtc.set(rt)) {
    Serial.printf("[time] RTC updated from NTP: %04u-%02u-%02uT%02u:%02u:%02uZ\n",
                  rt.year, rt.month, rt.day, rt.hour, rt.minute, rt.second);
  } else {
    Serial.println("[time] RTC write FAILED");
  }
}

#endif  // CONTROLLER_BOARD_WAVESHARE

// Per-loop: start SNTP once the IP link is up; on a real NTP sync mark time valid (and,
// on Waveshare, write the corrected time back to the RTC, hourly, so it survives reboots).
static void ctrl_time_tick(uint32_t now_ms) {
  // Visibility: if the link is up (WL_CONNECTED / ETH link) but DNS never gets populated,
  // DNS-dependent services stay gated and the device looks "online but silent". Latch a
  // single audit line ~20s after link-up if network-ready still hasn't been reached, so a
  // diag run can distinguish "DNS arrives late" from "DNS never arrives".
  {
    static uint32_t link_up_since_ms = 0;
    static bool dns_wait_logged = false;
    if (ctrl_ip_link_up()) {
      if (link_up_since_ms == 0) link_up_since_ms = now_ms;
      if (!dns_wait_logged && !ctrl_network_ready() &&
          static_cast<uint32_t>(now_ms - link_up_since_ms) >= 20000) {
        dns_wait_logged = true;
#if defined(CONTROLLER_BOARD_WAVESHARE)
        ctrl_audit("[net] waiting for DNS: ip=%s dns0=%s (%lus)",
                   ETH.localIP().toString().c_str(), ETH.dnsIP(0).toString().c_str(),
                   static_cast<unsigned long>((now_ms - link_up_since_ms) / 1000));
#else
        ctrl_audit("[net] waiting for DNS: ip=%s dns0=%s (%lus)",
                   WiFi.localIP().toString().c_str(), WiFi.dnsIP(0).toString().c_str(),
                   static_cast<unsigned long>((now_ms - link_up_since_ms) / 1000));
#endif
      }
    } else {
      // Link dropped: reset so a re-association re-arms the one-shot DNS-wait probe.
      link_up_since_ms = 0;
      dns_wait_logged = false;
    }
  }

  static bool sntp_started = false;
  if (!sntp_started && ctrl_network_ready()) {
    // Probe: log dns0/ip at the instant SNTP fires. The gate is now ctrl_network_ready()
    // (IP + DNS populated), so dns0 must be non-zero here — if it ever isn't, the
    // network-ready check itself is wrong. Previously this gate was WL_CONNECTED, which
    // could fire before DHCP populated the lwIP DNS server (DNS-dependent services pre-DNS).
    ctrl_audit("[time] SNTP start: dns0=%s ip=%s",
               WiFi.dnsIP(0).toString().c_str(), WiFi.localIP().toString().c_str());
    g_ctrl_ntp_primary = ctrl_ip_gateway();  // LAN gateway often serves NTP
    sntp_set_time_sync_notification_cb(ctrl_sntp_sync_cb);
    configTime(0, 0, g_ctrl_ntp_primary.c_str(), "pool.ntp.org");  // UTC, no offset
    sntp_started = true;
    Serial.printf("[time] SNTP started (servers: %s, pool.ntp.org)\n",
                  g_ctrl_ntp_primary.c_str());
  }
  // Only act on a REAL NTP sync (callback-driven) — not merely "clock is set", which is
  // already true from the RTC seed on Waveshare.
  if (g_ctrl_ntp_synced) {
    g_ctrl_time_valid = true;
    g_ctrl_time_source = "ntp";
#if defined(CONTROLLER_BOARD_WAVESHARE)
    static bool rtc_synced = false;
    static uint32_t last_rtc_write_ms = 0;
    if (!rtc_synced ||
        static_cast<uint32_t>(now_ms - last_rtc_write_ms) >= 3600000UL) {  // hourly
      ctrl_write_system_time_to_rtc();
      rtc_synced = true;
      last_rtc_write_ms = now_ms;
    }
#else
    (void)now_ms;
#endif
  }
}
WiFiClient g_ctrl_wifi_client;
PubSubClient g_ctrl_mqtt(g_ctrl_wifi_client);
WebServer g_ctrl_web(80);
uint32_t g_ctrl_last_mqtt_publish_ms = 0;
bool g_ctrl_last_lockout = false;
bool g_ctrl_have_lockout = false;
uint32_t g_ctrl_last_mqtt_command_ms = 0;
bool g_cfg_ctrl_allow_ha = true;       // NVS "allow_ha"
bool g_cfg_ctrl_mqtt_enabled = true;   // NVS "mqtt_en"
bool g_cfg_ctrl_espnow_enabled = true; // NVS "espnow_en"
String g_ctrl_last_mqtt_error = "none";
String g_ctrl_last_ota_error = "none";
String g_ctrl_last_espnow_error = "none";
uint16_t g_ctrl_mqtt_seq = 0;
std::atomic<bool> g_ctrl_mqtt_discovery_sent{false};
// NetworkRecoveryPolicy for MQTT reconnect backoff + subsystem restart.
// reboot_enabled=false: the isolation watchdog owns device reboots.
thermostat::NetworkRecoveryPolicy g_ctrl_mqtt_recovery(
    thermostat::NetworkRecoveryConfig{1000, 60000, 5, 0, false});
bool g_ctrl_have_shadow = false;
FurnaceMode g_ctrl_shadow_mode = FurnaceMode::Off;
FanMode g_ctrl_shadow_fan = FanMode::Automatic;
float g_ctrl_shadow_setpoint_c = 20.0f;
// Track last-persisted values to skip NVS writes when nothing changed
FurnaceMode g_ctrl_persisted_mode = FurnaceMode::Off;
FanMode g_ctrl_persisted_fan = FanMode::Automatic;
float g_ctrl_persisted_heat_sp_c = -999.0f;  // sentinel: force write on first call
float g_ctrl_persisted_cool_sp_c = -999.0f;
bool g_ctrl_web_started = false;
DeviceRegistry g_device_registry;
bool g_ctrl_mdns_started = false;
uint32_t g_ctrl_boot_count = 0;
String g_ctrl_reset_reason = "unknown";
// Cause of the firmware-initiated reboot that immediately preceded this boot,
// recovered from NVS at startup. "none" means the last reset was not one of the
// instrumented esp_restart() paths (power-on, panic, brownout, OTA, etc.).
String g_ctrl_reboot_reason = "none";
bool g_ctrl_reboot_requested = false;
uint32_t g_ctrl_reboot_at_ms = 0;
uint32_t g_ctrl_isolation_start_ms = 0;  // 0 = not isolated
bool g_ctrl_isolation_recovery_done = false;  // in-place subsystem recovery already tried this episode

// Inbound MQTT command queue. The PubSubClient callback (which runs on the MQTT task once
// MQTT is moved off the control loop) only PARSES + enqueues; the control loop drains and
// applies, keeping all controller-state mutation single-threaded with g_controller->tick().
struct CtrlInboundMsg {
  char topic[160];
  uint8_t payload[256];
  uint16_t len;
};
QueueHandle_t g_ctrl_inbound_q = nullptr;
std::atomic<uint32_t> g_ctrl_inbound_dropped{0};  // queue-full drops (surfaced in state/inbound_dropped)
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
void loop() {
  // During OTA upload, suspend non-essential work to free CPU and
  // network bandwidth for the flash write.
  if (ota_web_in_progress()) {
    // Disconnect MQTT to free TCP socket buffers for OTA upload. The prepare callback
    // already does this under the mutex; this is a belt-and-suspenders catch, also under
    // the mutex so it can't race the (now-skipping) MQTT task.
    if (g_ctrl_mqtt_up.load() && g_ctrl_mqtt_mtx != nullptr &&
        xSemaphoreTake(g_ctrl_mqtt_mtx, portMAX_DELAY) == pdTRUE) {
      if (g_ctrl_mqtt.connected()) {
        g_ctrl_mqtt.disconnect();
        g_ctrl_mqtt_up.store(false);
        Serial.printf("[ota] disconnected MQTT to free heap: %u bytes free\n",
                      ESP.getFreeHeap());
      }
      xSemaphoreGive(g_ctrl_mqtt_mtx);
    }
    ota_web_process_flash_ops();
    delay(1);
    return;
  }

  static uint32_t last_heartbeat = 0;
  const uint32_t now = millis();
  if (now - last_heartbeat >= 5000) {
    last_heartbeat = now;
    Serial.printf("[%lu] controller alive, ip=%s, mqtt=%s, prov=%s\n",
                  now,
                  ctrl_ip_link_up() ? ctrl_ip_local_addr().c_str() : "no",
                  g_ctrl_mqtt_up.load() ? "yes" : "no",
                  g_ctrl_wifi.provisioning_active() ? "active" : "idle");
    if (g_controller != nullptr) {
      const auto &t = g_controller->transport();
      const uint8_t *m = t.last_rx_mac();
      Serial.printf(
          "[espnow] rx=%lu tx_ok=%lu tx_fail=%lu last_rx=%02X:%02X:%02X:%02X:%02X:%02X\n",
          (unsigned long)t.rx_count(), (unsigned long)t.send_ok_count(),
          (unsigned long)t.send_fail_count(), m[0], m[1], m[2], m[3], m[4], m[5]);
    }
  }
  if (g_ctrl_reboot_requested && static_cast<uint32_t>(now - g_ctrl_reboot_at_ms) < 0x80000000u) {
    ESP.restart();
  }
  if (g_controller != nullptr) {
    g_controller->tick(now);
    // Periodically rebroadcast the latest telemetry so a display that joined or
    // rebooted after the last state change still learns the current state (telemetry
    // is otherwise change-driven). ~15s keeps displays within their 30s timeout.
    static uint32_t last_telemetry_republish_ms = 0;
    if (static_cast<uint32_t>(now - last_telemetry_republish_ms) >= 15000) {
      last_telemetry_republish_ms = now;
      g_controller->app().republish_telemetry();
    }
    // Broadcast wall-clock time (when ours is trustworthy, via RTC or NTP) so a WiFi-less
    // display can show a clock without its own NTP/RTC. Works on any board that has a
    // valid clock: Waveshare via RTC+SNTP over Ethernet, classic via SNTP over WiFi.
    static uint32_t last_time_broadcast_ms = 0;
    if (g_ctrl_time_valid &&
        static_cast<uint32_t>(now - last_time_broadcast_ms) >= 30000) {
      last_time_broadcast_ms = now;
      g_controller->transport().publish_time(static_cast<uint32_t>(time(nullptr)));
    }
    const ThermostatSnapshot snap = g_controller->app().runtime().snapshot();
    g_relay_io.apply(now, snap.relay, snap.failsafe_active || snap.hvac_lockout);
#if !defined(CONTROLLER_BOARD_WAVESHARE)
    // Classic board: WiFi STA is the IP link, so keep it connected and let the WiFi
    // watchdog reboot on sustained WiFi loss. On Waveshare, WiFi never associates
    // (ESP-NOW only) and Ethernet/lwIP self-recovers — the isolation watchdog below is
    // the SOLE reboot authority (no IP-link-down reboot). See ethernet-primary plan.
    // NOTE: this gate is what keeps the WiFi radio from ever associating on Waveshare.
    // A stray `wifi_ssid` write only persists creds + sets reconnect_required (see
    // WifiProvisioningManager::set_credentials); association happens ONLY in
    // ensure_connected(), which is gated out here — so ESP-NOW channel pinning is safe.
    ctrl_ensure_wifi_connected(now);
    wifi_watchdog_tick(now, g_ctrl_mqtt_up.load());
#endif
    ctrl_ensure_mdns_ready();
    ctrl_ensure_web_ready();
    // ---- MQTT connect + receive runs on the dedicated ctrl_mqtt task (ctrl_mqtt_task).
    //      The control loop only drains inbound commands + publishes, under a TRY-lock so a
    //      slow connect on the MQTT task can NEVER block relay control. If the lock is held
    //      (MQTT task mid-connect), we just skip this cycle; commands stay queued. ----
    if (xSemaphoreTake(g_ctrl_mqtt_mtx, 0) == pdTRUE) {
      if (g_ctrl_inbound_q != nullptr) {
        CtrlInboundMsg in;
        while (xQueueReceive(g_ctrl_inbound_q, &in, 0) == pdTRUE) {
          ctrl_handle_mqtt_message(in.topic, in.payload, in.len);
        }
      }
      if (g_ctrl_just_connected.exchange(false)) {
        ctrl_publish_on_connect();
      }
      if (g_ctrl_mqtt_up.load()) {
        if (!g_ctrl_have_lockout || g_ctrl_last_lockout != snap.hvac_lockout ||
            (now - g_ctrl_last_mqtt_publish_ms) >= kCtrlMqttPublishMs) {
          g_ctrl_last_mqtt_publish_ms = now;
          ctrl_publish_runtime_state();
        }
        // Periodically clean up stale peer device discovery topics.
        static uint32_t last_stale_check_ms = 0;
        if (static_cast<uint32_t>(now - last_stale_check_ms) >= kStaleCheckIntervalMs) {
          last_stale_check_ms = now;
          ctrl_check_stale_devices(now);
        }
      }
      xSemaphoreGive(g_ctrl_mqtt_mtx);
    }
    ctrl_time_tick(now);  // start SNTP once IP up; mark time valid; (Waveshare: RTC write-back)
    const bool mqtt_primary_active =
        g_ctrl_mqtt_up.load() &&
        (static_cast<uint32_t>(now - g_ctrl_last_mqtt_command_ms) < kCtrlMqttPrimaryHoldMs);
    g_controller->set_espnow_command_enabled(!mqtt_primary_active);
    ctrl_poll_weather(now);

    // Isolation reboot: if both MQTT and ESP-NOW have been down continuously
    // for kCtrlIsolationRebootMs, the network stack is likely wedged. The WiFi
    // watchdog handles outright WiFi loss; this catches the case where WiFi
    // appears up (ping passes) but TCP/MQTT is stuck and the display is also
    // unreachable.
    {
      const uint32_t hb_ms = g_controller->app().runtime().heartbeat_last_seen_ms();
      const bool espnow_active = (hb_ms > 0) &&
          (static_cast<uint32_t>(now - hb_ms) < kCtrlIsolationRebootMs);
      // Don't count MQTT as "down" (and don't start the isolation/reboot clock) until the
      // network has actually become usable for DNS at least once. While WL_CONNECTED is
      // true but DNS is not yet populated, MQTT legitimately cannot connect; treating that
      // as isolation would reboot-loop the device during a normal (if slow) DHCP/DNS bring-up.
      static bool s_network_was_ready = false;
      if (ctrl_network_ready()) s_network_was_ready = true;
      const bool isolated =
          s_network_was_ready && !g_ctrl_mqtt_up.load() && !espnow_active;
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

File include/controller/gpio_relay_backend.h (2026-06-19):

#pragma once

#include "controller/relay_backend.h"
#include "thermostat_types.h"

namespace thermostat {

struct GpioRelayBackendConfig {
  int heat_pin = 32;
  int cool_pin = 33;
  int fan_pin = 25;
  int spare_pin = 26;
  bool inverted = false;
};

// Pure, testable: the digital level to drive for a given relay demand + polarity.
inline bool gpio_relay_level(bool demand_on, bool inverted) {
  return inverted ? !demand_on : demand_on;
}

class GpioRelayBackend : public RelayBackend {
 public:
  explicit GpioRelayBackend(const GpioRelayBackendConfig &config = GpioRelayBackendConfig())
      : config_(config) {}

  void begin() override;
  void write(const RelayDemand &out) override;

 private:
  GpioRelayBackendConfig config_{};
};

}  // namespace thermostat

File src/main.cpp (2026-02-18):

#include <stdint.h>

#include "controller/controller_app.h"
#include "espnow_cmd_word.h"

namespace {

class DemoTransport final : public thermostat::IControllerTransport {
 public:
  void publish_telemetry(const thermostat::ControllerTelemetry &telemetry) override {
    last = telemetry;
    ++publish_count;
  }

  thermostat::ControllerTelemetry last{};
  uint32_t publish_count = 0;
};

}  // namespace

int run_smoke_checks() {
  DemoTransport transport;

  thermostat::ControllerConfig cfg;
  cfg.failsafe_timeout_ms = 5000;
  cfg.fan_circulate_period_min = 5;
  cfg.fan_circulate_duration_min = 2;

  thermostat::ControllerApp app(transport, cfg);

  CommandWord first;
  first.mode = FurnaceMode::Cool;
  first.fan = FanMode::Automatic;
  first.setpoint_decic = 230;
  first.seq = 10;

  const auto first_result = app.on_command_word(espnow_cmd::encode(first));
  if (!first_result.accepted) {
    return 1;
  }

  const auto duplicate_result = app.on_command_word(espnow_cmd::encode(first));
  if (!duplicate_result.stale_or_duplicate) {
    return 2;
  }

  app.on_indoor_temperature_c(25.0f);
  app.on_heartbeat(1000);
  app.tick(2000);
  if (!app.runtime().cool_demand() || app.runtime().heat_demand() ||
      app.runtime().fan_demand()) {
    return 3;
  }

  app.tick(8000);
  if (!app.runtime().failsafe_active() || app.runtime().cool_demand() ||
      app.runtime().heat_demand() || app.runtime().fan_demand()) {
    return 4;
  }

  app.on_heartbeat(9000);
  app.tick(9001);

  CommandWord second;
  second.mode = FurnaceMode::Off;
  second.fan = FanMode::AlwaysOn;
  second.setpoint_decic = 210;
  second.seq = 11;
  const auto second_result = app.on_command_word(espnow_cmd::encode(second));
  if (!second_result.accepted) {
    return 5;
  }

  app.tick(9100);
  if (!app.runtime().fan_demand()) {
    return 6;
  }

  if (transport.publish_count == 0) {
    return 7;
  }

  return 0;
}

int main() { return run_smoke_checks(); }

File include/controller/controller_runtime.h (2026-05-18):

#pragma once

#include <stdint.h>

#include "espnow_cmd_word.h"
#include "thermostat_types.h"

namespace thermostat {

struct ControllerConfig {
  uint32_t failsafe_timeout_ms = 300000;
  uint16_t fan_circulate_period_min = 60;
  uint16_t fan_circulate_duration_min = 10;
  uint32_t min_cooling_off_time_ms = 300000;
  uint32_t min_cooling_run_time_ms = 300000;
  uint32_t min_heating_off_time_ms = 180000;
  uint32_t min_heating_run_time_ms = 180000;
  uint32_t min_idle_time_ms = 30000;
  uint32_t max_heating_run_time_ms = 14400000;  // 4 hours
  uint32_t max_cooling_run_time_ms = 10800000;  // 3 hours
  float heat_deadband_c = 0.5f;
  float heat_overrun_c = 0.5f;
  float cool_deadband_c = 0.5f;
  float cool_overrun_c = 0.5f;
  float indoor_temp_fallback_c = 20.0f;
  float indoor_humidity_fallback_pct = 50.0f;
};

struct ControllerTickInput {
  uint32_t now_ms = 0;
  bool heat_call = false;
  bool cool_call = false;
  bool has_indoor_temp = false;
};

struct CommandApplyResult {
  bool accepted = false;
  bool stale_or_duplicate = false;
  bool sync_requested = false;
  bool filter_reset_requested = false;
};

class ControllerRuntime {
 public:
  using AuditCallback = void (*)(const char *msg);

  explicit ControllerRuntime(const ControllerConfig &config = ControllerConfig());

  void set_audit_callback(AuditCallback cb) { audit_cb_ = cb; }

  void note_heartbeat(uint32_t now_ms);
  void set_hvac_lockout(bool locked_out);
  void set_windows_open(bool open);
  void reset_remote_command_sequence();

  CommandApplyResult apply_remote_command(const CommandWord &cmd,
                                          const uint8_t *source_mac = nullptr);

  void tick(const ControllerTickInput &in);

  FurnaceMode mode() const { return mode_; }
  FanMode fan_mode() const { return fan_mode_; }
  float target_temperature_c() const;

  // Per-mode setpoints. Heat default 20.0°C, cool default 24.0°C.
  float heat_setpoint_c() const { return heat_setpoint_c_; }
  float cool_setpoint_c() const { return cool_setpoint_c_; }
  void set_heat_setpoint_c(float v) { heat_setpoint_c_ = v; }
  void set_cool_setpoint_c(float v) { cool_setpoint_c_ = v; }

  bool failsafe_active() const { return failsafe_active_; }
  bool hvac_lockout() const { return hvac_lockout_; }
  bool windows_open() const { return windows_open_; }
  bool max_runtime_exceeded() const { return max_runtime_exceeded_; }

  bool heat_demand() const { return relay_.heat; }
  bool cool_demand() const { return relay_.cool; }
  bool fan_demand() const { return relay_.fan; }
  uint32_t heartbeat_last_seen_ms() const { return heartbeat_last_seen_ms_; }

  uint32_t filter_runtime_seconds() const { return filter_runtime_seconds_; }
  void set_filter_runtime_seconds(uint32_t v) { filter_runtime_seconds_ = v; }
  float filter_runtime_hours() const {
    return static_cast<float>(filter_runtime_seconds_) / 3600.0f;
  }

  void set_fan_circulate_period_min(uint16_t v) { config_.fan_circulate_period_min = v; }
  void set_fan_circulate_duration_min(uint16_t v) { config_.fan_circulate_duration_min = v; }

  FurnaceStateCode furnace_state() const;
  ThermostatSnapshot snapshot() const;

  enum class HvacState : uint8_t {
    Idle = 0,
    Heating = 1,
    Cooling = 2,
  };

 private:
  void enforce_safety_interlocks(uint32_t now_ms);
  void update_failsafe(uint32_t now_ms, bool has_indoor_temp);
  void apply_hvac_calls(uint32_t now_ms, bool heat_call, bool cool_call);
  bool elapsed_at_least(uint32_t now_ms, uint32_t start_ms, uint32_t duration_ms) const;
  void enter_idle(uint32_t now_ms);
  void enter_heating(uint32_t now_ms);
  void enter_cooling(uint32_t now_ms);
  void run_minute_tasks(uint32_t now_ms);

  ControllerConfig config_;

  FurnaceMode mode_ = FurnaceMode::Off;
  FanMode fan_mode_ = FanMode::Automatic;
  float heat_setpoint_c_ = 20.0f;
  float cool_setpoint_c_ = 24.0f;

  bool hvac_lockout_ = false;
  bool failsafe_active_ = false;
  bool windows_open_ = false;
  bool max_runtime_exceeded_ = false;
  bool spare_relay_4_ = false;

  RelayDemand relay_{};

  uint32_t heartbeat_last_seen_ms_ = 0;
  uint32_t filter_runtime_seconds_ = 0;
  uint32_t hvac_state_since_ms_ = 0;
  uint32_t last_heating_off_ms_ = 0;
  uint32_t last_cooling_off_ms_ = 0;
  bool has_heating_off_timestamp_ = false;
  bool has_cooling_off_timestamp_ = false;
  HvacState hvac_state_ = HvacState::Idle;
  bool equipment_delay_ = false;

  int fan_circulate_elapsed_min_ = 0;
  uint32_t last_minute_tick_ms_ = 0;
  AuditCallback audit_cb_ = nullptr;

  void audit(const char *fmt, ...) const;

  static constexpr int kMaxCommandSources = 10;
  struct CommandSource {
    uint8_t mac[6] = {};
    uint16_t last_seq = 0;
    bool active = false;
  };
  CommandSource command_sources_[kMaxCommandSources] = {};
  uint16_t last_seq_default_ = 0;  // used when no source MAC provided
};

}  // namespace thermostat

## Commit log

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2026-02-23 Add web-based OTA upload and automatic firmware rollback
    Add a shared ota_web_updater module that provides a /update web page
    for browser-based firmware uploads and automatic rollback using the
    ESP-IDF bootloader. New firmware must establish WiFi + MQTT within
    3 minutes or the device reverts to the previous version.
    [esp32_controller_main.cpp, esp32s3_thermostat_firmware.cpp, ota_web_updater.cpp]
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2026-02-24 Add filter change indicator, hide setpoint when off, and HA binary sensor (#3)
    * Add filter change indicator, hide setpoint when off, and HA binary sensor
    - Show "Change Filter" on home screen when filter runtime >= 720 hours
    - Hide setpoint column in sim when mode is Off (matching firmware behavior)
    - Add Home Assistant binary_sensor for filter_change_required (device class: problem)
    - Publish state/filter_change_required in both firmware and sim controller
    * refactor: extract filter change threshold into named constant (#4)
    * Fix weather font size and replace placeholder values with dashes
    - Change weather label from font40 to fo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
    [controller_app.h, controller_runtime.h, esp32_controller_main.cpp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]
2026-02-24 Architecture review: filter runtime persistence, NaN guard, HTML injection, MQTT input clamping (#5)
    * Initial plan
    * Fix filter runtime persistence, NaN/Inf guard, HTML injection, and MQTT input clamping
    * Add HTML escape and MQTT input validation to thermostat web UI
    Apply the same security fixes from the controller side to the thermostat
    firmware: HTML-escape all config values in web_handle_root() to prevent
    stored XSS, and add isfinite() guards with range clamping on MQTT
    setpoint (0-40C) and temp compensation (-10 to +10C) inputs.
    * Address review feedback: clam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
    [controller_app.h, controller_runtime.h, esp32_controller_main.cpp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]
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2026-02-28 Add maximum HVAC runtime safety limit
    Prevent heating/cooling from running indefinitely when setpoint is
    unreachable. Configurable max runtime (default 4h heat, 3h cool,
    0 = disabled) forces idle and publishes state via MQTT for HA alerting.
    Existing min off-time enforcement applies naturally after cutoff.
    [controller_runtime.h, esp32_controller_main.cpp]
2026-02-28 Split controller and display into separate HA devices
    Derive per-device IDs from the shared base: controller appends
    "_controller", display appends "_display". Each device gets its own
    name ("Furnace Controller" / "Thermostat Display") and device ID in
    HA discovery payloads, enabling independent availability tracking.
    Also fixes ::json_extract_string scope resolution in thermostat
    firmware where the local String-based overload shadowed the char*
    version from device_registry.h.
    [esp32_controller_main.cpp, esp32s3_thermostat_firmware.cpp]
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2026-02-28 Add MAC-based unique suffixes to device IDs and mDNS names
    Append the last 6 hex chars of each device's WiFi MAC address to the
    default shared_device_id, mqtt_client_id, and ota_hostname. This prevents
    entity collisions in Home Assistant and mDNS name conflicts when multiple
    thermostat systems share the same MQTT broker. Saved user preferences
    still take priority. Includes one-time migration to clear old non-suffixed
    defaults from NVS.
    [esp32_controller_main.cpp, esp32s3_thermostat_firmware.cpp]
2026-03-01 Address PR review: harden mac_suffix, JSON-escape /devices, guard upsert
    - mac_suffix(): strip colons and validate length instead of fixed offsets,
    fall back to "000000" if MAC is unavailable or too short
    - /devices endpoint: JSON-escape registry fields to prevent injection
    - Device registry upsert: initialize buffers and only call upsert when
    all required fields are successfully extracted
    - json_extract_string(): initialize out[0]='\0' before any early return
    - Remove unused kDevId test constant
    [esp32_controller_main.cpp, esp32s3_thermostat_firmware.cpp]
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2026-03-01 Fix mac_suffix() to use esp_efuse_mac_get_default instead of WiFi API
    WiFi.macAddress() returns 00:00:00:00:00:00 before WiFi.mode() is set,
    causing all devices to get the "000000" fallback suffix. Switch to
    esp_efuse_mac_get_default() which reads the base MAC from eFuse and
    works at any point during boot. Also migrate the broken _000000 suffixed
    values saved during the first bad boot.
    [esp32_controller_main.cpp, esp32s3_thermostat_firmware.cpp]
2026-03-01 Fix device discovery, rename shared_device_id, remove General tab
    Device registry now uses compile-time THERMOSTAT_DEVICE_DISCOVERY_PREFIX
    so all devices share the same discovery namespace regardless of their
    MAC-suffixed unique_device_id. Rename shared_device_id to unique_device_id
    throughout (NVS key unchanged). Add configurable discovery_prefix to
    controller (was hardcoded "homeassistant"). Move discovery_prefix field
    to MQTT tab and remove the now-empty General tab from both firmwares.
    [esp32_controller_main.cpp, esp32s3_thermostat_firmware.cpp]
2026-03-01 Fix temp compensation change not updating display until next sensor poll
    Reset g_last_sensor_poll_ms when temp_comp_c is changed via web UI or
    MQTT so the sensor is re-read immediately with the new compensation
    instead of waiting up to 60 seconds.
    [esp32s3_thermostat_firmware.cpp]
2026-03-01 Add WiFi connectivity watchdog to detect zombie WiFi state
    WiFi.isConnected() can return true with a valid IP while the device is
    actually unreachable on the network. This went undetected for 13+ hours
    requiring a physical reset.
    Adds a gateway-ping watchdog using the ESP-IDF esp_ping API:
    - Pings WiFi.gatewayIP() every 30s via single ICMP echo
    - After 2min of consecutive failures: force WiFi disconnect/reconnect
    - After 5min or 3 failed reconnects: ESP.restart()
    - Stale ping detection (15s) handles hung ping tasks
    - Detailed serial logging for post-mortem diagnostics
    [esp32_controller_main.cpp, esp32s3_thermostat_firmware.cpp, wifi_watchdog.h]
2026-03-03 Refactor device list, transport toggles, and WiFi watchdog improvements
    - Replace split espnow_peer_mac/espnow_peer_macs/primary_sensor_mac config
    with unified devices list (semicolon-separated MAC[=role] entries) on
    the controller; includes migration from old NVS keys on first boot
    - Add allow_ha flag to controller (replaces runtime-only espnow_only)
    - Add mqtt_enabled and espnow_enabled transport toggles to both devices
    - Merge controller ESP-NOW tab into Hardware tab; add Devices card with
    per-entry Add/Remove UI and Transport card with toggle checkboxes
    - Add checkbox_field() helper and submitWithCheckboxes() JS to web UI
    - Improve WiFi watchdog: add connectivity_proven parameter s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
    [esp32_controller_main.cpp, esp32s3_thermostat_firmware.cpp, wifi_watchdog.h]
2026-03-03 Move controller weather fetching to async FreeRTOS task, remove display self-poll
    Controller: replace synchronous HTTPS calls in loop() with a background task
    pinned to Core 0. The task geocodes the ZIP (cached until ZIP/key changes),
    fetches the forecast, and signals the main loop via a volatile ready flag.
    The main loop's ctrl_poll_weather() is now non-blocking — it just applies
    pending results. Config changes for API key or ZIP wake the task immediately
    via xTaskNotifyGive. Eliminates up to 16s stalls in MQTT loop, OTA handler,
    and web server every 15 minutes.
    Display: remove the 30-minute self-poll fallback path entirely. The display
    is now a passive consumer of weather data pushed by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
    [esp32_controller_main.cpp, esp32s3_thermostat_firmware.cpp]
2026-03-03 Fix 6 bugs identified in Copilot review
    1. mqtt_payload.h: add str_to_furnace_state() and use it in display MQTT
    handler instead of atoi(). Controller now publishes furnace_state as a
    human-readable string ("Heating", "Idle" etc.) — atoi() always returned 0.
    2. wifi_watchdog.h: replace volatile bool ping_in_flight/ping_got_reply with
    std::atomic<bool>. volatile prevents register caching but does not provide
    the CPU memory barriers needed for cross-core visibility on dual-core ESP32.
    3. wifi_watchdog.h: fix stale ping silently dropped. cleanup_session() sets
    ping_handle=nullptr, so the subsequent `if (ping_handle)` check was always
    false after a stale timeout — handle_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
    [esp32s3_thermostat_firmware.cpp, wifi_watchdog.h]
2026-03-03 Fix PR #9 Copilot review: thread safety for weather task
    - Protect g_ctrl_weather_coords_valid reads/writes in config change
    handlers under g_ctrl_weather_mutex (was unguarded)
    - Snapshot coords under mutex in web handler to avoid torn reads
    - Create g_ctrl_weather_mutex before task start; check
    xTaskCreatePinnedToCore return value and log on failure
    - poll_weather: only record last_controller_weather_ms when it is 0
    (i.e. on first packet) instead of overwriting every tick
    [esp32_controller_main.cpp, esp32s3_thermostat_firmware.cpp]
2026-03-03 Improve controller reliability: TLS heap reduction + isolation reboot
    TLS heap reduction (platformio.ini):
    - Enable MBEDTLS_SSL_VARIABLE_BUFFER_LENGTH: TX/RX buffers allocated only
    during active TLS record I/O and freed immediately after, reducing
    steady-state heap per HTTPS connection from ~40KB to ~0KB
    - Enable MBEDTLS_ASYMMETRIC_CONTENT_LEN: TX buffer shrunk to 4KB (our
    HTTP GETs are tiny); RX kept at 16KB for full-size server responses
    - Strip unused managed components from controller env to avoid build
    failures when IDF rebuilds with the new config (mirrors thermostat env)
    Isolation reboot (esp32_controller_main.cpp):
    - Reboot if both MQTT and ESP-NOW heartbeat have been silent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
    [esp32_controller_main.cpp]
2026-03-03 Fix 5 controller reliability issues from code audit
    - Payload buffer 127→255 bytes: MQTT messages (API keys, hostnames,
    config values) were silently truncated at 127 chars
    - ESP-NOW channel: clamp NVS-loaded value to 1-14; a corrupted value
    would silently break all ESP-NOW communication
    - MQTT reconfigure: reset retry timer to 0 on disconnect so reconnection
    happens immediately rather than waiting up to 5 more seconds
    - Subscribe failures: check all subscribe() return values; disconnect
    and retry immediately if any fail (previously device would appear
    connected but receive no commands)
    - Weather mutex: only create the weather task if mutex allocation
    succeeds; previously a NULL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
    [esp32_controller_main.cpp]
2026-03-03 Add watchdog to detect and restart wedged weather task
    The WiFiClientSecure SSL handshake can ignore http.setTimeout() and
    block indefinitely in some ESP32 Arduino versions. Because the blocked
    socket call yields to the FreeRTOS scheduler, the CPU0 idle task still
    runs and the task watchdog never fires — the weather task just stalls
    forever with no recovery.
    Fix: the task updates g_ctrl_weather_task_heartbeat_ms at the top of
    each outer loop iteration. ctrl_poll_weather() checks the heartbeat age
    on every call; if it exceeds two poll periods + both HTTP timeouts
    (~30m 16s), the task is considered wedged: it is killed via vTaskDelete,
    the mutex is released in case the task died holding it,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
    [esp32_controller_main.cpp]
2026-03-03 Fix 10 display firmware reliability issues from code audit
    Critical fixes:
    - Fix 1: Move frame buffer init inside panel success block to prevent
    crash when esp_lcd_new_rgb_panel() fails (g_panel stays nullptr)
    - Fix 2: Guard rgb_flush_cb() on both g_panel and g_flush_ready_sem
    being non-null before touching semaphore
    - Fix 3: Add g_sensors_initialized flag; poll_touch() guards on it
    to prevent I2C access before init_sensors() completes
    - Fix 4: Add g_ui_ready flag set at end of create_ui(); refresh_ui()
    checks it instead of g_status_label; add null guards for the 3
    previously unguarded home-page labels
    - Fix 5: Change g_wifi_provisioning_started from bool to
    std::atomic<bool> for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
    [esp32s3_thermostat_firmware.cpp]
2026-03-03 Address Copilot PR review: 3 controller reliability fixes
    - Fix heartbeat not updating in weather task inner retry loop: the
    watchdog would incorrectly fire after 30m when WiFi or config isn't
    ready yet, since the heartbeat was only stamped at outer loop entry.
    Now stamped at the top of each inner retry iteration too.
    - Replace vTaskDelete + xSemaphoreGive with esp_restart() in weather
    task watchdog: forcibly deleting the task leaks C++ stack objects
    (HTTPClient, WiFiClientSecure) since destructors don't run; giving
    a mutex from a non-owner task is also incorrect FreeRTOS usage.
    Rebooting is the only safe recovery from a hung TLS call.
    - Remove g_ctrl_last_mqtt_attempt_ms = 0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
    [esp32_controller_main.cpp]
2026-03-04 Move web server to dedicated FreeRTOS task on Core 0
    WebServer::handleClient() blocked the Arduino main loop for the full
    duration of every HTTP request. For OTA uploads (~8s) and screenshot
    streaming (~8s), this starved LVGL ticks, sensor reads, and MQTT
    processing — causing Task Watchdog resets.
    - Add web_server_task pinned to Core 0 (8KB stack, priority 1)
    - Protect shared state with g_api_mutex across all web handlers,
    mqtt_on_message, and main-loop critical sections (runtime tick,
    controller state, sensor poll, MQTT publish)
    - Web read handlers snapshot globals under brief mutex, then build
    and send responses without holding the lock
    - Screenshot handler copies framebuffer to P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
    [esp32s3_thermostat_firmware.cpp]
2026-03-04 Fix merge: remove peer_mac/peer_macs NVS loads not in this branch
    The devices-based approach in this PR replaces the separate
    peer_mac/peer_macs globals. Keep the channel validation from main.
    [esp32_controller_main.cpp]
2026-03-04 Merge main, fix WiFi hang, PSRAM web task stack, wifi watchdog guard
    Merge main branch (wifi watchdog, async weather, temp compensation,
    NVS write macros, espnow channel validation) into web-freertos-task.
    Fix web task starving WiFi driver by allocating its 8KB stack from
    PSRAM instead of Core 0 internal SRAM, which the WiFi driver needs
    for connection buffers.
    Fix wifi watchdog crash (lwIP assert in udp_new_ip_type) by skipping
    gateway pings until WiFi has connected at least once.
    Fix OTA WDT timeout by reconfiguring TWDT to 120s during flash writes.
    Fix mutex leak in mqtt_on_message cmd/temp_comp_c handler (bare return
    without releasing g_api_mutex).
    Set explicit default_16MB.csv part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
    [esp32_controller_main.cpp, esp32s3_thermostat_firmware.cpp, ota_web_updater.cpp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]
2026-03-04 Lazy-load screenshot, add default_16MB.csv partition table
    Defer /screenshot fetch until the System tab is activated, avoiding
    an ~8s blocking BMP stream on every page load.
    Copy default_16MB.csv into the project so the thermostat build finds
    its partition table without depending on framework install paths.
    [default_16MB.csv]
2026-03-04 Fix PR review: atomics, thread safety, data races, subscriptions
    - Change g_mqtt_state_dirty and g_web_started from volatile bool to
    std::atomic<bool> for proper cross-core memory ordering.
    - Replace direct g_mqtt.disconnect() from web task with existing
    g_cfg_mqtt_reconfigure_required flag (PubSubClient not thread-safe).
    - Restore missing cfg/+/set MQTT subscription for remote config updates.
    - Fix screenshot lazy-load to use getAttribute('src') instead of
    img.src to avoid browser URL resolution on empty attribute.
    - Fix data race: use snapshotted temp_unit_f in web_handle_root and
    web_handle_status_get instead of reading g_cfg_temp_unit_f outside
    the mutex.
    - Fix wifi watchdog: t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
    [esp32_controller_main.cpp, esp32s3_thermostat_firmware.cpp, wifi_watchdog.h]
2026-03-04 Fix false isolation reboot, add integration test script
    The isolation watchdog was rebooting on transient MQTT drops because it
    checked an instantaneous condition (MQTT down right now + ESP-NOW stale)
    rather than tracking sustained isolation. A brief broker restart would
    trigger an immediate reboot even though connectivity would recover in
    seconds.
    Now tracks when isolation *starts* and only reboots after both MQTT and
    ESP-NOW have been continuously down for the full 15-minute threshold.
    Adds diagnostic logging with actual timestamps for debugging.
    Also adds scripts/integration-test.sh — a reusable HIL test suite that
    exercises both devices via web endpoints, verifying screenshot streami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
    [esp32s3_thermostat_firmware.cpp]
2026-03-08 Fix controller false isolation reboot (match thermostat fix)
    The controller still used the old instantaneous isolation check that
    rebooted immediately on any brief MQTT disconnect when ESP-NOW heartbeats
    were stale. Replace with sustained-isolation tracking that requires both
    channels to be down continuously for 15 minutes before rebooting.
    [esp32_controller_main.cpp]
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2026-03-09 refactor: replace controller per-device base topics with shared base_topic + MAC
    Replace mqtt_client_id, mqtt_base_topic, display_mqtt_base_topic, and
    unique_device_id config keys with base_topic, ha_discovery_enabled, and
    device_name. Legacy shim variables are computed from the new config to
    keep MQTT connect and HA discovery compiling until Tasks 3/4 update
    all callers.
    [esp32_controller_main.cpp]
2026-03-09 refactor: controller MQTT connect/subscribe/publish uses new topic paths
    - Replace all ctrl_topic_for() calls with self_topic_for()
    - Replace display_topic_for() subscriptions with device_topic_for("+", ...)
    - Restructure MQTT callback to parse {base}/devices/{MAC}/{suffix} topics
    - Peer device messages (announce, availability, sensor, packed_command)
    are handled by MAC extraction from topic path
    - Self topics (cmd/, cfg/) fall through to existing handlers
    - Replace device registry publish with announce payload format
    - Guard HA discovery with g_cfg_ha_discovery_enabled
    - Forward reset_sequence to first display via get_first_display_mac()
    - Remove legacy ctrl_topic_for, display_topic_for,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
    [esp32_controller_main.cpp]
2026-03-09 refactor: HA discovery payloads use new device topic paths
    Replace legacy shim variables (g_cfg_ctrl_mqtt_base_topic,
    g_cfg_unique_device_id) with inline construction from g_cfg_base_topic
    and g_cfg_device_mac. Use g_cfg_device_name for the HA device name
    instead of hardcoded "Furnace Controller". Update test constants to
    match the new {base}/devices/{MAC} topic format.
    [esp32_controller_main.cpp]
2026-03-09 refactor: display config, MQTT, and HA discovery use new topic structure
    Replace per-device base topics with shared base_topic + device MAC path
    structure (matching the controller refactor). Adds base_topic, device_name,
    ha_discovery_enabled, and paired_controller_mac config; removes mqtt_client_id,
    mqtt_base_topic, unique_device_id, and controller_base_topic. Topic helpers
    now use mqtt_topics.h for consistent path construction. HA discovery payloads
    use device_name and MAC-based node IDs. Sensor data publishes under own
    device path instead of controller namespace.
    [esp32s3_thermostat_firmware.cpp]
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2026-03-09 fix: BLE provisioning boot mode for fresh devices
    On a fresh device with no WiFi credentials, the display panel and LVGL
    consume nearly all internal SRAM, leaving insufficient memory for
    NimBLE initialization (~29KB free vs ~60KB needed). This caused an
    infinite boot loop (BLE_INIT: Malloc failed → guru meditation → reboot).
    Fix: detect empty WiFi SSID early in setup and enter a minimal
    provisioning boot mode that starts BLE before initializing the display.
    Shows a simple "WiFi Setup Required" screen with Improv instructions.
    Also fixes Improv error reporting: the onImprovConnected callback was
    rebooting before the library could send STATE_PROVISIONED and the
    device URL response. Now s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
    [esp32s3_thermostat_firmware.cpp]
2026-03-10 feat: add Reset WiFi button, remove unused cfg MQTT topics
    - Add "Reset WiFi" button to LVGL settings page for re-entering
    BLE provisioning mode without serial connection
    - Center text on all settings page action buttons
    - Remove cfg/+/set subscription and publish from both display
    and controller firmware (no longer used)
    [esp32_controller_main.cpp, esp32s3_thermostat_firmware.cpp]
2026-03-10 refactor: use full colon-separated MAC addresses, fix OTA reboot race
    Switch g_cfg_device_mac from shortened 3-byte suffix to full
    AA:BB:CC:DD:EE:FF format for ESP-NOW and web UI compatibility.
    Add g_cfg_device_mac_compact (no colons) for MQTT topics, HA discovery,
    and OTA hostnames where colons would break. Convert compact MACs back
    to colon format in device registry so the web UI device picker matches
    the HTML input pattern validation.
    Also fix OTA web updater rebooting before the HTTP response flushes by
    deferring ESP.restart() to ota_web_loop() with a 1.5s delay.
    [esp32_controller_main.cpp, esp32s3_thermostat_firmware.cpp, ota_web_updater.cpp]
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2026-03-10 feat: reliable display OTA via subsystem teardown, remove ArduinoOTA
    Remove ArduinoOTA (redundant with web OTA at /update) from both
    firmwares to simplify code and free ~1-2KB internal SRAM.
    Add full subsystem teardown when OTA starts on the display firmware:
    disconnect MQTT (~5-6KB), stop mDNS (~2-5KB), end I2C buses, turn off
    display and backlight. This raises free internal SRAM from ~13KB to
    ~23KB during OTA, preventing TCP connection drops that caused uploads
    to abort at 10-20%.
    Fix prepare callback thread-safety: remove PubSubClient calls from
    the web task (Core 0) since PubSubClient is used on Core 1. Teardown
    is now handled entirely in the main loop.
    Always reboot after OTA (succes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
    [esp32_controller_main.cpp, esp32s3_thermostat_firmware.cpp, ota_web_updater.cpp]
2026-03-10 fix: OTA reliability with active MQTT subscriptions, accept colon MACs in pairing
    Close the MQTT TCP socket (g_wifi_client.stop()) in the OTA prepare callback
    to free ~5-6KB of internal SRAM socket buffers before upload data arrives.
    Without this, OTA fails at ~10% with broken pipe when the display has active
    MQTT subscriptions. Also strip colons from paired_controller_mac input so
    users can paste either AA:BB:CC:DD:EE:FF or AABBCCDDEEFF format.
    [esp32s3_thermostat_firmware.cpp]
2026-03-10 fix: safety guards for millis overflow, touch div-by-zero, mutex alloc
    - Use unsigned millis() comparison for reboot/backlight scheduling in
    both firmwares (signed int32_t cast fails after ~24.8 days uptime)
    - Guard touch coordinate scaling against division by zero if GT911
    reports 0 resolution
    - Abort boot with restart if g_api_mutex allocation fails (prevents
    null dereference on every mutex take)
    [esp32_controller_main.cpp, esp32s3_thermostat_firmware.cpp]
2026-03-10 fix: use std::atomic for weather task heartbeat instead of volatile
    volatile does not provide memory ordering guarantees in C++. The
    heartbeat is written by the weather task (Core 0) and read by the
    main loop (Core 1) for watchdog detection.
    [esp32_controller_main.cpp]
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
